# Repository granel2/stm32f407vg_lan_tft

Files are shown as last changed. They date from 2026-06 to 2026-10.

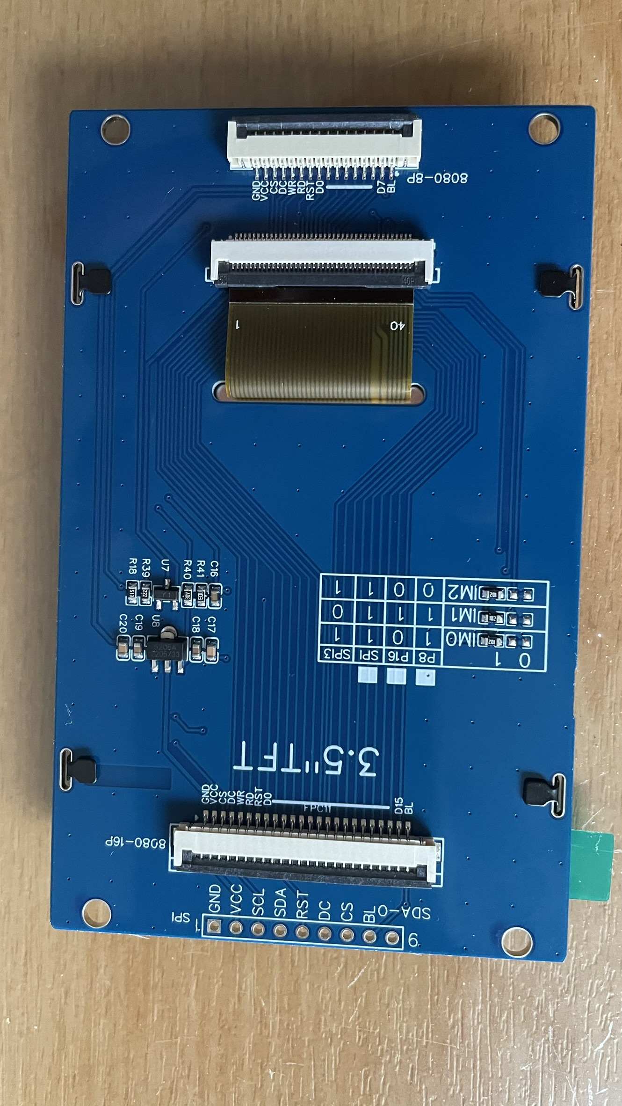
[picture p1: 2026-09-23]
Display/docs/tft_board_back.jpg

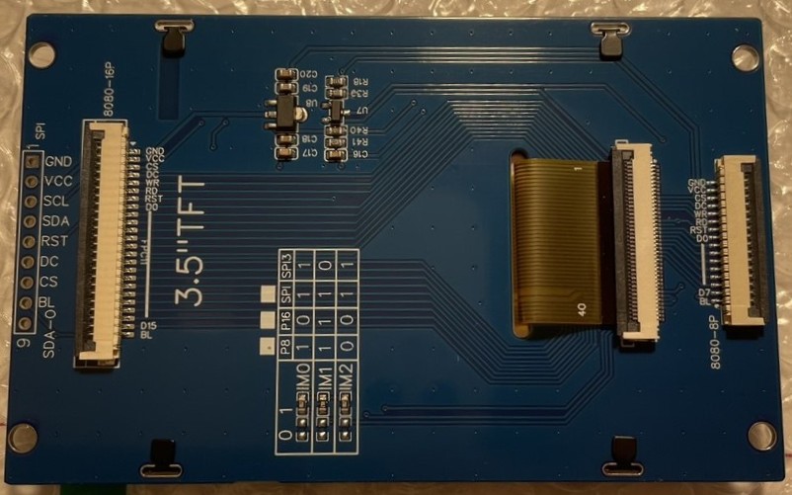
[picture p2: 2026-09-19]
Display/docs/display_3.5_tft_front.jpg

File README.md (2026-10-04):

# stm32f407vg_lan_tft

STM32F407VGT6 + LAN8720 (Ethernet, lwIP, DHCP, TCP-клиент) + 3.5" TFT-дисплей.
Проект основан на `stm32f407vg_lan_v1` (Ethernet-часть отлажена и работает, см. `docs/`).

## Структура

| Путь | Что это |
|---|---|
| `Core/Inc`, `Core/Src`, `Core/Startup` | Ethernet/lwIP-часть: HAL MSP, прерывания, lwIP-порт (`ethernetif.c`), TCP-клиент, `main.c` |
| `Display/` | Весь дисплейный модуль, обособлен от Ethernet-кода — см. `Display/README.md` |
| `Config/` | Постоянные настройки (сервер/имя/статический IP) + веб-страница настройки `http://<IP модуля>/` (порт 80) + TCP-конфигуратор на порту 7000 — см. `Config/README.md` |
| `Keypad/` | Приём пакетов от модуля клавиатуры 4×4 (ATmega328P) на SV5: I2C1-ведомый `0x30`, на регистрах — см. `Keypad/README.md` |
| `Drivers/` | STM32Cube HAL F4 V1.28.3, CMSIS, драйвер PHY lan8742 |
| `Middlewares/Third_Party/LwIP` | lwIP (NO_SYS=1) |
| `CMakeLists.txt`, `CMakePresets.json`, `toolchain-arm-none-eabi.cmake`, `linker_script.ld` | Сборка |
| `stm32f407vg_lan_tft.ioc`, `.mxproject` | Проект CubeMX — **только справочно**: ETH и часть периферии добавлены руками, перегенерировать код из CubeMX нельзя |
| `hardware/` | `BOARD.md` — выжимка по плате (разъёмы, питание, выводы); схема и плата (Eagle) `f407.sch`/`f407.brd`, распечатка схемы `f407_schematic_A3.pdf` |
| `docs/` | История отладки Ethernet (`PROJECT_GUIDE.md`), аппаратный фикс LAN8720 (`CHANGES_LAN8720.md`), заметки по сборке, даташиты |
| `stm32f407vg_lan_tft.code-workspace` | Workspace VS Code |

## Целевая платформа

- MCU STM32F407VGT6 (LQFP100), HSE 25 MHz, SYSCLK 160 MHz, APB1 40 MHz, APB2 80 MHz
- USART1 (PA9/PA10) и USART3 (PD8/PD9), 921600 baud — отладочный лог
- ETH RMII → LAN8720 (REFCLK на PA1), см. `docs/CHANGES_LAN8720.md` про обязательный резистор 1 кОм на страпе nINTSEL
- LED: PB4, PB5, PD0, PD1, PD4, PD7

## Сборка

Требуется `arm-none-eabi-gcc`, `cmake ≥ 3.24`, `ninja`, `openocd` в `PATH`.

```powershell
cmake --preset default          # конфигурация (build/, Ninja, toolchain-файл)
cmake --build --preset default  # сборка → build/stm32f407vg_lan_tft.{elf,bin,hex,map}
```

В VS Code: `Terminal → Run Task → CMake: Configure`, затем `CMake: Build` (Ctrl+Shift+B).

## Прошивка и отладка

- Задача VS Code `Flash STM32F407VG` — `scripts/flash-progress.ps1`, обёртка над той же
  последовательностью OpenOCD (`init` → `reset halt` → `mass_erase` → `write_image` →
  `verify_image` → `reset run`; ST-Link). Команда `program … verify` в текущей сборке
  OpenOCD глючит — подробности в `docs/PROJECT_GUIDE.md`, поэтому по-прежнему используется
  явная последовательность, а не `program`. Обёртка добавляет текстовую шкалу прогресса
  в терминал (OpenOCD сам не печатает прогресс во время записи, только итог) — она
  ориентируется на время (калибровка ~20 с под текущий размер прошивки), реальный вывод
  OpenOCD печатается полностью после завершения.
- Есть составная задача `Build + Flash` (сборка + прошивка одной командой,
  `.vscode/tasks.json`); запускать через `Ctrl+Shift+P` → `Tasks: Run Task`. `F5`
  (Run and Debug) тоже сначала пересобирает — см. `preLaunchTask` в `launch.json`.
  Личные горячие клавиши на конкретные задачи — дело вкуса, настраиваются в
  `keybindings.json` пользователя (VS Code не поддерживает keybindings, привязанные
  к конкретному проекту, поэтому в репозитории их нет).
- Отладка: конфигурация `Cortex Debug (ST-Link)` в `launch.json` (расширение `marus25.cortex-debug`).

## TFT 3.5" ST7796S (320×480), 4-wire SPI

Весь дисплейный код, схема подключения и фото платы вынесены в **[`Display/`](Display/)** —
отдельный, не зависящий от Ethernet-части модуль, чтобы его можно было дорабатывать
(шрифты, экран сетевого статуса) не трогая `main.c`. Подробности, распиновка и порядок
включения — в [`Display/README.md`](Display/README.md).

Коротко: SPI3 (PC10/PC11/PC12, 20 МГц) + CS/DC/RST/BL на PA15/PD6/PD5/PC7, всего 2 разъёма
(SV4 + SV1). При старте `TFT_App_SmokeTest()` заливает экран R/G/B (время кадра — в USART1) и рисует тест-паттерн, затем показывает
рабочий экран статуса сети (IP/DHCP/TCP/последнее сообщение от сервера).

## Что дальше

Актуальные чек-листы — в README каждого модуля: [`Display/README.md`](Display/README.md)
(дисплей, шрифт, многостраничный экран) и [`Config/README.md`](Config/README.md)
(TCP-конфигуратор, статический IP).

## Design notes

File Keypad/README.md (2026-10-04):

# Keypad — приём пакетов от модуля клавиатуры 4×4

Модуль клавиатуры (ATmega328P, проект `..\..\atm328p_keyboard`) подключается к разъёму
**SV5** и сам передаёт пакеты по I²C. Эта плата — **ведомый `0x30`** на I2C1, только
принимает. Опроса и таймера нет: в простое процессор модулем не занят.

## Подключение

| SV5 | Сигнал | Модуль клавиатуры (Pro Mini) |
|---|---|---|
| 1 | GND | GND |
| 2 | +5V | RAW |
| 3 | SDA PB7 | A4 |
| 4 | SCL PB6 | A5 |

Подтяжки 4,7 кОм к +5 В стоят на модуле; на этой плате подтяжек нет, внутренние выключены
(PB6/PB7 — FT). ES0182 2.10.6: при VDD = 3,3 В шина допустима до 5,14 В (у модуля 5,02 В).
Скорость 100 кГц задаёт модуль.

## Протокол

`Inc/kbd_protocol.h` — **копия** `atm328p_keyboard/include/protocol.h`, держать одинаковыми.
Кадр: `[тип][seq][N][данные N][CRC-8][хвост '$']`.

- **Подтверждение — ответ на хвост.** ACK байта F4 ставит аппаратно до того, как программа
  его увидит (ES0182 2.10.2), поэтому решение по CRC отдаётся на следующий байт — хвост:
  ACK = пакет принят, NACK = модуль повторит через 10 мс.
- **Срок решения — 8 бит хвоста (~80 мкс).** Удержание SCL у F4 наступает только после ACK
  следующего байта, поэтому прерывание I2C1 с приоритетом **1** (выше ETH 5), CRC
  считается по ходу приёма, по байту CRC — только сравнение. Счётчик `late` в статистике
  должен оставаться 0.
- **После NACK флаг STOPF не ставится** (RM0090), бит ACK возвращается в RXNE отвергнутого
  байта и, для страховки, в `keypad_poll()` при свободной шине.
- **Повтор с тем же seq** (модуль не получил наш ACK) отбрасывается, пропуск seq пишется в лог.
  Пакет `START` (после сброса модуля) начинает нумерацию заново.

## Типы пакетов

| Тип | Данные | Лог (USART1) |
|---|---|---|
| `GROUP` 0x02 | `[причина][символы 0-9, A-D]` | `[kbd] #5 GROUP enter: "1A2B"` |
| `CANCEL` 0x03 | `[причина]` | `[kbd] #6 CANCEL timeout` |
| `KEY` 0x01 | `[бит 7 нажата + ASCII]` — только если модуль собран с `LETTERS_KEY` | `[kbd] #7 KEY A down` |
| `START` 0x04 | `[версия ПО][MCUSR]` | `[kbd] #1 START fw 2, reset cause MCUSR 0x01` |

Причины: 1 `#`, 2 предельная длина (16), 3 пауза (10 с), 4 `*`.
MCUSR: 0x01 питание, 0x02 RESET, 0x04 просадка питания, 0x08 сторожевой таймер.

## Использование

```c
static void on_keypad(const KeypadPacket *p)
{
  if (p->type == KBD_PKT_GROUP && p->data[0] == KBD_END_ENTER)
  {
    /* p->data[1..p->len-1] - набранные символы, p->len - 1 штук */
  }
}
...
keypad_set_handler(on_keypad);
```

Обработчик вызывается из `keypad_poll()` (главный цикл), не из прерывания. После него
пакет в очереди затирается — пароль в памяти не остаётся.

## Страница дисплея «I2C KBD»

Кнопкой страниц (PC6) выбирается страница `I2C KBD 0x30`. На ней по строке на каждый принятый
пакет, новые снизу; когда 18 строк заполнены, список прокручивается. Строки копятся и тогда,
когда открыта другая страница.

В заголовке — адрес STM32 на шине клавиатуры (`I2C KBD 0x30`). Строка под ним — счётчики:
`RX` — сколько раз к этому адресу обратились (передач), `OK` — принятые пакеты,
`ERR` — CRC + оборванные кадры + ошибки шины (BERR/ARLO/OVR). Норма: `RX` = `OK`, `ERR 0`.
`RX 0` при работающем модуле — модуль до STM32 не доходит (проводка, SDA/SCL, подтяжки)
или в модуле не та прошивка (`uarttest` в I²C не пишет).

| Строка | Цвет | Что |
|---|---|---|
| `#12 E 1234567890` | зелёный | GROUP; конец: `E` — `#`, `M` — 16 символов, `T` — пауза, `C` — `*` |
| `#13 CANCEL TIMEOUT` | жёлтый | CANCEL и причина |
| `#1 START FW 2 RST 02` | голубой | сброс модуля, MCUSR |
| `#7 KEY A DOWN` | белый | KEY (модуль собран с `LETTERS_KEY`) |
| `LOST 2`, `CRC 3 LATE 0` | красный | пропуск seq, изменились счётчики ошибок |

При `KEYPAD_LOG_TEXT 0` вместо символов группы — их число.

Следующая страница, `KBD HELP`, — краткая расшифровка этих строк на самом дисплее.

## Листание страниц с клавиатуры

Обработчик в `Core/Src/main.c` (`on_keypad()`): `#` без символов — следующая страница,
1–3 цифры и `#` (`3#`, `12#`) — страница с этим номером (как в индикаторе `n/N`); номер,
которого нет, игнорируется. Всё остальное — обычный ввод: пароли не короче 4 цифр или
начинаются с буквы, с командами не пересекаются. Цифры идут **перед** `#`: модуль
отправляет группу только по `#`.
Кнопка страниц (PC6) работает как раньше.

## Настройки — `Inc/keypad_config.h`

| Параметр | По умолчанию | |
|---|---|---|
| `KEYPAD_IRQ_PRIORITY` | 1 | приоритет I2C1_EV/ER; должен быть выше остальных |
| `KEYPAD_LOG_TEXT` | 1 | 1 — печатать набранное, 0 — только число символов (для паролей) |
| `KEYPAD_QUEUE_LEN` | 8 | пакетов между прерыванием и главным циклом |

## Файлы

| Файл | Что это |
|---|---|
| `Inc/keypad.h`, `Src/keypad.c` | Драйвер I2C1-ведомого на регистрах (HAL I2C в проекте не включён) |
| `Inc/keypad_config.h` | Настройки |
| `Inc/kbd_protocol.h` | Протокол, копия из проекта клавиатуры |
| `Inc/keypad_page.h`, `Src/keypad_page.c` | Страница дисплея «I2C KBD» (вызывается из `Display/Src/tft_app.c`) |

Связь с остальным: `main.c` — `keypad_init()` при старте и `keypad_poll()` в главном
цикле; `stm32f4xx_it.c` — `I2C1_EV_IRQHandler` / `I2C1_ER_IRQHandler`.

## Состояние

Собирается; на железе **не проверено** (2026-10-04). Журнал решений по протоколу —
`atm328p_keyboard/docs/DECISIONS.md`.

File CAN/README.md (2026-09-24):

# CAN — драйвер CAN1

## Железо

| Что | Где |
|---|---|
| Контроллер | bxCAN **CAN1**, PA11 = RX, PA12 = TX (AF9) |
| Трансивер | U3 **TCAN1044V**, STB → R1 10k на GND (всегда активен), VIO = 3V3, VCC = +5V |
| Разъём | **J3** (4 pin): 1 GND, 2 CANL, 3 CANH, 4 +5V |
| Терминатор | R2/R30 2×49.9 Ом (split, 120 Ом) — впаян постоянно: модуль должен стоять **на конце шины** |
| Защита | D4 PESD1CAN |

Подробнее — `hardware/BOARD.md`.

## Файлы

| Файл | Что делает |
|---|---|
| `Inc/can_config.h` | Скорость, режим «только слушать», лог, размер очереди |
| `Inc/can_bus.h`, `Src/can_bus.c` | Драйвер на регистрах bxCAN (HAL CAN в проекте нет) |

## Настройки (`can_config.h`)

| Define | По умолчанию | Что делает |
|---|---|---|
| `CAN_BITRATE_KBPS` | 500 | Скорость; делитель считается от реальной частоты APB1 (40 МГц), точка выборки ~87,5 % |
| `CAN_SILENT` | 0 | 1 = только слушать: модуль не шлёт ACK и ошибки, не передаёт — безопасно для чужой шины |
| `CAN_LOG_MAX_PER_S` | 20 | Сколько принятых кадров в секунду печатать в UART (печать блокирующая) |
| `CAN_STATS_PERIOD_S` | 10 | Сводка раз в N секунд (только если что-то было) |
| `CAN_RX_QUEUE_LEN` | 32 | Очередь между прерыванием и главным циклом |

## Как работает

- `can_bus_init()` при старте: тактирование, ножки, тайминги, фильтр «принимать всё»
  (стандартные и расширенные кадры) в FIFO0, прерывание приёма.
- Прерывание `CAN1_RX0` перекладывает кадры из аппаратного FIFO (3 кадра) в очередь.
- `can_bus_poll()` в главном цикле: печатает кадры в UART, отдаёт каждый в обработчик
  приложения (`can_bus_set_rx_handler()`), сообщает о смене состояния шины.
- `can_bus_send()` кладёт кадр в свободный аппаратный почтовый ящик (их 3) и сразу
  возвращается. **Сейчас прошивка сама ничего не передаёт** — функция есть, вызова нет.
- Bus-off восстанавливается аппаратно (ABOM); автоматический повтор передачи включён.

## Что видно в UART

```
[can] CAN1 up: 500 kbit/s (APB1 40 MHz, presc 5, 16 tq), normal mode
[can] state OFF -> ACTIVE (tec 0 rec 0)
[can] rx 123 [8] 11 22 33 44 55 66 77 88
[can] rx 18FF0102 [4] 01 00 FF 7F        ← расширенный (29-bit) ID
[can] ... 340 more frames not logged      ← если больше CAN_LOG_MAX_PER_S в секунду
[can] 10 s: rx 3520 tx 0 lost 0 | total rx 3520, ACTIVE tec 0 rec 0
```

`lost` — кадры, потерянные из-за переполнения FIFO или очереди.
Если при старте `did not leave init mode` — линия RX держится в доминанте: проверьте
питание +5V трансивера и проводку J3.

## Пример передачи

```c
CanFrame f = { .id = 0x123, .ext = 0, .rtr = 0, .len = 2, .data = { 0xAB, 0xCD } };
if (!can_bus_send(&f)) { /* все 3 ящика заняты или режим CAN_SILENT */ }
```

Без второго узла на шине кадр не получит ACK, контроллер будет повторять его, счётчик
ошибок TEC вырастет, и шина уйдёт в ERROR-PASSIVE — это нормально для одиночного узла.

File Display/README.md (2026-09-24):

# Display — 3.5" ST7796S TFT (320×480), 4-wire SPI

Самодостаточный модуль: весь код и вся документация по дисплею лежат здесь, отдельно
от Ethernet/lwIP-части в `Core/`. Задуман так, чтобы дальнейшую доработку экрана
(новые виджеты, другие экраны) можно было вести, трогая только эту папку — `main.c`
знает только о четырёх функциях (см. «Слои кода» ниже).

## Структура

| Путь | Что это |
|---|---|
| `Inc/st7796s.h`, `Src/st7796s.c` | Низкоуровневый драйвер контроллера ST7796S: init-последовательность, RAMWR/CASET/RASET, заливки, поворот (MADCTL), примитив 7-сегментных цифр, битмап-шрифт 5x7 (`ST7796S_DrawChar`/`DrawString`). Не знает ни о плате, ни о приложении. |
| `Inc/tft_app.h`, `Src/tft_app.c` | Прикладной слой: владеет `hspi3`, настраивает SPI3 и GPIO CS/DC/RST/BL/кнопки, решает, что и когда рисовать (boot-смоук-тест, многостраничный экран статуса). **Это файл для доработки** — новые страницы/виджеты добавлять сюда. |
| `docs/TFT_WIRING.md` | Пины модуля ↔ STM32 ↔ разъёмы платы (SV4 + SV1), проверка перед включением. |
| `Inc/tft_backlight.h`, `Src/tft_backlight.c` | Яркость подсветки: ШИМ на PC7 (TIM3_CH2), уровень в % воспринимаемой яркости (скважность = %²/100). Уровни и приглушение в покое — на веб-странице настроек (`device_config`: `bl_level`, `bl_dim_level`, `bl_dim_min`), применяются сразу. |
| `docs/TFT_3.5_board.md` | Описание платы-адаптера дисплея: разъёмы 40-pin FPC/8080-8P/8080-16P/9-pin SPI, таблица перемычек IM0–IM2, питание (LDO U8, транзистор подсветки U7). |
| `docs/LARGE_DISPLAY_OPTIONS.md` | Какой дисплей максимум можно подключить (до 10,1" 1280×800 с «умным» контроллером), почему 1920×1080 только через Raspberry Pi + браузер. Теория, не реализовано. |
| `docs/display_3.5_tft_front.jpg` | Фото модуля спереди. |
| `docs/tft_board_back.jpg` | Фото платы-адаптера сзади — читаемая ориентация, с таблицей перемычек IM. |

## Слои кода

```
main.c
  │  TFT_App_GPIO_Init()                        — сразу после MX_GPIO_Init(), до всего остального
  │  TFT_App_SPI3_Init()                       ─┐  один раз при старте, до MX_LWIP_Init() —
  │  TFT_App_SmokeTest()                       ─┘  блокирующие HAL_Delay() не должны стопорить DHCP/ETH
  │  TFT_App_AlivePoll(ip_str, link_up, ip_src, tcp)   — каждую итерацию while(1), сам ограничивает себя 1 Гц;
  │                                               main.c передаёт то же состояние netif/TCP, что уже
  │                                               считает для UART-heartbeat
  ▼
Display/Src/tft_app.c  (прикладной слой, PC10/11/12 + PA15/PC7/PD5/PD6)
  ▼
Display/Src/st7796s.c  (низкоуровневый драйвер контроллера)
```

`Debug_Print()` (лог в USART1) остался в `main.c`, объявлен в `main.h` — им пользуются
и Ethernet-код, и `tft_app.c`.

## Подключение — коротко

9-контактный разъём SPI на плате-адаптере → плата f407, всего **2 разъёма** (SV4 + SV1) —
DC/RST/BL сгруппированы на SV1, чтобы не тянуть провода к третьему разъёму
(подробности и проверка перед включением — в [`docs/TFT_WIRING.md`](docs/TFT_WIRING.md)):

| Модуль (9-pin SPI) | STM32 | Разъём платы |
|---|---|---|
| GND | GND | SV4.6 |
| VCC | +5V (если на модуле есть LDO) / +3V3 | SV4.5 / SV2.1 |
| SCL | PC10 SPI3_SCK | SV4.3 |
| SDA | PC12 SPI3_MOSI | SV4.1 |
| SDA-O | PC11 SPI3_MISO | SV4.2 (нужен только для чтения ID) |
| CS | PA15 (GPIO) | SV4.4 |
| BL | PC7 — ШИМ TIM3_CH2, 10 кГц (яркость) | SV1.8 |
| RST | PD5 | SV1.9 |
| DC | PD6 | SV1.10 |
| BTN (кнопка страниц) | PC6, на GND | SV1.7 |

BL/RST/DC/BTN — четыре соседних пина SV1 (7/8/9/10), компактный жгут из четырёх проводов.
PC6/PC7/PD5/PD6 на этой плате подписаны как USART6/USART2 TX-RX (см. `hardware/BOARD.md`),
но ни один из этих UART в прошивке не занят — тот же случай, что и раньше с PB8 под BL. PC6
и PC7 сидят на порту GPIOC, который иначе в проекте не включается — `TFT_App_GPIO_Init()`
сам включает его тактирование. Кнопка — один вывод на PC6, второй на GND (например,
SV4.6); подтяжка к +3.3 В внутренняя, программная (`GPIO_PULLUP`), внешний резистор не
нужен.

**Перемычки IM0/IM1/IM2 на плате-адаптере** должны стоять в положении **SPI (4-wire)**
= `IM2=1, IM1=1, IM0=1`. **Проверено по фото `docs/tft_board_back.jpg`: на этом
экземпляре уже впаяны в `1/1/1`** — режим SPI, перепаивать не требуется. Таблица
режимов — в [`docs/TFT_3.5_board.md`](docs/TFT_3.5_board.md).

## Контроллер: ST7796S (подтверждено косвенно, RDID4 ненадёжен)

Плата-адаптер не подписана; по разводке 40-pin FPC она совпадает и с ST7796S, и с
ILI9488. Драйвер (`st7796s.c`) целиком написан под ST7796S — командный набор
разблокировки (`0xF0/0xC3/0x96`), таблицы гаммы (`0xE0/0xE1`), `COLMOD=0x55`
(16 бит/пиксель). Для настоящего ILI9488 по SPI это, как правило, **не сработает
корректно** — тот обычно не принимает 16bpp по последовательному интерфейсу и требует
18bpp (`COLMOD=0x66`, 3 байта/пиксель), да и часть регистров инициализации у него другая.

На реальном железе `RDID4` вернул мусор (`00 3B CB 00` — не 0/FF, похоже на наводку на
плавающем SDA-O), но **геометрия отрисовалась полностью корректно**: заливки R/G/B/белый
менялись без искажений, тест-паттерн ровный во всех 4 поворотах, финальный экран (полосы +
шахматка + серый блок со счётчиками) — всё как задумано по форме и расположению. (Отдельно
от этого была найдена и исправлена инверсия цветов — см. ниже; на геометрию/паттерн она не
влияла, поэтому вывод о совместимости с ST7796S по-прежнему в силе.) Если бы чип был
настоящим ILI9488, при 16bpp/чужой гамме картинка почти наверняка была бы битой —
раз она чистая, контроллер ST7796S-совместим. `RDID4` можно перепроверить (перепаять/
прозвонить SDA-O — PC11/SV4.2) при желании, но для работы это не требуется.

## Многостраничный экран статуса

После смоук-теста (заливки + 4 поворота тест-паттерна) экран переключается на рабочий,
многостраничный режим. Кнопка на **SV1.7/PC6** (на GND, внутренняя подтяжка) листает
страницы по кругу; текущая страница видна в правом верхнем углу как `n/N`. Каждая
страница — свой заголовок (жёлтым) + `n/N`; heartbeat-квадратик внизу слева мигает
раз в секунду **на любой странице** — по нему видно, что прошивка жива, даже если вы
сейчас смотрите не на ту страницу, где что-то могло зависнуть.

| # | Страница | Что показывает |
|---|---|---|
| 1/4 | **SETUP** | `LINK / DHCP / IP / SERVER / TCP / UPTIME / FRAME / CHIP ID / NAME` |
| 2/4 | **RECEIVED** | Последнее сообщение от TCP-сервера целиком, многострочно |
| 3/4 | **REMOTE** | Приборы с данными от сервера: 2 стрелочных, 3 цифровых, 2 ползунка, 4 лампы — модуль [`Panel/`](../Panel/README.md) |
| 4/4 | **LOCAL** | Локальные приборы и органы управления: 3 столбика, стрелочный, цифровой, 4 кнопки, ползунок — [`Panel/`](../Panel/README.md) |

Пока реальных данных нет, REMOTE/LOCAL показывают **демо-анимацию** (внизу `SERVER: DEMO` /
`LOCAL: DEMO`). Добавить ещё страницу: завести `TFT_PAGE_XXX` в `enum TFT_Page` (перед `TFT_PAGE_COUNT`,
он посчитается сам), написать `draw_page_xxx_static(void)`, добавить `case` в
`draw_page_static()`; если странице нужны поля, обновляющиеся раз в секунду — добавить
`if (s_page == TFT_PAGE_XXX) { ... }` в `TFT_App_AlivePoll()` рядом с уже существующим
блоком для SETUP.

### Кнопка переключения страниц

PC6 (SV1.7), активный уровень низкий, подтяжка к +3.3 В — внутренняя программная
(`GPIO_PULLUP` в `TFT_App_GPIO_Init()`), внешний резистор не нужен: один вывод кнопки на
PC6, второй на GND. Антидребезг — по времени (`BTN_DEBOUNCE_MS` = 50 мс: изменение
состояния принимается не чаще этого интервала), проверяется **каждую итерацию** главного
цикла (а не раз в секунду) — переключение страницы происходит мгновенно по нажатию, без
задержки до 1 с.

### Страница SETUP

`LINK/DHCP/IP/SERVER/TCP/UPTIME/FRAME/CHIP ID/NAME`, метка слева/значение справа, шрифт
5x7. `SERVER:`/`FRAME:`/`CHIP ID:`/`NAME:` статичны — рисуются один раз при возврате на
страницу. `SERVER:` и `NAME:` теперь приходят из `Config/Inc/device_config.h` (постоянные
настройки, см. `Config/README.md`) — `main.c` читает их через `device_config_get()` и
передаёт строками в `TFT_App_SmokeTest()`, чтобы `Display/` по-прежнему не подключал ни
lwIP-, ни Config-заголовки напрямую. После сохранения новых настроек (веб-страница или
TCP-конфигуратор) `main.c` замечает смену `device_config_revision()` и вызывает
`TFT_App_UpdateInfo()` — `SERVER:`/`NAME:` обновляются на экране сразу, без перезагрузки
(если SETUP сейчас не на экране — при следующем возврате на неё). Остальные поля обновляет `TFT_App_AlivePoll()` раз
в секунду, **только пока активна эта страница** — вызывается из `main.c` там же, где уже
считается `has_ip`/состояние TCP для UART-heartbeat, никакого дублирования логики.
Каждое значение рисуется в поле фиксированной ширины (`STATUS_VALUE_CHARS`), так что
более короткое новое значение полностью перекрывает старое.

**`NAME:`** — имя/метка устройства, настраивается по сети без пересборки прошивки: через
веб-страницу `http://<IP модуля>/` или TCP-конфигуратор (`SET NAME ...`), см.
`Config/README.md`.

**`CHIP ID:`** — **CRC32** от уникального 96-битного заводского номера чипа (STM32F4:
OTP-регистр по фиксированному адресу `0x1FFF7A10`, см. RM0090 §39.1 «Unique device ID
register», `stm32_uid_word()`/`stm32_uid_crc32()` в `tft_app.c` — обычное чтение памяти,
без периферии/инициализации). Статичен, как `SERVER:`/`FRAME:` — заводской номер не
меняется в рантайме.

Показывается именно CRC32 (8 hex-символов, влезает в одну строку), а не все 24 символа
сырого ID: во-первых, не влезает в 16-символьное поле значения (пришлось бы разбивать на
2 строки); во-вторых, часть 96 бит (поле `LOT_NUM` — номер производственной партии) у ST
часто кодируется как читаемый десятичный/ASCII-подобный текст, а не как случайные биты
(отсюда и вопрос — на экране был подозрительно «ровный» номер без единой буквы A-F), так
что CRC32 заодно превращает его в равномерно распределённое короткое значение, удобное
как компактный идентификатор платы. Использован стандартный отражённый CRC-32 (полином
`0xEDB88320`, тот же алгоритм, что `zlib.crc32()`/`binascii.crc32()` в Python/`cksum`) —
можно независимо перепроверить по 24-значному сырому ID, который печатается в лог USART1
при старте вместе с CRC32: `[tft] chip UID = <24 hex> (CRC32 <8 hex>)`.

Для идентификации платы на сервере используйте именно этот CRC32 (или сырой 96-битный
ID из лога), а не MAC-адрес: он сейчас жёстко прошит одинаковым для всех плат с этой
прошивкой (`ETH_MAC_ADDR0..5` в `Core/Inc/stm32f4xx_hal_conf.h`, сейчас
`02:00:00:00:00:01`) — при нескольких платах в одной сети будет MAC-коллизия, если не
поменять байт вручную под каждую плату. IMEI не применим — на плате нет сотового модема.

### Страница RECEIVED

Последнее, что реально пришло от сервера по TCP — **целиком**, а не только первая строка:
разбивка по переносам строк сервера (CR/LF), каждая строка при необходимости ещё и
заворачивается по ширине экрана (`STATUS_RX_CHARS` символов) — до `STATUS_RX_MAX_ROWS`
(сейчас 18) строк; всё, что не поместилось, отбрасывается. Текст **не гаснет сам** (в
отличие от прежней версии на общем экране) — держится, пока не придёт новое сообщение;
страница целиком отдана этому, автогашение через 2 с больше не нужно. Если новое
сообщение короче предыдущего — лишние строки снизу гасятся отдельно (`s_rx_rows_used`),
не остаётся «хвостов». Байты вне алфавита шрифта (буквы/цифры/`. : - / ! #`, без
кириллицы) рисуются пустыми клетками — не мусором.

Сообщение хранится в `s_last_msg` (сырой текст, ещё не завёрнутый), поэтому переключение
на эту страницу всегда показывает последнее пришедшее, даже если оно прилетело, пока была
открыта другая страница (`TFT_App_ShowReceived()` перерисовывает страницу немедленно,
только если она активна; иначе просто запоминает — отрисовка произойдёт при следующем
переключении сюда). Буфер под приём: `LAST_RX_SNAPSHOT_SIZE` в `tcp_echo_client.c` (220
байт) и `rx_snapshot` в `main.c` (тот же размер) — сообщение с кириллицей в UTF-8
(2 байта/символ) уже занимает ~100 байт, оставлен запас.

Список меток и позиций для всех страниц — в начале `tft_app.c` (`STATUS_Y_*`,
`STATUS_LABEL_X`, `STATUS_VALUE_X`).

## Что дальше

- [x] Аппаратный тест (init, ID, заливка, паттерн, live-счётчики) — подтверждено на
      реальном железе, геометрия/паттерн корректны
- [x] Дисплейный код выделен в самостоятельный модуль (`Display/`)
- [x] Контроллер подтверждён как ST7796S-совместимый (косвенно, по корректной геометрии)
- [x] Шрифт — битмап 5x7 (`ST7796S_DrawChar`/`ST7796S_DrawString` в `st7796s.c`):
      пробел, `. : - / ! #`, цифры, заглавные и строчные латинские буквы; неизвестный
      символ (в т.ч. кириллица) рисуется пустой клеткой, а не мусором
- [x] Экран сетевого статуса (IP, link, DHCP, TCP, последнее TCP-сообщение) — см. раздел выше
- [x] **Инверсия цветов** — на реальном железе все цвета выходили ровно инвертированными
      (жёлтый↔синий, циан↔красный, белый фон вместо чёрного). Исправлено:
      `CMD_INVON` → `CMD_INVOFF` в `ST7796S_Init()` (`st7796s.c`)
- [x] **Обрезка нижних строк экрана статуса** — после цикла проверки 4 поворотов
      (`TFT_App_SmokeTest()`, шаг 3) ориентация оставалась в `rotation=3`
      (`tft_height=320`, а не 480), и экран статуса рисовался поверх этого без сброса —
      всё ниже y≈320 (строка `LAST MSG:` и heartbeat-квадрат) обрезалось или пропадало.
      Исправлено: явный `ST7796S_SetRotation(0U)` перед `status_draw_static()`
- [x] Все три фикса выше (инверсия, шрифт, сброс поворота) проверены на реальном
      железе одним фото: правильные цвета, полная читаемая строка `Hello Module #49 ! I
      am` в `LAST MSG:` (строчные буквы и `#`/`!` отрисовались), heartbeat-квадрат на
      месте, экран не обрезан. Кратковременный «повёрнутый на 90°» вид, который
      наблюдался сразу после прошивки, — это самопроверка `TFT_App_SmokeTest()`,
      прогоняющая тест-паттерн во всех 4 поворотах в первые ~5 с после сброса; не баг
- [x] Полный многострочный ответ сервера в `LAST MSG:` (перенос по строкам + по ширине
      экрана) — подтверждено на реальном железе, всё сообщение видно целиком
- [x] Многостраничный экран (SETUP / RECEIVED / RESERVED), переключение кнопкой на
      PC6/SV1.7 (антидребезг по времени, проверка каждую итерацию цикла — переключение
      мгновенное). RECEIVED теперь занимает всю страницу (до 18 строк вместо 7) и не
      гаснет сама по таймеру — держится до следующего сообщения. Heartbeat-квадрат общий
      для всех страниц. Кнопка и переключение всех трёх страниц подтверждены на
      реальном железе
- [x] Уникальный ID чипа на SETUP — CRC32 (8 hex) от 96-битного заводского номера
      (OTP `0x1FFF7A10`); рекомендован для идентификации на сервере вместо MAC (сейчас
      захардкожен одинаковым для всех плат) —
      собрано и прошито, визуальная проверка на реальном железе — ожидается
- [ ] Содержимое страницы 3 (сейчас заглушка «RESERVED») и любые новые страницы —
      по мере необходимости, механизм уже готов (см. «Многостраничный экран статуса» выше)
- [ ] Кириллица / больше пунктуации в шрифте, если понадобится другой текст

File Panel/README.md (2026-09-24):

# Panel — страницы приборов на TFT

Дополнение к экрану [`Display/`](../Display/README.md): две страницы с кнопками, лампами,
цифровыми и стрелочными приборами, ползунками и столбиками. Листаются той же кнопкой
(PC6), что и SETUP / RECEIVED: **SETUP → RECEIVED → REMOTE → LOCAL**.

Сейчас это **примеры изображения**: раскладка и типы приборов — образец, значения
анимирует встроенное демо. Что именно показывать и откуда брать данные — решается дальше
(формат данных от сервера, локальные входы, органы управления — см. «Что решить»).

## Страницы

**REMOTE** — значения, приходящие с удалённого сервера:

```
┌──────────────────────────────────────┐
│ REMOTE                          3/4  │
│ ┌─PRESSURE─────┐ ┌─SPEED────────┐    │   2 стрелочных прибора
│ │   ╭──────╮   │ │   ╭──────╮   │    │   (шкала 240°, зоны норма/внимание/авария)
│ │  ╱   ╲    ╲  │ │  ╱    ╱   ╲  │    │
│ │    5.3 BAR   │ │   1500 RPM   │    │
│ └──────────────┘ └──────────────┘    │
│ [TEMP  C][FLOW L/M][VOLT   V]        │   3 цифровых индикатора
│ [VALVE 1 ════●──────     35 %]       │   2 ползунка
│ [VALVE 2 ══════════●──   80 %]       │
│ (●)PUMP  (●)FAN  (○)HEAT  (○)ALARM   │   4 лампы
│ ■  SERVER: DEMO                      │   ■ = heartbeat (tft_app.c)
└──────────────────────────────────────┘
```

**LOCAL** — собственные входы модуля и органы управления:

```
┌──────────────────────────────────────┐
│ LOCAL                           4/4  │
│ ┌AIN1┐┌AIN2┐┌AIN3┐ ┌─SUPPLY───────┐  │   3 столбика + стрелочный
│ │ ▓▓ ││    ││ ▓▓ │ │   ╭──────╮   │  │
│ │ ▓▓ ││ ▓▓ ││ ▓▓ │ │    24.0 V    │  │
│ │1.8V││0.9V││2.5V│ ├─UPTIME──── S─┤  │   цифровой (реальный аптайм)
│ └────┘└────┘└────┘ │      1234    │  │
│ [ RELAY 1 ] [ RELAY 2 ]              │   4 кнопки (залиты = включены)
│ [  START  ] [  STOP   ]              │
│ [SETPOINT ═══════●────   62.5 %]     │   ползунок уставки
│ ■  LOCAL: DEMO                       │
└──────────────────────────────────────┘
```

## Каналы

Каждый прибор показывает один **канал** (0…31). Значение канала — целое число в
**десятых** (`237` = 23,7). Карта каналов — в шапке [`Src/panel_pages.c`](Src/panel_pages.c):

| Страница | Каналы |
|---|---|
| REMOTE | 0 PRESSURE bar, 1 SPEED rpm, 2 TEMP °C, 3 FLOW л/мин, 4 VOLT В, 5–6 VALVE 1/2 %, 7–10 лампы PUMP/FAN/HEAT/ALARM (0/1) |
| LOCAL | 16–18 AIN1–3 В, 19 SUPPLY В, 20 UPTIME с (**реальный**), 21–24 кнопки RELAY 1/2, START, STOP (0/1), 25 SETPOINT % |

Реальные данные подаются одним вызовом:
```c
Panel_SetChannel(0, 53);   /* PRESSURE = 5.3 bar */
```
После первого такого вызова демо перестаёт трогать этот канал (остальные продолжают
анимироваться). Демо целиком выключается `#define PANEL_DEMO 0` (в `panel.h` или
`-DPANEL_DEMO=0` в CMake).

## Как добавить / изменить прибор

Страница — это таблица в [`Src/panel_pages.c`](Src/panel_pages.c), одна строка на прибор:

```c
/* type       x    y    w    h   label       unit   min   max  warn alarm dec ch color */
{ W_GAUGE,   10,  50, 145, 140, "PRESSURE", "BAR",    0,  100,   70,   85, 1,  0, 0 },
```

- `min/max/warn/alarm` — тоже в десятых; `warn` — жёлтый, `alarm` — красный; `OFF` — без порога.
- `dec` — знаков после точки на экране (0 или 1).
- Типы: `W_GAUGE` (стрелочный), `W_DIGITAL` (цифровой), `W_SLIDER` (ползунок), `W_VBAR`
  (столбик), `W_LAMP` (лампа), `W_BUTTON` (кнопка).
- Рабочая область: y = 50…428 (выше — заголовок, внизу слева — heartbeat-квадрат 40×40 в (20, 434)).
- Шрифт — 5×7 из драйвера: цифры, латиница, `. : - / ! # % + = < >`. Кириллицы нет.

## Файлы

| Файл | Что это |
|---|---|
| `Inc/panel.h` | Публичный API: `Panel_DrawPage()`, `Panel_Poll()`, `Panel_SetChannel()`. |
| `Inc/gfx.h`, `Src/gfx.c` | Графика поверх `ST7796S_FillRect()`: линии с толщиной, окружности, дуги, скруглённые прямоугольники, текст по центру. Только целочисленная математика (таблица синусов), без libm и float. |
| `Src/panel.c` | Движок: рисует статическую часть прибора один раз, затем перерисовывает только изменившееся (стрелку, цифры, бегунок). |
| `Src/panel_pages.c` | Раскладка обеих страниц + демо-данные + реальный аптайм. |
| `Src/panel_internal.h` | Описание прибора (`Widget`), общее для `panel.c` и `panel_pages.c`. |

Связь с остальным: `Display/Src/tft_app.c` вызывает `Panel_DrawPage()` при переходе на
страницу и `Panel_Poll()` в каждом проходе главного цикла, пока страница на экране.
Panel использует из `Display/` только драйвер `st7796s.h`.

## Производительность (замерено на плате, SPI 10 МГц)

| Действие | Время |
|---|---|
| Полная отрисовка страницы (при переключении) | REMOTE ~650 мс, LOCAL ~610 мс |
| Одно обновление: стрелка, цифры, ползунок, лампа | 1–10 мс |
| Одно обновление: кнопка (меняет состояние только при нажатии) | ~24 мс |

`Panel_Poll()` перерисовывает **не больше одного прибора за вызов**, так что Ethernet не
блокируется надолго. Времена в таблице сняты на 10 МГц; сейчас SPI3 работает на 20 МГц
(потолок для SPI3), так что они примерно вдвое меньше. Заливки от 256 пикселей идут через
DMA (DMA1 Stream5) и не держат процессор; мелкие заливки (текст, тонкие линии) по-прежнему
блокирующие — для них настройка DMA дороже самой передачи.

## Что решить (открытые вопросы)

1. **Формат данных от сервера** для REMOTE — предложение: строки `P1=37.5;SW2=1;LVL3=64`
   → `Panel_SetChannel()`.
2. **Органы управления** на LOCAL: сенсорный дисплей (XPT2046/FT6236 на том же SPI),
   физические кнопки/энкодер на свободных выводах, или только через веб-страницу.
   У текущего дисплея сенсора нет, физическая кнопка одна (листает страницы).
3. **Локальные сигналы**: сколько аналоговых входов (диапазон), дискретных входов,
   выходов (реле) — от этого зависят выводы платы и раскладка LOCAL.
4. **Состав приборов** на каждой странице.

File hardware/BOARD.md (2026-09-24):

# Плата f407 — выжимка из `f407.sch` / `f407.brd` (Eagle 9.6.2)

Двухслойная плата 85.4 × 46.1 мм, 2 крепёжных отверстия Ø3.2 (15.6, 6.5) и (69.6, 39.5).
Полигон только один — `+3V3` на нижнем слое; сплошного GND-полигона нет, земля разведена дорожками.
Правила: 6 mil дорожка/зазор, via 0.25 мм. Все SMD-компоненты силовой части (IC1, IC2, L1, D1, D2) — снизу; МК, PHY, CAN, разъёмы, светодиоды — сверху.

## Питание

```
J2 (+12V in) ─ D1 ─ IC1 MC34063 (buck, L1 220 µH, R14 0.27 Ω → Ipk ≈ 1.1 A, ОС R13 30k / R11 10k → 5.0 V) ─ +5V ─ IC2 AMS1117-3.3 ─ +3V3
                                                     C15 = предохранитель 500 mA на +5V
```
- `+5V` питает: AMS1117, TCAN1044 (VCC), выведен на SV3.10, SV4.5, SV5.2, J3.4.
- `+3V3` питает STM32, LAN8720 (VDD1A/VDD2A/VDDIO), TCAN VIO, магнетику J1; выведен только на SV2.1.
- **PB1 = ADC12_IN9** — делитель R33 7.5k / R34 1k с входа +12V (до D1): `Vin = Vadc × 8.5` (12 V → 1.41 V, шкала до ~28 V). Готовый монитор входного напряжения.
- Бюджет 5V-шины ограничен MC34063 (~0.5 A) и предохранителем 500 mA. Плата (МК 160 MHz + PHY + LED) ≈ 200–250 mA; подсветка 3.5" TFT ≈ 100–150 mA — укладывается, но с небольшим запасом.

## МК STM32F407VGT6 (U1, LQFP100)

HSE 25 MHz (XTAL1, C7/C8 27 pF), BOOT0 → R4 10k на GND, NRST → R5 10k. SWD на SV2. Задействованные выводы:

| Вывод | Сигнал | Куда |
|---|---|---|
| PA0, PA3 | ADC123_IN0/IN3 | SV1.1, SV1.2 (через R35/R36 1k) |
| PA1 | LAN_REFCLKO (50 MHz RMII REF_CLK) | U2 NINT/REFCLKO, R22 4.7k |
| PA2 / PC1 | LAN_MDIO / LAN_MDC | U2 |
| PA4, PA5 | DAC_OUT1/2 | SV1.5, SV1.6 |
| PA7 | LAN_CRS_DV | U2 (+R24 4.7k страп MODE2) |
| PA9 / PA10 | USART1 TX/RX | SV3.5 / SV3.4 |
| PA11 / PA12 | CAN1 RX/TX | U3 TCAN1044V → J3 |
| PA13 / PA14 / PB3 | SWDIO / SWCLK / SWO | SV2 |
| PA15, PC10, PC11, PC12 | SPI3 NSS / SCK / MISO / MOSI | SV4 |
| PB1 | ADC12_IN9 — монитор +12V | R33/R34 |
| PB4, PB5, PD0, PD1, PD4, PD7 | LED7, LED8, LED3, LED4, LED5, LED6 | 1k → LED |
| PB6 / PB7 | I2C1 SCL / SDA | SV5.4 / SV5.3 |
| PB8, PB9 | RPM1 / RPM2 (TIM4 CH3/CH4 или EXTI) | SV1.3, SV1.4 |
| PB10 | LAN_NRST | U2 NRST, R3 10k pull-up |
| PB11, PB12, PB13 | LAN TXEN / TXD0 / TXD1 | U2 |
| PC2, PC3 | TEMP1/TEMP2 — 1-Wire для DS18B20, pull-up 2.2k к +5V (FT-выводы) | SV3.9, SV3.7 |
| PC4, PC5 | LAN RXD0 / RXD1 | U2 (+R25/R26 страпы MODE0/1) |
| PC6 / PC7 | USART6 TX/RX | SV1.7 / SV1.8 |
| PD5 / PD6 | USART2 TX/RX | SV1.9 / SV1.10 |
| PD8 / PD9 | USART3 TX/RX | SV3.1 / SV3.3 |

Свободные и не выведенные на разъёмы: PA6, PA8 (MCO1, см. main.c), PB0, PB2, PB14, PB15, PC0, PC8, PC9, PC13–15, PD2, PD3, PD10–15, PE0–PE15.
DS18B20 на SV3: питание +5V (SV3.10), GND (SV3.8/6/2), данные TEMP1/TEMP2 — open-drain 1-Wire, подтяжка к +5V допустима, т.к. PC2/PC3 5V-tolerant.

## Разъёмы (положение на плате, вид сверху)

**SV2** — SWD, 2×3, левый верх (5.1, 39.4)
`1 +3V3 | 2 SWDIO | 3 GND | 4 SWCLK | 5 GND | 6 SWO`

**SV4** — SPI3, 2×3, левый край (5.1, 26.7) — **разъём дисплея**
`1 MOSI PC12 | 2 MISO PC11 | 3 SCK PC10 | 4 NSS PA15 | 5 +5V | 6 GND`

**SV5** — I2C1, 1×4, нижний край (23.5, 3.8)
`1 GND | 2 +5V | 3 SDA PB7 | 4 SCL PB6`

**SV1** — 2×5, верхний край (39.7, 40.6)
`1 PA0 | 2 PA3 | 3 PB8 | 4 PB9 | 5 PA4 | 6 PA5 | 7 PC6 | 8 PC7 | 9 PD5 | 10 PD6` (питания нет)

**SV3** — UART, 2×5, верхний край (21.9, 40.6)
`1 TXD3 | 2 GND | 3 RXD3 | 4 RXD1 | 5 TXD1 | 6 GND | 7 TEMP2 | 8 GND | 9 TEMP1 | 10 +5V`

**J1** HR911105A RJ45 с магнетикой (правый низ), LED: зелёный ← R12 1k / U2 LED2, жёлтый ← U2 LED1 / R15 1k.
**J2** +12V вход (правый верх), **J3** CAN1 4-pin (левый низ: GND, CANL, CANH, +5V), D4 PESD1CAN, R2/R30 2×49.9 Ω — split-терминатор 120 Ω впаян постоянно (узел должен быть на конце шины). Драйвер в прошивке — [`../CAN/`](../CAN/README.md) (CAN1, PA11/PA12).

## LAN8720 (U2, QFN24)

Кварц XTAL2 25 MHz, RMII, REF_CLK берётся с NINT/REFCLKO (PA1). Страпы: R22 (REFCLKO) 4.7k, R24/R25/R26 (MODE2..0) 4.7k, R37 10k на LED2/nINTSEL — про необходимость дополнительного 1k на GND см. `../docs/CHANGES_LAN8720.md`. RBIAS R20 10k на GND (по даташиту должно быть 12.1k ±1 % — стоит проверить номинал), PHYAD0: R23 4.7k на GND → адрес PHY = 0. VDDCR блокирован C22 100n + C23 22µ.
CAN: TCAN1044V STB → R1 10k на GND (нормальный режим постоянно), VIO = 3V3.

## Что это значит для TFT

Подробная распиновка и код — в [`../Display/`](../Display/README.md). Коротко:

- SPI-сигналы и CS — все на одном разъёме SV4 вместе с GND и +5V.
- DC/RST/BL/кнопка страниц — четыре соседних пина SV1 (PD6/PD5/PC7/PC6, SV1.10/SV1.9/SV1.8/
  SV1.7). SV5 в разводке TFT не используется. PC6/PC7/PD5/PD6 здесь подписаны как
  USART6/USART2 TX-RX, но в прошивке не заняты (используются только USART1 и USART3).
- VCC дисплея: **+5V с SV4.5** — на модуле есть свой стабилизатор (U8, SOT-23-3, маркировка
  6206A = Torex XC6206P332MR или клон, фикс. 3.3 В, подтверждено визуально); если бы модуль
  был чисто 3.3-вольтовый — брать +3V3 с SV2.1, но в данном случае это не требуется.
  Логика ST7796S 3.3 V, уровни от STM32 подходят.

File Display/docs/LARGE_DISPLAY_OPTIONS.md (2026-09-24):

# Большой дисплей: что возможно на этой плате (заметка, 2026-09-24)

Теоретический разбор, ничего не заказано и не реализовано. Сейчас стоит ST7796S 3,5"
320×480 по SPI3 (разъём SV4) — см. [`TFT_WIRING.md`](TFT_WIRING.md).

## Итог

- **Практический максимум — 10,1" 1024×600 / 1280×800**, но только «умный» дисплей
  со своим графическим контроллером и видеопамятью (RA8876/RA8889, EVE BT817/818,
  UART-HMI DWIN/Nextion).
- Дисплей того же типа, что сейчас (STM32 шлёт каждый пиксель), — около **4", 320×480**.
- **1920×1080 напрямую — невозможно.** Только через отдельный компьютер с браузером
  (Raspberry Pi и т.п.), который показывает страницу модуля.

## Ограничения STM32F407 и платы

| Что | Значение | Следствие |
|---|---|---|
| Видеовыход (LTDC, HDMI, LVDS, MIPI-DSI) | нет (LTDC есть только у F429/F469/F7/H7) | RGB/HDMI-панель не подключить |
| ОЗУ | 192 КБ всего, свободно ~60 КБ | буфер кадра в STM32 не поместится (1080p×16 бит ≈ 4,1 МБ); картинка должна храниться в памяти дисплея |
| Шина к дисплею | только SPI3 на SV4, ~20 МГц макс., реально ~1,2 МБ/с | полный кадр 320×480 = 246 мс (замер); 1080p был бы ~3,5 с на кадр |
| Параллельная шина (FSMC/8080) | на плате нет свободных 13+ выводов | только SPI (или UART) |

## Варианты по нарастанию размера

| Тип | Пример | Размер / разрешение | Как рисует | Скорость |
|---|---|---|---|---|
| Простой SPI (как сейчас) | ST7796S, ILI9488 | 3,5–4", 320×480 | STM32 считает все пиксели | полный кадр ~0,25 с |
| SPI + графический контроллер | RA8875 | 5–7", 800×480 | текст, прямоугольники по командам | мгновенно для простой графики |
| SPI + контроллер с SDRAM | RA8876 / RA8889 | 7–10,1", 1024×600 | то же + хранит картинки | аналогично |
| SPI + EVE | Bridgetek BT817/818 (модули Riverdi) | до 10,1", 1280×800 | графика, шрифты, виджеты, сенсор | плавно, 60 кадров/с |
| UART-панель (HMI) | DWIN DGUS, Nextion | до 10,1", 1024×600 / 1280×800 | экраны рисуются в их редакторе, STM32 шлёт только значения | мгновенно |

Разрешения — по общим сведениям; перед покупкой проверить в даташите конкретного
модуля, что он поддерживает **SPI** (или UART для HMI), а не только RGB/LVDS.

## Что учесть

- **Подключение:** все варианты — к SV4 (SPI + 2–3 управляющих вывода: CS, INT/RST).
  UART-панели нужен свободный UART: USART3 в прошивке инициализирован, но проверить,
  выведен ли он на разъём.
- **Код:** драйвер ST7796S не подходит, для каждого контроллера нужен свой. Меньше всего
  кода — UART-HMI; самая красивая графика — EVE.
- **Питание:** подсветка 7–10" ≈ 0,5–2 А, нужен отдельный источник 5/12 В.
- **Рекомендация для 10":** EVE BT817/818 (1280×800, сенсор) — если важна графика;
  DWIN 10,1" — если нужно меньше кода.

## 1920×1080 через Raspberry Pi

- Модуль уже имеет веб-сервер (порт 80) — добавить страницу `/status` с данными экрана.
- Raspberry Pi (или любой ПК/планшет/Smart TV) с HDMI-монитором 1920×1080 открывает её в
  браузере в режиме киоска (Chromium на весь экран при загрузке). Плату менять не нужно.
- Pi 4/5 — комфортно; Pi 3 (1 ГБ) — справится со страницей статуса, тяжёлые страницы медленно.
  ОС — Raspberry Pi OS 64-bit (Bookworm).
- Разработка для Pi из этой же среды: VS Code + расширение **Remote - SSH** (код, терминал,
  отладка на Pi), либо Claude Code по `ssh`/`scp` из Windows (OpenSSH встроен), либо
  Claude Code на самой Pi (Pi 4/5). Языки: Python (есть в ОС), C/C++ (`gcc` на Pi), Node/Go/Rust.
- Подготовка: Raspberry Pi Imager → включить SSH, пользователь/пароль, Wi-Fi; Pi в ту же
  сеть 10.0.1.x, IP — из роутера.

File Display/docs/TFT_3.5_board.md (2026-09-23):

# Плата-адаптер 3.5" TFT (8080 / SPI)

Контроллер: не подписан. Режимы IM и 40-pin FPC совпадают с ILI9488 (320×480), проверить при инициализации (ID-регистр 0xD3).

## Разъёмы
- **40-pin FPC**: шлейф самой матрицы (pin 1 слева, 40 справа).
- **8080-8P (FPC, верх)**: GND, VCC, CS, DC, WR, RD, RST, D0…D7, BL
- **8080-16P (FPC11, низ)**: GND, VCC, CS, DC, WR, RD, RST, D0…D15, BL
- **SPI, штыревой 9-pin (шаг 2.54)**:

| Pin | Сигнал |
|---|---|
| 1 | GND (квадратная площадка) |
| 2 | VCC |
| 3 | SCL |
| 4 | SDA (MOSI) |
| 5 | RST |
| 6 | DC |
| 7 | CS |
| 8 | BL (подсветка) |
| 9 | SDA-O (MISO) |

## Выбор интерфейса — перемычки IM2/IM1/IM0
Резисторы 0 Ом (на плате маркировка 102/201 у текущих позиций) переставляются между положениями 0 и 1.

| Режим | IM2 | IM1 | IM0 |
|---|---|---|---|
| 8080 8-bit (P8) | 0 | 1 | 1 |
| 8080 16-bit (P16) | 0 | 1 | 0 |
| SPI 4-wire (с DC) | 1 | 1 | 1 |
| SPI 3-wire (SPI3, 9-bit) | 1 | 0 | 1 |

## Питание
- U8 — LDO 3.3 В, SOT-23-3, маркировка **6206A** — подтверждено визуально (Torex
  XC6206P332MR или пин-совместимый клон, фиксированный выход 3.3 В, до 200 мА,
  даташит — `docs/datasheets/XC6206_LDO.pdf`). VCC можно подавать 5 В, логика 3.3 В.
- U7 — транзистор управления подсветкой (SOT-23), вход BL: высокий уровень = включено (проверить).
- Уровни сигналов данных — 3.3 В.

## Заметки
- Текущее положение перемычек IM: _уточнить по плате_.

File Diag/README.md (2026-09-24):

# Diag — диагностика и тестовые функции

Всё, что нужно только для отладки и проверки, живёт здесь и выключается одним
переключателем. Рабочий код (`Core/`, `Display/`, `Panel/`, `Config/`) о диагностике
знает только через вызовы-«крючки», которые при выключенной функции превращаются в
пустые inline-заглушки и в прошивку не попадают.

## Переключатели — `Inc/diag_config.h`

| Define | По умолчанию | Что делает |
|---|---|---|
| `DIAG_ENABLE` | 1 | Общий выключатель: `0` убирает всё из `Diag/` |
| `DIAG_CPU_STATS` | 1 | Замер загрузки главного цикла (счётчик тактов DWT) |
| `DIAG_CPU_UART` | 1 | Сводка в USART1 каждые `DIAG_CPU_UART_PERIOD_S` секунд |
| `DIAG_CPU_UART_PERIOD_S` | 5 | Период сводки в UART |
| `DIAG_CPU_PAGE` | 1 | Страница CPU на дисплее (в цикле кнопки страниц) |
| `DIAG_CAN_LOOPBACK` | 1 | Самопроверка CAN1 во внутренней петле (см. ниже). **Пока включена, реальная шина на J3 не используется** |
| `DIAG_CAN_REPORT_S` | 5 | Период отчёта самопроверки CAN в UART |

`DIAG_CPU_UART` и `DIAG_CPU_PAGE` без `DIAG_CPU_STATS` не работают и выключаются вместе
с ним. Любое значение можно задать и из командной строки компилятора (`-DDIAG_ENABLE=0`).

Цена в прошивке: ~2,3 КБ Flash и ~200 Б RAM при всём включённом.

## Загрузка процессора (`diag_cpu`)

RTOS нет, главный цикл крутится постоянно — «простоя» в привычном смысле нет. Поэтому
меряется, **куда уходит время цикла**. `main.c` обрамляет каждую работу вызовами
`diag_cpu_begin()/diag_cpu_end()`:

| Секция | Что внутри |
|---|---|
| ETH | `ethernetif_input()` + `ethernetif_poll_link()` |
| LWIP | `sys_check_timeouts()` |
| TCP | `tcp_echo_client_poll()` |
| HTTP | `config_http_poll()` |
| TFT | `TFT_App_AlivePoll()` (включая панель и смену страниц) + `TFT_App_ShowReceived()` |
| OTHER | всё остальное: мигание LED, логика DHCP/watchdog, сам цикл |

Прерывания засчитываются той секции, которую прервали.

Показатели за окно 1 с:
- **LOOPS/S** — проходов цикла в секунду; чем больше, тем свободнее процессор.
- **LOOPMAX** — самый долгий проход цикла = худшая задержка, с которой будет
  обработан пришедший Ethernet-кадр. Главный показатель для системы на опросе.
- **% и MAX по секциям** — доля времени и самый долгий одиночный вызов.

В UART (за 5 с, MAX — худший за период):
```
[cpu] 48213 loops/s, max pass 612MS | ETH 1.2% (max 310US) LWIP 0.4% (max 45US) ... OTHER 60.1%
```
Время самой печати (~1–2 мс) из статистики исключено.

## Самопроверка CAN (`diag_can`)

Драйвер `CAN/` переводится в режим «тихая петля» (bxCAN LBKM + SILM): отправленный кадр
возвращается в собственный приёмник внутри микросхемы, на ножки ничего не выходит.
Раз в секунду отправляется кадр с номером — по очереди со стандартным (0x7E1) и
расширенным (0x18DAF1E1) ID, 8 байт — и проверяется, что он вернулся тем же (ID, длина,
данные) не позже чем через 100 мс. Каждые 5 с в UART:

```
[can] CAN1 up: 500 kbit/s (APB1 40 MHz, presc 5, 16 tq), SILENT LOOPBACK self-test - real bus not used
[can] rx 7E1 [8] 00 00 00 02 CA FE 55 AA
[can] rx 18DAF1E1 [8] 00 00 00 03 CA FE 55 AA
[diag-can] loopback PASS: sent 5 ok 5 lost 0 bad 0 (total ok 25 fail 0)
```

Проверяются драйвер, тайминги, фильтр, прерывание, очередь. **Не** проверяются трансивер
TCAN1044V, разъём J3 и проводка — для этого нужен второй узел (USB-CAN адаптер или второй
модуль) и `DIAG_CAN_LOOPBACK 0`.

## Добавить новую диагностическую функцию

1. Код — в `Diag/Src/`, заголовок — в `Diag/Inc/`, файл — в `PROJECT_SOURCES` в `CMakeLists.txt`.
2. Переключатель `DIAG_<ИМЯ>` — в `diag_config.h`, в блоке зависимостей привязать к `DIAG_ENABLE`.
3. В заголовке — заглушки `static inline` для выключенного случая, чтобы вызовы в
   рабочем коде не требовали `#if`.

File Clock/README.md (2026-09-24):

# Clock — сетевые часы (NTP)

Время суток по NTP и отдельная страница **CLOCK** на дисплее (кнопка страниц, после LOCAL).

## Файлы

| Файл | Что делает |
|---|---|
| `Inc/clock_config.h` | Настройки: NTP-сервер, часовой пояс, летнее время, интервалы |
| `Inc/clock.h`, `Src/clock.c` | SNTP-клиент на raw UDP lwIP + отсчёт времени + местное время |
| `Inc/clock_page.h`, `Src/clock_page.c` | Страница CLOCK на TFT |

## Как работает

- `clock_poll(has_ip)` в главном цикле (`main.c`). Как только есть IP — запрос к
  `CLOCK_NTP_SERVER` (по умолчанию `pool.ntp.org`, через DNS). DNS-сервер выдаёт DHCP;
  при статическом IP используется шлюз.
- Ответ сервера (с поправкой на половину времени прохождения) становится базой, дальше
  время считается от системного тика (кварц HSE). Пересинхронизация — раз в час; при
  неудаче — повтор через 10 с (пока время ни разу не получено) или через 60 с.
- Местное время: `CLOCK_TZ_OFFSET_MIN` (Эстония: +120 мин) и, если `CLOCK_EU_DST = 1`,
  +1 час с последнего воскресенья марта 01:00 UTC до последнего воскресенья октября.
- RTC микроконтроллера не используется: после перезагрузки время снова берётся из сети
  (первая синхронизация — через секунды после получения IP).
- В UART: `[clock] synced 24.09.2026 14:03:22 local (адрес сервера, rtt N ms)`, а также
  сообщения о неудачах DNS / NTP.

## Страница CLOCK

```
 CLOCK                  5/6
   14 : 03 : 22          ← 7-сегментные цифры, 24 ч
    24.09.2026
     THURSDAY
 TZ:   UTC+3 SUMMER
 SYNC: OK AT 14:03:22
 NTP:  pool.ntp.org
```

Ничего не перерисовывается по таймеру: каждый элемент сравнивается с тем, что уже на
экране, и рисуется заново только при изменении. Обычно раз в секунду меняется только
цифра секунд; минуты, часы, дата и день недели — в момент смены; строки TZ/SYNC — при
синхронизации или переходе на летнее/зимнее время. До первой синхронизации цифры пустые,
дата `--.--.----`, в SYNC — `WAITING`.

День недели — по-английски: шрифт дисплея латинский.

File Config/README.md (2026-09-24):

# Config — persistent settings + network configurator

Самодостаточный модуль: постоянные настройки устройства и способ их менять по сети,
не трогая прошивку/`Core/`. Появился взамен жёстко прошитых в `tcp_echo_client.h`
констант (`TCP_ECHO_SERVER_IP0..3`/`PORT`) — раньше смена адреса сервера требовала
пересборки и перепрошивки; теперь это делается из браузера (или одной TCP-командой) с
любого компьютера/телефона в той же сети, без кабеля и без Claude Code.

## Веб-страница настройки (основной способ)

**Как найти модуль.** При подключении к роутеру модуль получает IP по DHCP и показывает
его на экране (страница SETUP, строка `IP:`, строка `DHCP:` = `OK`). Если DHCP-сервер
не ответил за 10 с (например, модуль подключён кабелем прямо к компьютеру), модуль
берёт **IP по умолчанию** — поле «Статический IP / IP по умолчанию» из таблицы, из
коробки `192.168.1.100`, маска `255.255.255.0`; на экране `DHCP: NO-DEFAULT IP`.
Компьютеру в этом случае нужен адрес из той же подсети (например `192.168.1.10`).
DHCP при этом повторяется каждые 30 с — появится сервер, модуль перейдёт на выданный им адрес.
Если за 60 с на резервном IP аренды так и нет и к странице/порту 7000 никто не обращался,
модуль перезагружается: на этой плате после холодного включения DHCP иногда не проходит
до перезагрузки МК (см. `docs/PROJECT_GUIDE.md`). Открытая страница (любой запрос за
последние 5 мин) эти перезагрузки останавливает.

Откройте в браузере **`http://<IP модуля>/`**. Таблица настроек:

| Параметр | Образец записи | Текущее значение | Новое значение |
|---|---|---|---|
| Имя устройства | `room-3` | то, с чем модуль работает сейчас | поле ввода |
| IP TCP-сервера | `10.0.1.16` | … | … |
| Порт TCP-сервера | `5000` | … | … |
| Режим IP | `DHCP / STATIC` | … | список |
| Статический IP / IP по умолчанию | `192.168.1.100` | … | … |
| Маска подсети | `255.255.255.0` | … | … |
| Шлюз | `192.168.1.1` | … | … |

Заполняются только те поля «Новое значение», которые нужно поменять; пустое поле —
значение не меняется. Если значение уже сохранено, но ещё не активно, под текущим
значением видно оранжевое «после рестарта: …».

Кнопки под таблицей:

| Кнопка | Действие |
|---|---|
| **Save** | Проверить введённые значения и записать их в модуль (Flash). Модуль продолжает работать со старыми — новые вступят в силу после следующего рестарта. |
| **Cancel** | Выйти без изменений — ничего не записывается. |
| **Restart** | Записать новые значения (если введены) и сразу перезапустить модуль (~7 с). Страница сама откроется заново; в режиме STATIC — по новому адресу. |

При любой ошибке ввода (неверный IP, порт вне 1–65535, имя длиннее 23 символов,
STATIC без IP/маски) не записывается ничего и перезапуска нет — красная строка
объясняет, что не так.

Реализация: `Src/config_http.c` — минимальный HTTP/1.0-сервер на raw API lwIP, форма
методом GET (`/apply?act=save|cancel|restart&name=…`), один запрос на соединение
(`Connection: close`). Кириллица на странице — UTF-8; в поле имени лучше
латиница/цифры, экран модуля кириллицу не отображает.

> Порт 7000 (ниже) по-прежнему применяет `SET SERVER`/`SET NAME` сразу — это
> отдельный, «сервисный» путь.

## Структура

| Путь | Что это |
|---|---|
| `Inc/device_config.h`, `Src/device_config.c` | Хранилище настроек: структура `DeviceConfig`, чтение/запись во Flash (последний сектор, `0x080E0000`, сектор 11 — далеко от прошивки, сейчас занимающей ~17% из 1 МБ), проверка CRC32, откат на дефолты при первом старте/повреждении. Не знает ни о lwIP, ни о протоколе, который её пишет. |
| `Inc/config_http.h`, `Src/config_http.c` | Веб-страница настройки на порту 80 (см. выше). Знает про lwIP и `device_config.h`, но не про `Display/`/`tcp_echo_client` — о сохранении остальные узнают через `device_config_revision()`. |
| `Inc/config_server.h`, `Src/config_server.c` | TCP-слушатель на порту 7000, построчный текстовый протокол (см. ниже). Знает про lwIP (raw API, как `tcp_echo_client.c`, только в роли сервера, а не клиента) и про `device_config.h`, но не про `Display/`. |

## Слои и кто чем пользуется

```
main.c
  │  device_config_load()     — сразу после boot-сообщения, до всего остального
  │                              (нужен и экрану, и MX_LWIP_Init())
  │  MX_LWIP_Init()            — читает use_static_ip: static IP или DHCP
  │  config_server_init()      — после MX_LWIP_Init(), чисто событийный (accept/recv),
  │                              отдельного poll() в цикле не нужно
  │  config_http_init()        — то же для порта 80; config_http_poll() в цикле нужен
  │                              только для отложенной перезагрузки после Restart
  │  цикл: DHCP не ответил за 10 с → device_config_fallback_addr() (IP по умолчанию)
  │  цикл: device_config_revision() изменилась → TFT_App_UpdateInfo() (SERVER:/NAME:),
  │        а если сменился адрес сервера → tcp_echo_client_restart()
  ▼
Config/Src/device_config.c  (постоянное хранилище)
      ▲
      │ device_config_get()
      │
Core/Src/tcp_echo_client.c   — читает server_ip/server_port заново при каждой
                                попытке (пере)подключения, без кэширования
Display/Src/tft_app.c        — SERVER:/NAME: на странице SETUP: при загрузке из
                                `TFT_App_SmokeTest()`, после сохранения — `TFT_App_UpdateInfo()`
```

## TCP-конфигуратор (порт 7000, построчно, `\r\n`) — запасной способ

Подключиться можно чем угодно — `nc <IP модуля> 7000`, PuTTY (Connection type: **Raw**,
Host = IP модуля, Port = 7000), или (если ни того, ни другого нет под рукой)
[`scripts/config-client.ps1`](../scripts/config-client.ps1) — интерактивный клиент на
чистом PowerShell без сторонних утилит:
```
powershell -ExecutionPolicy Bypass -File scripts/config-client.ps1 <IP модуля>
```
IP модуля виден на экране (страница SETUP, `IP:`).

| Команда | Действие |
|---|---|
| `SET SERVER <ip> <port>` | Адрес `tcp_echo_client`. Применяется сразу же на следующей попытке (пере)подключения — перезагрузка не нужна. |
| `SET NAME <текст>` | Имя устройства (до 23 символов, обрезается длиннее — безопасно). |
| `SET IP DHCP` | Переключить на DHCP. Требует `SAVE` + `REBOOT`. |
| `SET IP STATIC <ip> <netmask> <gateway>` | Переключить на статический IP. Требует `SAVE` + `REBOOT`. |
| `SAVE` | Записать текущие настройки во Flash (иначе всё слетит при следующей перезагрузке). |
| `REBOOT` | `NVIC_SystemReset()` — нужен, чтобы применились изменения режима IP (SERVER/NAME применяются и без этого). |
| `GET` | Дамп текущих настроек (то, что реально в ОЗУ, не обязательно то, что уже сохранено). |

Пример сессии (проверено вживую):
```
$ nc 10.0.1.140 7000
READY (SET SERVER/NAME/IP, SAVE, REBOOT, GET)
SET NAME room-3
OK (SAVE to persist)
SAVE
OK
GET
NAME=room-3
SERVER=10.0.1.16:5000
IPMODE=DHCP
STATIC_IP=0.0.0.0
STATIC_MASK=0.0.0.0
STATIC_GW=0.0.0.0
OK
```

Одновременно поддерживается только **одна** сессия — вторая попытка подключения
получает `ERR busy, one config session at a time` и закрывается сразу (проще и
безопаснее, чем делить один буфер строки между несколькими клиентами; это
административный интерфейс для одного техника, не сервис с параллельными
пользователями).

## Хранение

`DeviceConfig` (magic + версия + CRC32 + сами поля) пишется в последний сектор Flash
(сектор 11, `0x080E0000`, 128 КБ) — специально максимально далеко от прошивки (сейчас
~176 КБ из 1 МБ), чтобы рост прошивки не грозил однажды дотянуться до этого сектора.
`device_config_load()` при старте проверяет magic/версию/CRC32 — если что-то не сошлось
(чистый Flash при самой первой прошивке, битый CRC, будущий бамп версии без миграции),
тихо откатывается на дефолты (тот же адрес сервера, что был захардкожен раньше:
`10.0.1.16:5000`).

`device_config_save()` — блокирующая операция (стирание сектора занимает ~1 с, всё это
время CPU не может выполнять код из Flash вообще, то есть весь Ethernet-стек тоже
стоит). Это редкая, инициированная оператором операция (по команде `SAVE` / кнопке
«Сохранить»), не на периодическом пути — тот же компромисс, что уже принят для
~7-секундного блокирующего теста дисплея при загрузке.

## Найденная и исправленная ошибка: зависание в `tcp_input()` после сброса ETH

Симптом: после нескольких запросов к веб-странице модуль переставал отвечать совсем
(ни ping, ни HTTP), хотя CPU работал — остановка через OpenOCD показала бесконечный
цикл в `tcp_input()` по списку `tcp_tw_pcbs`: два соединения порта 80 в TIME_WAIT
ссылались друг на друга (кольцо).

Причина — в `ethernetif_reset()` (`Core/Src/ethernetif.c`, аварийный сброс ETH после
3 неудачных подключений клиента и т.п.): `memp_init()` объявлял весь пул TCP PCB
свободным, хотя PCB всё ещё числились в списках lwIP. Следующее соединение получало
такой «свободный» PCB, lwIP регистрировал его повторно — и список замыкался. Раньше это
не проявлялось, потому что соединения в TIME_WAIT оставляет только сервер, который
закрывает первым, — а первым таким сервером стал HTTP.

Исправление: перед очисткой пулов все активные/TIME_WAIT/bound PCB корректно
закрываются через `tcp_abort()` (их владельцы получают обычный `err`-callback), а пул
слушающих PCB (порты 7000 и 80) не очищается — оба конфигуратора переживают сброс ETH.
Заодно `ethernetif_reset()` и восстановление линка больше не включают DHCP в режиме
статического IP (`ethernetif_set_use_dhcp()`, выставляется в `MX_LWIP_Init()`).
Проверено: клиент направлен на закрытый порт → серия сбросов ETH под постоянной
HTTP-нагрузкой (200 запросов за 2 мин) → модуль каждый раз восстанавливался.

## Проверено вживую
- Веб-страница: форма с текущими значениями; сохранение имени/сервера («Сохранено и
  применено», `NAME:`/`SERVER:` на экране обновились); ошибки — неверный IP сервера,
  порт 99999, статический режим с IP/маской 0.0.0.0 (ничего не сохраняется); 5
  сохранений подряд + 30 GET подряд; `/favicon.ico` → 404; смена порта сервера →
  клиент переподключился к новому адресу.
- `GET` сразу после прошивки — дефолты корректны.
- `SET NAME` → `SAVE` → `REBOOT` → переподключение → `GET` — новое имя пережило полную
  перезагрузку.
- Статический IP (`SET IP STATIC`) собран и реализован в `MX_LWIP_Init()`, но пока не
  проверен на реальном железе — сделайте `SET IP STATIC ... `, `SAVE`, `REBOOT` и
  сверьте `IP:` на экране/`GET` после перезагрузки.

## Что дальше
- [ ] Проверить статический IP на реальном железе (сейчас проверены только SERVER/NAME/DHCP-путь)
- [ ] Пароль на веб-страницу и TCP-конфигуратор, если устройство будет доступно не только в доверенной локальной сети
- [ ] Применение `SET SERVER`/`SET NAME` без REBOOT уже работает; отдельно можно сделать live-переключение DHCP↔static без перезагрузки, если понадобится (сейчас сознательно не делали ради простоты/надёжности)

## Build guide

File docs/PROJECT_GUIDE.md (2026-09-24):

# Проект STM32F407VG LAN v1

## Назначение
Файл сопровождения проекта описывает структуру, инструменты и шаги настройки, чтобы можно было открыть проект на другом компьютере без дополнительных вопросов.

## Содержимое проекта

- `stm32f407vg_lan_v1.ioc` — проект STM32CubeMX с конфигурацией МК и периферии.
- `.mxproject` — внутренний файл CubeMX для настройки генерации.
- `f407.sch` — схема платы в Autodesk Eagle.
- `EWARM/` — артефакты генерации IAR Embedded Workbench (EWARM), которые можно игнорировать, если вы не используете IAR.
- `Core/Inc/`, `Core/Src/` — пользовательский и сгенерированный код.
- `Drivers/` — STM32Cube HAL и CMSIS, необходимые для сборки.

## Окружение и инструменты

- STM32CubeMX 6.17.0 compatible
- STM32CubeF4 FW package V1.28.3
- ST-Link V2 или другой программатор, поддерживающий STM32F4
- Опционально: Autodesk Eagle для открытия `f407.sch`
- VS Code — основная среда редактирования

## VS Code

- В этом проекте `VS Code` используется как основной редактор исходников.
- Файлы CubeMX и исходники находятся в проекте, а `EWARM/` может оставаться в папке как сгенерированный артефакт.
- Сборка выполняется внешней цепочкой инструментов: `arm-none-eabi-gcc`, `make`, `CMake`, STM32CubeMX или другая система сборки.
- Программирование платы выполняется через `ST-Link V2` (клон) с помощью `STM32CubeProgrammer`, `OpenOCD`, `st-flash` или аналогичного инструмента.
- Если хотите, добавьте в `VS Code` задачи `tasks.json` для вызова сборки и прошивки.

## Целевая платформа

- MCU: STM32F407VGTx (STM32F407VGT6, LQFP100)
- Частота HSE: 25 MHz
- SYSCLK: 160 MHz
- Тактовая частота APB1: 40 MHz
- Тактовая частота APB2: 80 MHz

## Конфигурация периферии

- `USART1` на PA9 (TX) / PA10 (RX), асинхронный режим, 921600 baud
- `USART3` на PD8 (TX) / PD9 (RX), асинхронный режим, 921600 baud
- `SWD` на PA13 / PA14
- `HSE` на PH0/PH1
- GPIO выходы для индикаторов:
  - PB4 = LED7
  - PB5 = LED8
  - PD0 = LED3
  - PD1 = LED4
  - PD4 = LED5
  - PD7 = LED6

## Файлы проекта

- `stm32f407vg_lan_v1.ioc` — проект STM32CubeMX
- `.mxproject` — внутренний файл CubeMX
- `f407.sch` — схема платы в Autodesk Eagle
- `EWARM/` — артефакты генерации IAR Embedded Workbench (EWARM), которые можно игнорировать, если вы не используете IAR
- `Core/Inc/`, `Core/Src/` — пользовательский и сгенерированный код
- `Drivers/` — STM32Cube HAL и CMSIS, необходимые для сборки

## Важные примечания по открытию на другом компьютере

1. Скопируйте весь каталог проекта целиком, чтобы относительные пути сохранились. Проект использует относительные пути к `Core/`, `Drivers/` и `EWARM/`.
2. Откройте `stm32f407vg_lan_v1.ioc` в STM32CubeMX. Если пакет STM32CubeF4 V1.28.3 не установлен, установите его через менеджер пакетов CubeMX.
3. В генераторе CubeMX проверьте:
   - `Project Manager -> Project Name` = `stm32f407vg_lan_v1`
   - `Project Manager -> Keep User Code` = включено
   - `Project Manager -> Copy only the necessary libraries` = включено (или `Library copy = 1`)
4. Если вы используете собственную сборку, настройте параметры генерации так, чтобы получать только `Core/` и `Drivers/`, а не файлы IAR.
5. Если CubeMX пересобирает проект, любые изменения в `Core/Src/main.c` и `Core/Inc/main.h` должны сохраняться внутри специальных блоков `/* USER CODE BEGIN */` / `/* USER CODE END */`.

## Рекомендованный порядок работы

1. Откройте `stm32f407vg_lan_v1.ioc` в CubeMX.
2. Убедитесь, что выбран правильный MCU и настроены сигналы.
3. Сгенерируйте код.
4. Редактируйте исходники в `VS Code`.
5. Соберите проект своей сборочной цепочкой (`make`, `CMake`, `arm-none-eabi-gcc`, `STM32CubeMX` и т.п.).
6. Программируйте плату через `ST-Link V2` (клон) с помощью `STM32CubeProgrammer`, `OpenOCD` или другого инструмента.

## КРИТИЧНО: startup_stm32f407xx.s должен содержать `.weak` для каждого обработчика

`Core/Startup/startup_stm32f407xx.s` — **не штатная генерация CubeMX** (CubeMX в этом проекте генерирует startup только для IAR, `EWARM/startup_stm32f407xx.s`). Файл для GCC/CMake был написан вручную при настройке CMake-сборки.

**Один раз уже была серьёзная ошибка:** в файле отсутствовали все директивы `.weak` перед строками вида `.thumb_set ИмяHandler, Default_Handler`. Без `.weak` эти имена (`SysTick_Handler` и вообще все ~80 обработчиков прерываний) становятся локальными алиасами на `Default_Handler` *внутри самого startup-файла*, и таблица векторов прерываний (`__isr_vector`) навсегда зашивает адрес `Default_Handler` — даже если в `Core/Src/stm32f4xx_it.c` есть нормальная реализация (например, `SysTick_Handler` с `HAL_IncTick()`). Компилятор и линковщик **не выдают ни одной ошибки/предупреждения** — всё линкуется "чисто".

Симптом был коварный: код без прерываний (GPIO, инициализация UART) работал нормально, прошивка успешно писалась и проверялась. Но как только код стал зависеть от прерывания (`HAL_Delay()` через `SysTick`), ядро намертво вешалось в `Default_Handler` (бесконечный `b .`) при первом срабатывании SysTick — `HAL_Delay()` никогда не возвращался. Внешне выглядело как "LED не мигают" / "зажглись и зависли".

**Если когда-нибудь снова придётся пересоздавать/чинить `startup_stm32f407xx.s` вручную:**
- Перед каждой строкой `.thumb_set XXX_Handler, Default_Handler` обязательно должна идти `.weak XXX_Handler`.
- Лучше вообще не писать этот файл руками — взять готовый `startup_stm32f4*.s` из пакета `STM32CubeF4` (`Drivers/CMSIS/Device/ST/STM32F4xx/Source/Templates/gcc/`) и подставить под нужный МК.
- Чтобы проверить, что баг не вернулся: halt ядро через OpenOCD дважды с разницей в пару секунд и командой `resume` между ними, прочитать `pc` и память по адресу глобальной переменной `uwTick` (см. `arm-none-eabi-nm build/*.elf | grep uwTick` для адреса) — если значения не меняются между чтениями, обработчики прерываний не работают.

## Прошивка через OpenOCD — известные проблемы и готовое решение

Эти грабли уже пройдены один раз (см. историю отладки) — **не наступайте на них снова**, просто используйте задачу `Flash STM32F407VG` из `.vscode/tasks.json`, она уже всё учитывает.

### Особенности этой платы (custom, `f407.sch`)

- **NRST от ST-Link к плате не подключён.** Аппаратный reset через `connect_assert_srst` недоступен.
- **BOOT0 (вывод 94 МК, U1) не выведен на джампер/разъём** — подтянут к GND резистором `R4` (10 кОм), и больше никуда. Чтобы временно поднять BOOT0 в "1" (например, для входа в системный bootloader), нужно физически припаивать временный провод на вывод 94 или на верхний контакт R4 — штатного способа нет.
- Напряжение на target обычно **~3.12–3.15 В** — на нижней границе нормы, но рабочее. Если когда-нибудь снова появится `init mode failed (unable to connect to the target)`:
  1. Это почти всегда обрыв/контакт SWDIO/SWCLK/GND, а не прошивка.
  2. Без NRST помогает приём "поймать момент после подачи питания": обесточить плату, в PowerShell крутить `openocd ... -c init -c halt` в цикле и включить питание во время цикла.

### Баг команды `program ... verify` в текущей сборке OpenOCD

Используемая сборка — `xPack OpenOCD 0.12.0+dev-02228-ge5888bda3-dirty`. На этой плате команда-шорткат
```
program build/stm32f407vg_lan_v1.bin verify reset exit
```
**стабильно проваливает верификацию** (`Error: checksum mismatch - attempting binary compare` → `Verify Failed`), даже когда запись реально проходит корректно. Перед ошибкой в логе всегда видно аномалию:
```
Info : flash size = 512 bytes
Warn : no flash bank found for address 0x00000000
```
— это внутренний баг авто-определения банка флеша именно в обёртке `program`, не реальная проблема платы/питания/прошивки (проверено: `RDP`/`WRP` отключены, `flash info 0` показывает все 12 секторов "not protected", напряжение в норме).

**Решение (уже встроено в задачу `Flash STM32F407VG`):** не использовать `program`, а делать запись и верификацию явными командами:
```
init
reset halt
stm32f4x mass_erase 0
flash write_image build/stm32f407vg_lan_v1.bin 0x08000000
verify_image build/stm32f407vg_lan_v1.bin 0x08000000
reset run
```
Это работает надёжно и подтверждено побайтовой верификацией — проверено и на пониженной (200/125 кГц), и на штатной (2000/1800 кГц) скорости SWD, оба раза успешно.

Скорость SWD **не ограничивается специально** — используется штатная из `target/stm32f4x.cfg` (~1.8 МГц). Разгон до 8 МГц, который встроен в хук `reset-init` этого конфига, в данной последовательности не задействуется, потому что используется `reset halt`, а не `reset init` (хук `reset-init` срабатывает только на `reset init`) — поэтому повторно разгонять/тормозить скорость вручную не требуется. Если в будущем кто-то добавит `reset init` в цепочку и вернётся проблема — сначала проверьте, не ожило ли воздействие этого хука, и при необходимости верните принудительное ограничение скорости (`adapter speed 200` + переопределение хуков `reset-init`/`reset-start`), это уже проверенный fallback.

## Проверка и восстановление

Если проект не открывается:

- Убедитесь, что `stm32f407vg_lan_v1.ioc` находится в той же корневой папке, что и `Core/`, `Drivers/`.
- Проверьте, что нет жестких абсолютных путей в `.ioc`.
- Если CubeMX просит миграцию, используйте текущую версию CubeMX и сохраните новый `.ioc` после миграции.
- Если вы не используете IAR, просто игнорируйте содержимое `EWARM/`.

## Порядок сохранения изменений

- Изменения в аппаратной конфигурации делайте через `stm32f407vg_lan_v1.ioc`.
- Изменения в коде прикладной логики делайте в `Core/Src/main.c` и в файлах `Core/Src/*`, `Core/Inc/*`.
- Не удаляйте папки `Drivers/CMSIS` и `Drivers/STM32F4xx_HAL_Driver` — они обязательны для сборки.
- Если вы не используете IAR, `EWARM/` можно оставить как артефакт или удалить, но не трогайте `Core/` и `Drivers/`.

## Примечания по синхронизации на разных компьютерах

- Храните проект в системе контроля версий (Git) вместе с `stm32f407vg_lan_v1.ioc`, `Core/`, `Drivers/` и `f407.sch`.
- Не коммитите временные каталоги сборки, например `EWARM/stm32f407vg_lan_v1/Exe`, `EWARM/stm32f407vg_lan_v1/Obj`, `EWARM/stm32f407vg_lan_v1/List`.
- Если вы не используете IAR, `EWARM/` можно не включать в репозиторий.
- Если проект открывается на новом компьютере, сначала проверьте пути в CubeMX и доступность пакета STM32CubeF4.

## ТЕКУЩАЯ ОТЛАДКА: обрыв TCP-связи под нагрузкой (статус на 2026-06-18, не завершено)

**Симптом:** при отправке нескольких сообщений в UART1 модуля (которые форвардятся в TCP) подряд связь стабильно умирает после определённого количества пакетов, требуя ресета. Без аппаратного ресета модуль не виден в сети (ARP не отвечает) с ПК.

### Подтверждённые и исправленные баги (уже в коде, проверено сборкой)

1. **`HardFault_Handler` был "тихим" `while(1)`** (`Core/Src/stm32f4xx_it.c`) — если бы случился реальный HardFault, диагностировать было бы невозможно. Исправлено: теперь печатает `[HARDFAULT] PC=... LR=...` в UART1 перед остановкой (через ассемблерный трамплин + `HardFault_C_Handler`). **На практике HardFault не наблюдался** ни разу — значит, дело не в crash/segfault уровня CPU.

2. **`ethernetif_reset()` добавлена** (`Core/Src/ethernetif.c`) — функция полного пересоздания ETH: `HAL_ETH_Stop_IT` → `HAL_ETH_DeInit` → аппаратный сброс через RCC (`__HAL_RCC_ETHMAC_FORCE_RESET/RELEASE_RESET`, т.к. `HAL_ETH_DeInit` НЕ дёргает линию аппаратного сброса) → `low_level_init()` (полная переинициализация MAC/DMA/PHY заново, включая NRST PHY). Вызывается из `tcp_echo_client.c`/`on_err()` после `ETH_RESET_AFTER_FAILS=3` неудачных попыток подключения подряд (~15 сек). **Подтверждено рабочим**: после такого сброса IP/PHY/ARP восстанавливаются (видно `[lwip] IP: 10.0.1.60` и реально устанавливается TCP-соединение).

3. **`HAL_ETH_Init()`/`DeInit()` не очищают `EthHandle.TxDescList`/`RxDescList`** — проверено по исходникам HAL (`Drivers/STM32F4xx_HAL_Driver/Src/stm32f4xx_hal_eth.c`), там просто нет кода, который бы их обнулял. Из-за этого счётчик занятых TX-буферов (`BuffersInUse`) копился через рестарт ETH и никогда не возвращался к 0. Исправлено: в `ethernetif_reset()` добавлен явный `memset(&EthHandle.TxDescList, 0, ...)` / `RxDescList`. **Подтверждено в логе**: после фикса `txbuf=0` сразу после `[eth] resetting ETH peripheral`, раньше оставалось зависшим на старом значении.

4. **Double-free pbuf при таймауте передачи** (`low_level_output()` в `ethernetif.c`) — при таймауте `HAL_ETH_Transmit()` (20 мс) HAL сам форсированно очищает бит OWN дескриптора (`heth->ErrorCode |= HAL_ETH_ERROR_TIMEOUT`), и pbuf будет освобождён позже через `HAL_ETH_ReleaseTxPacket()` → `HAL_ETH_TxFreeCallback()`. Старый код ДОПОЛНИТЕЛЬНО делал `pbuf_free(p)` сразу при любой ошибке — двойной free на один pbuf при таймауте, что портит heap lwIP. Исправлено: `pbuf_free(p)` теперь вызывается только если `EthHandle.ErrorCode` НЕ содержит `HAL_ETH_ERROR_TIMEOUT` (т.е. дескриптор не был поставлен в очередь и никто другой его не освободит).

5. **`ETH_TX_DESC_CNT`/`ETH_RX_DESC_CNT` увеличены с 4 (умолчание HAL) до 8** (`Core/Inc/stm32f4xx_hal_conf.h`, override перед `#include "stm32f4xx_hal_eth.h"`) — диагностический шаг, не финальное решение.

6. В `[alive]` heartbeat (`main.c`) добавлено поле `txbuf=%lu` = `EthHandle.TxDescList.BuffersInUse` для прямого наблюдения за утечкой TX-дескрипторов без доп. инструментирования.

### РЕШЕНО (2026-06-18): главная причина найдена и подтверждена инструментацией

Гипотеза из предыдущей версии этого раздела **подтверждена напрямую**: добавлен временный debug-print вокруг `HAL_ETH_ReleaseTxPacket()` (сравнение `BuffersInUse` до/после) и при `tcp_write()==ERR_MEM`. Лог показал:

- `[eth] release stuck: before=N after=N` — печаталось **на КАЖДОМ вызове, начиная с before=1** (то есть с первой же передачи после `[lwip] IP: ...`). `HAL_ETH_ReleaseTxPacket()` не освободил ни одного дескриптора ни разу за весь сеанс (>100 передач).
- `BuffersInUse` рос линейно до 104 и затем заморозился — ровно в этот момент начались `[tcp_echo] tcp_write ERR_MEM (heap exhausted?)`, подряд и постоянно. Это подтверждает: куча lwIP (`MEM_SIZE=16KB`) действительно исчерпывается накопленными pbuf, которые никогда не освобождаются через `HAL_ETH_TxFreeCallback()`.

**Корневая причина:** голова FIFO-очереди дескрипторов (`TxDescList.releaseIndex`, который никогда не сдвигается с 0) застряла с битом OWN навсегда уже на первой передаче — почти наверняка гонка сразу после `HAL_ETH_Start_IT()` в `low_level_init()` (первая передача, скорее всего DHCP DISCOVER, ставится в дескриптор раньше, чем DMA/MAC реально готовы её обслужить). Поскольку `HAL_ETH_ReleaseTxPacket()` устроен строго по FIFO (см. `Drivers/STM32F4xx_HAL_Driver/Src/stm32f4xx_hal_eth.c:1463` — `while (numOfBuf!=0 && pktTxStatus!=0)`, останавливается на первом дескрипторе с установленным OWN), застрявшая голова блокирует освобождение АБСОЛЮТНО ВСЕХ последующих дескрипторов навечно, даже если они реально передались по проводу (а они передавались — ПК получал данные все 60+ секунд, это видно по живому диалогу в логе).

**Фикс (применён, `Core/Src/ethernetif.c`, `low_level_output()`):** если `BuffersInUse > ETH_TX_DESC_CNT` (что само по себе невозможно при корректной работе кольца — прямое доказательство застревания, а не "просто давно не освобождали"), принудительно очищаем застрявший дескриптор-голову той же командой, что использует сам HAL при таймауте (`DESC0 = ETH_DMATXDESC_FS | ETH_DMATXDESC_LS`, это сбрасывает бит OWN), и сразу повторно вызываем `HAL_ETH_ReleaseTxPacket()`, чтобы реально освободить pbuf через `HAL_ETH_TxFreeCallback()`. Временные debug-print (`release stuck`, `tcp_write ERR_MEM`) убраны после подтверждения диагноза — если поведение вернётся, инструментацию легко восстановить (см. git-историю/предыдущую версию этого файла).

**Обновление после первого теста на плате:** гейт `> ETH_TX_DESC_CNT` почти не помог (рост до 50+ продолжался). Заменён на безусловный дренаж: на каждом вызове `low_level_output()` цикл `while (BuffersInUse > 0 && guard-->0) { force-clear головы; HAL_ETH_ReleaseTxPacket(); если без изменений - break; }` (до `ETH_TX_DESC_CNT+1` итераций). **Второй тест:** утечка стала значительно меньше (плато на ~45 вместо 104, и `txbuf=0` после рабочих ресетов), но не до конца ноль во время самого всплеска сообщений — видимо, дренаж не успевает полностью разгрузиться в рамках одного вызова при быстрой серии, и сообщения заканчиваются раньше, чем цикл успевает дойти до 0 (после остановки потока новых вызовов дренаж тоже не может продолжиться, т.к. он только внутри `low_level_output()`). Это уже не критично — TX-утечка больше не доминирующая причина отказа.

### НОВАЯ ОТКРЫТАЯ ПРОБЛЕМА (вскрылась после починки TX-утечки): module не переподключается после `ethernetif_reset()`

После того как TX-утечка перестала маскировать остальные эффекты, проявился **отдельный** баг: после нескольких циклов `ethernetif_reset()` модуль входит в устойчивый цикл "сброс → `[lwip] IP: ...` → мгновенный `connection error` → через 3 попытки снова сброс", **навсегда**, без единого успешного `[tcp_echo] connected`. При этом `txbuf=0` (утечки дескрипторов больше нет), `eth=LINK_UP` после первого тика — то есть PHY физически поднимается, но TCP не устанавливается.

Важное наблюдение пользователя: ARP-таблица ПК **показывает корректную запись** для модуля (`10.0.1.60 → 02-00-00-00-00-01, dynamic`) даже во время этого зависания — то есть на уровне Ethernet/ARP всё видно нормально, проблема глубже (похоже на TCP handshake или RX-путь модуля).

Аналогия с уже найденным TX-багом: возможно, есть **симметричный баг на RX-стороне** — `g_eth_rx_alloc_status` (бывший `RxAllocStatus`, см. `ethernetif.c`) может зависать в `RX_ALLOC_ERROR` после нескольких циклов сброса, из-за чего `low_level_input()` перестаёт вызывать `HAL_ETH_ReadData()` вообще (гейт `if (RxAllocStatus == RX_ALLOC_OK)`) — тогда модуль продолжает отправлять SYN (PC видит и ARPит его), но никогда не обрабатывает входящий SYN-ACK.

**Применены два фикса для проверки (собраны, НЕ ПРОВЕРЕНЫ на плате):**
1. `ethernetif_reset()` теперь дополнительно вызывает `etharp_cleanup_netif(netif)` — очищает ARP-таблицу lwIP (программное состояние, не аппаратное; наш сброс трогал только периферию ETH, а ARP-кэш lwIP мог оставаться "грязным" между циклами — это согласуется с давним наблюдением пользователя "помогает только сброс по питанию", т.к. питание пересоздаёт весь lwIP с нуля через `lwip_init()`, а наш софт-ресет — нет).
2. `RxAllocStatus` → переименован в публичный `g_eth_rx_alloc_status` (`ethernetif.h`), добавлен в heartbeat: `[alive] ... rxalloc=N` (main.c). `0` = `RX_ALLOC_OK`, `1` = `RX_ALLOC_ERROR`. Если в следующем тесте `rxalloc=1` будет видно во время зависания — это подтвердит гипотезу про исчерпание RX_POOL.

**Результат теста:** `rxalloc=0` все 100% времени, включая момент постоянного зависания — гипотеза про истощение RX_POOL **отклонена**. `etharp_cleanup_netif()` тоже не помог — цикл "сброс → мгновенный connection error" продолжился без изменений.

**Новая улика:** после сброса `[tcp_echo] connection error, will retry` появляется **мгновенно**, без обычной 5-секундной паузы нашего собственного таймера подключения. Это означает, что это НЕ наш `tcp_abort()`-по-таймауту (который быждал `RECONNECT_INTERVAL_MS`), а настоящий немедленный RST из сети. Рабочая гипотеза: коммутатор/роутер видит частые down/up на порту модуля (каждый `ethernetif_reset()` дёргает линк) и включает защиту от "флаппинга" порта — временно блокирует/игнорирует порт после нескольких быстрых переключений состояния линка за короткое время. То есть **наши собственные частые сбросы ETH могут быть причиной того, что сеть не восстанавливается**, а не лечением.

**Применённый фикс (собран, НЕ ПРОВЕРЕН):** экспоненциальный backoff между `ethernetif_reset()` (`tcp_echo_client.c`): `s_reset_count` считает подряд идущие сбросы без единого успешного подключения; задержка перед следующей попыткой подключения после сброса = `RECONNECT_INTERVAL_MS << min(s_reset_count, 4)`, то есть 5с → 10с → 20с → 40с → 60с (потолок `ETH_RESET_BACKOFF_CAP_MS`). Сбрасывается в 0 при любом успешном `[tcp_echo] connected`. В лог добавлено сообщение `[tcp_echo] backoff Nms before next try`.

**Найден баг в самом backoff-фиксе (тест показал):** в логе сообщение "backoff 40000ms before next try" печаталось, но реальная пауза перед следующим сбросом была всего ~10 секунд — backoff не действовал. Причина: в `tcp_echo_client_poll()`, `case ECHO_STATE_CONNECTING` (таймаут SYN без ответа), код вызывал `tcp_abort(s_pcb)` (это синхронно вызывает `on_err()`, который сам корректно вызывает `reset_to_idle()` и при необходимости выставляет backoff), а СРАЗУ ПОСЛЕ — ещё раз unconditionally вызывал `reset_to_idle()`, которая просто заново выставляла `s_next_action_tick = HAL_GetTick() + RECONNECT_INTERVAL_MS` (5с), затирая backoff. **Исправлено**: теперь при `s_pcb != NULL` `reset_to_idle()` вызывается только один раз (внутри `on_err()`, через цепочку `tcp_abort`), без повторного затирания снаружи. Собрано, **ЕЩЁ НЕ ПРОВЕРЕНО на плате**.

**Тест на другом порту роутера (2026-06-18): проблема повторилась идентично.** Это ИСКЛЮЧАЕТ теорию про flap-protection свича — проблема не во внешней сети, она в модуле. При этом `txbuf` снова вырос до ~50-53 несмотря на фикс дренажа дескрипторов (фикс не дал измеримого эффекта на пик — осталось почти так же, как без него, просто без фикса было 104, с фиксом ~50-53; ещё предстоит понять, почему дренаж не справляется полностью).

**Ключевое совпадение, объясняющее ВСЁ:** порог зависания (~50-53 пакетов) **не зависит от паузы между пакетами и не зависит от порта свитча** — то есть зависит только от КОЛИЧЕСТВА переданных пакетов, не от времени и не от внешней сети. При `MEM_SIZE=16KB` и примерной накладной стоимости ~300 байт на pbuf (текст ~70-90 байт + служебные данные lwIP), `16384/300 ≈ 54` — это совпадает с порогом практически точно. Это означает: лежащая в основе TX-утечка (pbuf, висящий с лишней ссылкой из-за `HAL_ETH_ReleaseTxPacket()`) всё ещё исчерпывает кучу lwIP `MEM_SIZE`, и именно ЭТА куча — программное состояние lwIP, а не аппаратная часть ETH — никогда не восстанавливалась нашим `ethernetif_reset()` (он трогает только MAC/DMA/PHY + ARP-таблицу, но не `mem_init()`/`memp_init()`). Это объясняет давнее наблюдение пользователя "помогает только сброс по питанию" — питание это единственное, что раньше пересоздавало кучу lwIP с нуля.

**Применённый фикс (собран, ЕЩЁ НЕ ПРОВЕРЕН):** `ethernetif_reset()` теперь дополнительно вызывает `dhcp_stop(netif)` + `mem_init()` + `memp_init()` — полный сброс кучи lwIP (`MEM_SIZE`) и всех стандартных memp-пулов (TCP_PCB, TCP_SEG, PBUF, UDP_PCB и т.д.), той самой памяти, которую раньше реально пересоздавал только физический сброс питания. Безопасно вызывать в этой точке, так как `TxDescList`/`RxDescList` уже обнулены ВЫШЕ в той же функции — никто больше не должен ссылаться на старую кучу. `RX_POOL` (кастомный пул через `LWIP_MEMPOOL_DECLARE`) отдельный от стандартных memp-пулов и не трогается этим вызовом — он уже переинициализируется внутри `low_level_init()`.

**Тест показал первый РЕАЛЬНЫЙ HardFault за всю сессию** (наша диагностика наконец сработала!): `[HARDFAULT] PC=0x08007464 LR=0x00000000 ...` сразу после `[eth] HAL_ETH_Init OK` при аварийном `ethernetif_reset()`. По `.map`-файлу (`arm-none-eabi-addr2line`/`nm --numeric-sort`) PC попал точно в `low_level_output()` (`ethernetif.c`).

**Причина — баг в МОЁМ собственном предыдущем фиксе:** `dhcp_stop(netif)` останавливает DHCP-клиент, но НЕ освобождает структуру `struct dhcp`, которую `dhcp_start()` выделил через `mem_malloc()` ещё при загрузке — `netif->dhcp` продолжает на неё указывать. Сразу после этого `mem_init()` сбрасывает free-list ВСЕЙ кучи — та же память может быть выдана повторно под что-то другое, пока `netif->dhcp` всё ещё "висит" на ней. Первая же новая аллокация (DHCP/ARP-пакет после ресета) переписала эту память, и тогда что-то внутри DHCP-обработки (или просто следующий `low_level_output()`, работающий с уже мусорным pbuf) обратилось к испорченным данным → HardFault.

**Исправлено:** перед `mem_init()` добавлен `dhcp_cleanup(netif)` (реально делает `mem_free()` структуры и очищает client-data слот netif — нашёл в `Middlewares/Third_Party/LwIP/src/core/ipv4/dhcp.c:712`). Также добавлен `dhcp_start(netif)` после `low_level_init()` — закрывает отдельный, ранее не замеченный гэп: ни `ethernetif_reset()`, ни `low_level_init()` сами по себе никогда не перезапускали DHCP-клиента после сброса (это делают только `MX_LWIP_Init()` при загрузке и `ethernetif_poll_link()` при переходе линка из down в up) — то есть после каждого нашего софт-ресета модуль работал на старом IP без активной DHCP-аренды вообще.

Собрано, **ЕЩЁ НЕ ПРОВЕРЕНО на плате**.

**ПОДТВЕРЖДЕНО ТЕСТОМ (2026-06-18): главная цель достигнута.** HardFault не повторился. Модуль теперь **дважды за один сеанс сам восстановился** после аварийного `ethernetif_reset()` (`[tcp_echo] connected` после `backoff 5000ms` — впервые за всю сессию отладки!). Цикл стал самовосстанавливающимся: работает ~85-100 сек (пока `txbuf` растёт до ~50-53 и куча lwIP не исчерпывается) → связь рвётся → аварийный сброс (теперь со сбросом `mem_init()`/`memp_init()`/DHCP) → успешное переподключение. Раньше после первого разрыва модуль навсегда зависал без физического ресета — это и было главной проблемой пользователя, и она решена.

**Что осталось не идеальным (не блокирует работу, но стоит доделать при следующем заходе):** утечка TX-дескрипторов (`HAL_ETH_ReleaseTxPacket()`, см. выше) всё ещё не устранена до конца — `txbuf` всё равно доходит до ~50-53 при активном обмене вместо удержания около 0, из-за чего связь периодически обрывается и требует аварийного сброса. Теперь это не катастрофа (само восстанавливается), но было бы лучше не доходить до этого вовсе. Следующий шаг при желании докопаться: добавить точечную диагностику внутри цикла дренажа в `low_level_output()` (`ethernetif.c`) — почему он не успевает полностью разгрузить кольцо дескрипторов во время быстрой серии пакетов.

### Параллельно найденный (не связанный) баг: индикатор LED2/GREEN не горит — ОКОНЧАТЕЛЬНО ДИАГНОСТИРОВАН (2026-06-18)

(Две промежуточные версии объяснения — "резистор электрически мешает PHY" и "pad2 сам выдаёт REFCLKO" — были опровергнуты пользователем экспериментально/по датащиту и отброшены.)

**Подтверждено по реальной схеме проекта (`f407.sch`) + datasheet SMSC "Schematic Checklist for LAN8720I" (`LAN8720AIQFNRevASchematicChecklist.pdf`, рис. 7, стр. 15):**

- `LAN8720I QFN` pin 2 = `LED2/!NINTSEL` — двухфункциональный: при POR/nRST это strap-вход `nINTSEL`, после защёлкивания — постоянный выход индикатора `LED2`.
- В схеме (`f407.sch`): GREEN LED физически встроен в разъём `J1` (RJ45 с LED), а не дискретный компонент. Цепь: `+3.3V → R12 (1кОм) → сеть "+GREEN" → J1 pin9 (анод)`; `J1 pin10 (катод) → сеть "-GREEN" → напрямую на pin2 PHY (LED2/!NINTSEL)`. Также на этой же сети висит `R37 pin1`, а `R37 pin2` сидит на `+3.3V` — это и есть исходная ошибка из памяти проекта ("R37 wired to +3V3 instead of GND"), из-за которой понадобился ручной аппаратный bodge-резистор 1кОм с pin2 на GND, чтобы получить `nINTSEL=0` (нужно для REFCLKO-режима, без которого `HAL_ETH_Init` не работает).
- По datasheet (рис. 7): `nINTSEL=1` → LED активен по **низкому** уровню, разводка `VDD2A → LED → R → pin2` (это ТОЧНО схема в `f407.sch`). `nINTSEL=0` → LED активен по **высокому** уровню, разводка должна быть `pin2 → LED → R → GND` (обратная).

**Корень проблемы:** аппаратная разводка GREEN LED сделана под `nINTSEL=1` (анод на VDD2A, катод прямо на pin2), а реально используемый strap — `nINTSEL=0` (обязателен для REFCLKO). При активном-высоком режиме PHY поднимает pin2 почти до уровня VDD2A для индикации — на LED исчезает разность потенциалов, и он не зажигается (в худшем случае логика индикации просто инвертирована, а не корректна). **Это чисто пассивное рассогласование полярности, не лечится прошивкой/регистрами PHY.**

**Возможное исправление (требует аппаратной правки, не сделано):** поменять, что приходит на `J1 pin9`/`pin10` — `pin9` (сейчас через R12 на +3.3V) перевести на прямое соединение с pin2 PHY; `pin10` (сейчас прямо на pin2) перевести через резистор (R12 или R37) на GND. Это требует перепайки 1-2 проводников/резисторов на платe. Без этого GREEN не может корректно индицировать, пока REFCLKO-режим обязателен.

**Статус: диагноз закрыт окончательно, аппаратное исправление отложено (не блокирует сетевую функциональность — LED2 не участвует в линиях данных RMII).**

**Обновление аппаратуры (2026-06-19):** пользователь удалил `R37` (был ошибочно подключён к +3.3V) и заменил временный bodge-резистор 1кОм на постоянный **6.8кОм** между pin2 и GND — тот же штатный pull-down для `nINTSEL=0`, просто на чистом одиночном резисторе вместо связки "неправильный R37 + самодельный бодж". Полярность GREEN LED (J1 pin9/pin10) **не менялась** — описанное выше рассогласование активного-высокого/активного-низкого режима остаётся в силе, индикатор по-прежнему не будет корректно зажигаться без отдельной перепайки J1. Эта правка касается только надёжности strap-цепи, не связана с багом генератора REFCLKO ниже (разные пины: nINTSEL = pin2, кварц = pin4/5).

**Финально подтверждено поведение (2026-06-19): LED2/GREEN — это индикатор Link (не Activity), инвертированный.** Наблюдение пользователя: с подключённым кабелем GREEN вспыхивает на ~1 сек (при появлении линка/автопереговорах) и гаснет; без кабеля горит постоянно. Это ровно то, что предсказывает теория инверсии: при `nINTSEL=0` PHY держит pin2 HIGH когда линк есть и LOW когда линка нет, а LED (разводка под активный-низкий) зажигается именно от LOW — то есть светится, когда линка НЕТ, и гаснет, когда линк есть (вспышка на ~1 сек — переходный период автопереговоров сразу после сброса PHY, пока pin2 ещё не перешёл в HIGH). Индикатор полностью исправен функционально, просто показывает обратную логику. Вопрос про LED2 закрыт окончательно — никаких новых неясностей не осталось, остаётся только опциональная аппаратная перепайка J1 pin9/pin10, если нужна нормальная (не инвертированная) индикация.

### ОКОНЧАТЕЛЬНЫЙ ФИКС TX-утечки дескрипторов (2026-06-18)

Пользователь настоял на полном устранении утечки (не только самовосстановлении): "конечно устранить! этот дефект является одним из важнейших".

**Точная диагностика (новая verbose-инструментация дренажа в `low_level_output()`):** на КАЖДОМ вызове, всю сессию, лог показывал `idx=0 hadPkt=0 desc0=0x30D00000 before=N after=N` — то есть `releaseIndex` навсегда застыл на 0, слот 0 пуст (`PacketAddress[0]==NULL`), а `BuffersInUse` (`before`) тем не менее растёт от реальных передач через другие слоты кольца. Дренаж не делал ни одной успешной итерации НИКОГДА.

**Найден точный баг в самом HAL (`Drivers/STM32F4xx_HAL_Driver/Src/stm32f4xx_hal_eth.c:1451-1535`, `HAL_ETH_ReleaseTxPacket()`):** функция идёт по кольцу начиная с `releaseIndex`, до `BuffersInUse` итераций, ПРОПУСКАЯ пустые слоты (`PacketAddress[idx]==NULL`) только ЛОКАЛЬНО (`idx++` в переменной на стеке) — `dmatxdesclist->releaseIndex` и `dmatxdesclist->BuffersInUse` обновляются ТОЛЬКО внутри ветки успеха (когда находит слот с `PacketAddress!=NULL && OWN==0`, строки 1519-1525). Если по пути встречается хоть один слот с `OWN` ещё установленным — функция немедленно прерывается (`pktTxStatus=0`) и ВЕСЬ локальный прогресс (включая уже пройденные NULL-пропуски) отбрасывается, ничего не коммитится назад в handle. Дальше та же ситуация повторяется на каждом следующем вызове — `releaseIndex` навечно замирает.

Отдельно: `ETH_Prepare_Tx_Descriptors()` (строка 3137-3141) отказывается повторно использовать слот кольца, если `PacketAddress[idx] != NULL` — **даже если `OWN` уже снят** (пакет реально ушёл в сеть). Единственный штатный механизм очистки `PacketAddress[]` — сломанный `HAL_ETH_ReleaseTxPacket()` выше. Итог: слоты с уже переданными пакетами навсегда остаются "занятыми" программно → `BuffersInUse` только растёт → каждый такой pbuf держит лишнюю ссылку (`pbuf_ref()` в `low_level_output()`) → куча lwIP (`MEM_SIZE`=16KB) исчерпывается через ~50-54 пакета (совпадает с прошлым расчётом `16384/300≈54`).

**Фикс (применён, см. `Core/Src/ethernetif.c`):** перестали доверять бухгалтерии HAL вообще. Старый verbose drain-loop в `low_level_output()` заменён на новую функцию `eth_tx_drain_all()`, которая каждый вызов обходит ВСЕ `ETH_TX_DESC_CNT` физических слотов кольца напрямую (не используя `releaseIndex`/`HAL_ETH_ReleaseTxPacket()`): если `PacketAddress[idx]!=NULL && OWN==0` — слот реально готов, вызывается `HAL_ETH_TxFreeCallback()` (= `pbuf_free()`) и `PacketAddress[idx]` обнуляется; иначе слот считается ещё занятым. После обхода `BuffersInUse` и `releaseIndex` пересчитываются с нуля из реального состояния кольца. Это устраняет саму возможность "застревания" — больше нет общего `releaseIndex`, который можно заклинить, и `PacketAddress[]` всегда отражает реальное состояние, так что `ETH_Prepare_Tx_Descriptors()` больше никогда не откажет на основании устаревшей записи.

Собрано, билд проходит (`cmake --build build`), **ещё не проверено на плате** — следующий шаг: прошить и прогнать длительный тест (как раньше, burst трафика на протяжении нескольких минут), убедиться что heartbeat-поле `txbuf=` теперь держится около 0-1 постоянно (а не растёт до 50+), и что `ethernetif_reset()`/backoff-цикл больше не требуется вовсе.

**ПОДТВЕРЖДЕНО ТЕСТОМ (2026-06-18): TX-утечка дескрипторов устранена.** `txbuf=1` держался стабильно весь 270-секундный прогон (раньше к 50-53 пакету уходил в рост и связь рвалась). `eth_tx_drain_all()` работает как задумано — фикс TX-утечки закрыт, можно больше не возвращаться к этой части.

### Новый, отдельный баг: TCP-клиент замолкает навсегда после одного `connection error`

После исправления TX-утечки нашёлся СЛЕДУЮЩИЙ дефект, ранее маскировавшийся постоянными зависаниями ETH. Симптом: один раз проходит `[tcp_echo] connection error, will retry`, после чего — полная тишина в TCP-логике на 220+ секунд (никаких "connected"/"connection error"), хотя `[alive]` heartbeat продолжает идти каждые 5 сек и `arp -a` подтверждает, что модуль виден в сети. **Значит зависла не прошивка и не ETH/IP-стек, а конкретно state-машина в `tcp_echo_client.c`.**

Найдены два места в `start_connect()` (`tcp_echo_client.c`), которые при ошибке молча уходили в `reset_to_idle()` без единого сообщения в лог: `tcp_new() == NULL` (исчерпан `MEMP_NUM_TCP_PCB`, в `lwipopts.h` всего `4`) и `tcp_connect() != ERR_OK`. Если стейт-машина попадает в один из этих путей, она будет повторять попытку каждые 5 сек молча, бесконечно — внешне выглядит как полное зависание, хотя на самом деле просто крутится вхолостую без единого вывода.

**Фикс (применён):** добавлены `rx_push()` с текстом ошибки в оба этих места (`tcp_new() failed (PCB pool exhausted?)` и `tcp_connect() failed err=N`). Также добавлена однобуквенная диагностика состояния `tcp_echo_client_state_char()` (`'I'`=idle, `'C'`=connecting, `'E'`=connected/established), выведенная в heartbeat как новое поле `tcp=` (`main.c`): `[alive] t=... eth=... txbuf=... rxalloc=... tcp=I/C/E`.

Собрано, билд проходит, **ещё не проверено на плате** — следующий шаг: прошить, повторить тест до момента "зависания", прочитать `tcp=` в heartbeat (покажет, застряла машина в `C` (CONNECTING — SYN ушёл, ответа нет) или крутится в `I` (IDLE — `start_connect()` падает на одном из двух теперь залогированных путей)), и/или дождаться появления нового сообщения `tcp_new() failed` / `tcp_connect() failed err=N` в логе.

**ПОДТВЕРЖДЕНО ТЕСТОМ (2026-06-18): `tcp_connect() failed err=-1` = `ERR_MEM`.** Лог дал точные числа: `heap=16312/16384 tcp_pcb=1/4 tcp_seg=0/16 pbuf=0/8` (формат `used/avail`). Пулы `TCP_PCB`/`TCP_SEG`/`PBUF_POOL` практически пустые — значит утечка не в счётчиках сегментов/PCB, а в самой куче lwIP (`MEM_SIZE`=16KB, `mem_malloc()`), которая была занята на 16312 из 16384 байт (свободно всего 72 байта).

### Второй, отдельный баг: утечка кучи lwIP в `tcp_write()` (не связан с TX-дескрипторами)

Добавил поле `heap=used/avail` в heartbeat (`main.c`, через `lwip_stats.mem`) — это показало рост в реальном времени, не только в момент сбоя. **Результат теста:** куча росла **с каждым отправленным сообщением** во время активного обмена (`1476→1856→5472→16056→16264→16344` за ~30 сек активной переписки), затем **переставала расти** ровно когда переставали печатать, и **не падала** даже после 20+ секунд полного простоя без нового трафика — то есть это настоящая утечка (не задержка ACK), и она привязана к каждой передаче через `tcp_write()`, а не к разрыву соединения.

**Причина:** `TCP_OVERSIZE` в lwIP по умолчанию равен `TCP_MSS` (1460 байт) — каждый `tcp_write()`, который начинает новый "хвостовой" непосланный сегмент, резервирует в куче этот запас, чтобы последующие мелкие записи могли дописываться в тот же сегмент без новой аллокации. В `tx_flush()` (`tcp_echo_client.c`) после каждого `tcp_write()` сразу вызывается `tcp_output()` — то есть каждое сообщение становится отдельным "хвостом" с собственным резервом ~1460 байт, который не переиспользуется следующей записью (это уже новый сегмент). Магнитуда роста (~1400-1500 байт на сообщение) точно совпала с `TCP_MSS`, подтвердив диагноз.

**Фикс (применён, `Core/Inc/lwipopts.h`):** `#define TCP_OVERSIZE 0` — официально поддерживаемое значение (см. комментарий в `lwip/opt.h`: "0: Don't oversize, always allocate the exact size"), отключает резервирование запаса полностью; `tcp_pbuf_prealloc()` будет выделять ровно нужный размер на каждую запись. Для нашего паттерна использования (всегда `tcp_output()` сразу после `tcp_write()`) это не теряет производительность, так как мы и не пользовались переиспользованием запаса.

Собрано, билд проходит, **ещё не проверено на плате** — следующий шаг: прошить, повторить тот же тест (несколько сообщений через UART подряд), убедиться что `heap=` в heartbeat теперь держится стабильно низко (не растёт пропорционально количеству сообщений), и что `tcp_connect()` больше не падает с `ERR_MEM` после/во время длительного обмена.

**ТЕСТ (2026-06-18): `TCP_OVERSIZE=0` уменьшил рост кучи (~1400→~150-250 байт/сообщение), но НЕ устранил его.** Куча всё равно дошла до предела (`16384/16384`) за ~75 сек активного обмена и `tcp_connect()` снова упал с `ERR_MEM`. Значит `TCP_OVERSIZE` был не единственной причиной — есть утечка и в самих данных (не только в запасе под них). Также замечена аномалия: после одного `ethernetif_reset()` heap показал `17596/16384` — **больше объявленного объёма** (возможна порча счётчиков статистики или реальное повреждение памяти при сбросе, требует отдельной проверки).

**Новая диагностика (применена):** `tcp_echo_client_sndqueuelen()` (`tcp_echo_client.c`/`.h`) возвращает `tcp_sndqueuelen(s_pcb)` — число pbuf в очереди отправки PCB (`unsent`+`unacked`). Добавлено в heartbeat как `sndq=` (`main.c`). Если это число растёт без остановки во время активного обмена (а соединение при этом продолжает работать) — значит ACK не освобождает отправленные данные, и утечка именно здесь, а не в "запасе" `TCP_OVERSIZE` и не в RX-пути.

Собрано, билд проходит, **ещё не проверено на плате** — следующий шаг: прошить, повторить тест, прислать лог с новым полем `sndq=` в heartbeat.

**Найден отдельный баг диагностики (2026-06-18): счётчик `lwip_stats.mem.used` не сбрасывается при `ethernetif_reset()`.** В длинном тесте (t=480-505 сек, уже после нескольких циклов аварийного сброса) heap показал `38492/16384` — **больше объявленного объёма кучи**, при этом соединение продолжало работать (`tcp=E`, без `ERR_MEM`). Проверка `mem_init()` (`Middlewares/Third_Party/LwIP/src/core/mem.c:516`) показала: эта функция сбрасывает РЕАЛЬНЫЙ список свободных блоков аллокатора (поэтому настоящая куча действительно очищается, и работа после сброса продолжается нормально), но НЕ трогает `lwip_stats.mem.used` — это отдельная переменная статистики, обновляемая только инкрементами/декрементами при каждом malloc/free. После каждого `ethernetif_reset()` она просто продолжает копиться от старого значения, так что через несколько циклов сброса показывает фантастические числа, не отражающие реальное состояние кучи.

**Фикс (применён, `ethernetif_reset()` в `ethernetif.c`):** после `mem_init()`/`memp_init()` добавлен `memset(&lwip_stats.mem, 0, sizeof(lwip_stats.mem))` + `MEM_STATS_AVAIL(avail, MEM_SIZE)` — обнуляет счётчик статистики синхронно с реальным сбросом кучи. Это никак не влияет на сам факт утечки (она в реальном аллокаторе, не в счётчике) — это чисто чинит достоверность диагностики `heap=` в heartbeat после сброса.

**Важно: подлинность утечки в ПЕРВОМ цикле (до первого сброса) остаётся подтверждённой** — там `heap=16384/16384` совпало с настоящим падением `tcp_connect()` с `ERR_MEM` (это не могло быть просто артефактом счётчика, так как `ERR_MEM` возвращается реальным `mem_malloc()`, не основанным на статистике). Утечка реальна, просто после починки счётчика её будет проще отслеживать дальше.

Собрано, билд проходит, **ещё не проверено на плате** — нужно повторить тест с самого начала (после прошивки) и прислать ПЕРВЫЕ ~100 сек лога (до первого `ethernetif_reset()`), с полем `sndq=`, чтобы увидеть, растёт ли очередь отправки PCB в момент настоящей утечки.

**Результат теста: `sndq=0` всё время** (даже в момент `ERR_MEM`) — утечка не в очереди PCB. **Куча росла даже без единого набранного сообщения** (t=5000→105000, до первого "Hello Module" в логе) — рост шёл от автоматических `ping #N`, которые `tcp_echo_client_poll()` сам шлёт каждые `SEND_INTERVAL_MS`=2000 в состоянии CONNECTED. TCP keepalive здесь не виноват: он сбрасывается каждой передачей, а пинг идёт чаще интервала keepalive, так что последний физически не успевает сработать.

**Точная диагностика (добавлена в `low_level_output()`):** вывод `p->ref` пакета ПЕРЕД нашим `pbuf_ref()` — показал `ref=1` стабильно на каждом пакете (ожидаемое поведение, лишней ссылки до нас нет). Затем добавлена диагностика прямо в `eth_tx_drain_all()`: печать при каждом реальном освобождении слота. **За весь тест (~90+ передач) — НИ ОДНОЙ строки освобождения.** Значит `eth_tx_drain_all()` никогда ничего не находит для очистки, хотя `txbuf` (`BuffersInUse`) стабильно показывал `1`.

### НАЙДЕН ИСТИННЫЙ КОРЕНЬ ОБЕИХ УТЕЧЕК (TX-дескрипторов и кучи lwIP)

Прямая проверка источника `stm32f4xx_hal_eth.c` показала: `heth->TxDescList.CurrentPacketAddress` (то самое поле, которое `ETH_Prepare_Tx_Descriptors()` копирует в `PacketAddress[descidx]`, строка 3259) **устанавливается только внутри `HAL_ETH_Transmit_IT()`** (режим прерываний, строка 1048: `heth->TxDescList.CurrentPacketAddress = (uint32_t *)pTxConfig->pData;`). В `HAL_ETH_Transmit()` — **polling-режиме, который мы используем** (строки 962-1028) — это поле НИГДЕ не устанавливается!

Это означает: всё время, что мы вызывали `HAL_ETH_Transmit()`, `PacketAddress[]` никогда не получал указатель на реальный переданный pbuf — там всегда оставался NULL/устаревшее значение. Отсюда следует ВСЁ:
- `HAL_ETH_ReleaseTxPacket()` (старая HAL-функция) всегда видела `PacketAddress[idx]==NULL` и просто "пропускала" каждую запись — отсюда и самый первый баг сессии (рост `BuffersInUse` до 50-104 и обрыв связи).
- Наша замена `eth_tx_drain_all()` страдала ТЕМ ЖЕ корнем — она тоже ищет `PacketAddress[idx]!=NULL`, и тоже никогда не находила, поэтому ни разу не вызвала `pbuf_free()` для лишней ссылки, взятой нашим `pbuf_ref(p)`.
- Каждый переданный пакет навсегда оставлял ОДНУ лишнюю ссылку (`pbuf_ref()` без последующего `pbuf_free()`), которую lwIP сам никогда не отпускал, потому что эту ссылку добавляли МЫ, а не lwIP — и это и есть утечка кучи `MEM_SIZE`, которую гонялись всю сессию.

**Фикс (применён, `low_level_output()` в `ethernetif.c`):** перед вызовом `HAL_ETH_Transmit()` добавлена строка `EthHandle.TxDescList.CurrentPacketAddress = (uint32_t *)p;` — то же самое, что делает `HAL_ETH_Transmit_IT()` для режима прерываний. Теперь `ETH_Prepare_Tx_Descriptors()` корректно сохраняет реальный указатель в `PacketAddress[]`, и `eth_tx_drain_all()` сможет находить и освобождать его как положено.

Вся verbose-диагностика (`[eth] tx ...`, `[eth] drain free ...`) убрана из `low_level_output()`/`eth_tx_drain_all()` после нахождения причины — она была временной. `heap=`/`tcp=` в heartbeat (`main.c`) оставлены как полезные постоянные диагностические поля.

Собрано, билд проходит, **ещё не проверено на плате** — следующий шаг: прошить, прогнать длинный тест с активным обменом (как раньше), убедиться что `heap=` в heartbeat теперь держится стабильно низко неограниченно долго, `tcp_connect()` больше не падает с `ERR_MEM`, и аварийный `ethernetif_reset()`/backoff не требуется вовсе.

### ПОДТВЕРЖДЕНО: TX/heap-утечка устранена окончательно — НО найден новый баг: потеря IP без восстановления (2026-06-18, после ~2 часов наработки)

После фикса `CurrentPacketAddress` модуль проработал часами без роста кучи: `heap=128/16384` стабильно от t=7575000ms до t=8090000ms (больше 2 часов, замер до и после) — TX/heap-утечка закрыта окончательно, к этой части возвращаться не нужно.

**Новый, отдельный баг:** в это же время `tcp=I` (idle) без единого сообщения об ошибке, и модуль полностью пропал из сети — `arp -a` (полный, без фильтра) не показывает НИ ОДНОГО неизвестного адреса в подсети 10.0.1.x, только роутер/инфраструктуру/мультикаст. Модуль не отвечает ни под каким IP.

**Причина (подтверждена чтением исходников lwIP, `Middlewares/Third_Party/LwIP/src/core/ipv4/dhcp.c`):** при истечении DHCP-аренды (`dhcp_coarse_tmr()` → `t0_timeout` → `dhcp_release_and_stop()`, строка 1371) lwIP сам обнуляет IP интерфейса: `netif_set_addr(netif, IP4_ADDR_ANY4, ...)`, затем вызывает `dhcp_start()` для получения новой аренды. Это штатное поведение lwIP. НО: пока IP равен `0.0.0.0`, `main.c:133` (`if (netif_is_up(&gnetif) && !ip4_addr_isany_val(...)) { tcp_echo_client_poll(); }`) полностью пропускает вызов `tcp_echo_client_poll()` — а это значит, что наш ЕДИНСТВЕННЫЙ механизм самовосстановления (`ethernetif_reset()` после 3 неудачных TCP-подключений, `tcp_echo_client.c`) даже не успевает сработать, потому что вся его логика живёт внутри `tcp_echo_client_poll()`! Если DHCP не может сам переполучить аренду (по любой причине — таймаут ответа от роутера, потерянный broadcast и т.д.) — **нет вообще никакого механизма восстановления**. Здоровая сеть отвечает на DHCP DISCOVER за доли секунды; зависание на час+ означает, что DHCP-клиент lwIP застрял сам, и ничего извне его не подталкивает.

**Фикс (применён, `main.c`, основной `while(1)` цикл):** добавлен независимый от TCP watchdog. Считается время, прошедшее с момента, когда IP пропал (`ip_missing_since`, статическая переменная). Если IP отсутствует дольше `DHCP_STUCK_TIMEOUT_MS` = 90000 (90 сек — намного больше, чем нужно здоровой сети для DHCP) — вызывается тот же `ethernetif_reset(&gnetif)`, что и при зависании TCP (полный сброс ETH MAC/DMA/PHY + куча lwIP + перезапуск DHCP), независимо от состояния `tcp_echo_client_poll()`. Лог: `[lwip] no IP for too long, forcing ETH reset`.

Собрано, билд проходит, **ещё не проверено на плате** — следующий шаг: прошить, либо дождаться следующего естественного истечения DHCP-аренды (часы), либо для быстрой проверки временно уменьшить `DHCP_STUCK_TIMEOUT_MS` до маленького значения (например 10000) и принудительно вызвать `dhcp_release_and_stop()`/имитировать потерю IP, убедиться что `[lwip] no IP for too long, forcing ETH reset` появляется в логе и модуль восстанавливает IP/связь сам, без участия пользователя.

### Новый баг (2026-06-19): обрыв кабеля на 30-60 сек требует питания/полного ресета для восстановления

Симптом от пользователя: если выдернуть Ethernet-кабель на 30-60 сек, канал не восстанавливается сам по себе.

**Лог теста (см. диалог) показал необычную картину:** во время реального обрыва кабеля поле heartbeat `eth=` **не разу не показало `LINK_DOWN`** — оставалось `LINK_UP` непрерывно, пока `heap=`/`sndq=` росли (нормальное поведение TCP при потере пакетов: данные копятся неподтверждёнными, потом `tcp_echo` сдаётся с `connection error`). `eth=LINK_DOWN` появилось только ПОСЛЕ того, как штатный механизм "3 неудачных TCP-подключения → `ethernetif_reset()`" (`tcp_echo_client.c`) форсировал полный пересоздание MAC/DMA/PHY — то есть правильное определение обрыва линка проявилось только после полного ресета, а не в момент реального физического обрыва.

**Код `ethernetif_poll_link()` (`ethernetif.c:618`) и `LAN8742_GetLinkState()` (`lan8742.c:259`) выглядят корректно** — двойное чтение регистра `BSR` (стандартный приём против "залипшего" латч-бита Link Status), вызывается без всяких условий каждую итерацию главного цикла (`main.c:129`), внутри рейт-лимит 500мс. Видимых причин, почему PHY должен бы продолжать отвечать "линк есть" при физически выдернутом кабеле, в самом коде не нашлось — баг либо на уровне PHY-чипа/сигналов, либо где-то, что пока не видно по логам.

**Диагностика добавлена (применено, собрано, ещё не проверено на плате):** новое поле `phy=N` в heartbeat (`main.c`) — сырое возвращаемое значение `LAN8742_GetLinkState()` (см. `lan8742.h`: `1`=LINK_DOWN, `2..5`=варианты up, `6`=autonego not done, отрицательные = ошибка чтения/записи MDIO). Хранится в новой глобальной `g_eth_last_phy_link_state` (`ethernetif.h`/`.c`), обновляется на каждый вызов `ethernetif_poll_link()` прямо после чтения, до любой логики up/down. Цель — на следующем повторении того же теста увидеть: если `phy=` показывает `1` (PHY реально видит обрыв) пока `eth=` всё ещё `LINK_UP` — баг в логике `ethernetif_poll_link()`/netif (программный, легко чинится); если `phy=` показывает `2..5` (PHY настойчиво врёт "линк есть") при реально выдернутом кабеле — проблема на уровне PHY/сигналов RMII (аппаратная, сложнее).

Следующий шаг: прошить, повторить тест (выдернуть кабель на 30-60 сек, не дожидаясь автоматического сброса от 3-х неудачных TCP-подключений, если можно поймать раньше), прислать лог с новым полем `phy=`.

**ПОДТВЕРЖДЕНО (2026-06-19): баг не специфичен к разрыву линка — это общая ненадёжность запуска генератора LAN8720 (кварц 25МГц + внутренний PLL) при сбросе через `nRST`.**

Тест дал три ключевых лога:
1. Во время реального разрыва кабеля `eth=` ни разу не показал `LINK_DOWN` (см. выше) — но это объяснилось тривиально: `phy=` (новое поле) всё это время было заморожено на старом значении, потому что `ethernetif_poll_link()` сама не опрашивает PHY, когда `EthHandle.gState != HAL_ETH_STATE_READY`. Не баг детектирования линка — баг в самом `HAL_ETH_Init()`.
2. **Сразу после перепрошивки и старта (холодный для прошивки, но НЕ холодный по питанию — отладчик не снимает VDD с платы) `HAL_ETH_Init()` упал с `DMABMR.SWR timeout - no RMII REF_CLK` ПРЯМО НА ПЕРВОМ ЗАПУСКЕ**, до какого-либо сетевого события. Висело так навсегда (`eth=INIT_FAIL`), пока пользователь не сделал настоящий power-cycle.
3. **После настоящего отключения/включения питания — `HAL_ETH_Init OK` сразу, без единого сбоя**, и стабильно работает дальше.

**Вывод:** сброс через `nRST` (что эквивалентно нашему `ethernetif_reset()` И сбросу через отладчик/SWD — оба оставляют VDD PHY постоянно поданным) не гарантирует перезапуск кварцевого генератора LAN8720 — иногда генератор просто не стартует после такого "тёплого" сброса. Только полное снятие/возврат питания надёжно перезапускает его. Это классический симптом недостаточного запаса по запуску кварцевого генератора (margin кварца/нагрузочных конденсаторов/ESR относительно встроенного усилителя LAN8720), не специфичный для конкретного триггера (разрыв кабеля просто оказался одним из путей, ведущих к вызову `HAL_ETH_Init()` повторно — тем самым каждый раз есть тот же шанс на неудачный старт генератора).

**Статус: причина понятна, фикс не выбран.** Варианты (обсуждается с пользователем):
- Программная мера (быстро, но не гарантирует исправление): повторять `HAL_ETH_Init()` с повторным импульсом `nRST` несколько раз при неудаче перед переходом в `INIT_FAIL`.
- Аппаратная мера (сложнее, но решает корень): управляемое питание (load switch) на VDD LAN8720, чтобы прошивка могла делать настоящий power-cycle PHY программно, либо пересмотр номиналов конденсаторов нагрузки кварца/разводки по рекомендациям датащита для увеличения запаса запуска генератора.

Решение по выбору пути ещё не принято — ждём дальнейших тестов/решения пользователя.

**Дополнительное подтверждение (2026-06-19): триггер не обязательно обрыв кабеля — сработало от выключения сервера на ПК.** Пользователь выключал TCP-сервер на компьютере (не трогал кабель/питание модуля): `[tcp_echo] server closed` → переподключения не проходят, сервер недоступен → 3 неудачи → `ethernetif_reset()` → `HAL_ETH_Init FAILED` снова. Модуль застрял в `INIT_FAIL`; включение сервера обратно через 355 сек не помогло, потому что модуль уже не выполнял Ethernet вообще (нужен power-cycle). **Значит баг триггерится ЛЮБЫМ событием, ведущим к `ethernetif_reset()`** (обрыв кабеля, падение сервера, DHCP-watchdog по таймауту и т.д.) — не специфика конкретно физического разрыва линии. Частота проявления на практике выше, чем предполагалось изначально.

**Дополнительный полезный маркер от пользователя:** YELLOW (LED1/REGOFF, индикатор Link у PHY) гаснет именно в момент, когда умирает генератор — если выключить/включить сервер ПОКА YELLOW ещё горит, восстановление проходит нормально; если YELLOW успел погаснуть, восстановление невозможно без питания. Визуально подтверждает: всё зависит от того, успел ли кварц "умереть" к моменту следующей попытки `ethernetif_reset()`, не от деталей TCP/сервера.

**Фикс применён (2026-06-19, собран, ещё не проверен на плате):** `low_level_init()` (`ethernetif.c`) теперь повторяет `HAL_ETH_Init()` до `ETH_INIT_RETRY_COUNT`=5 раз (с `HAL_ETH_DeInit()` между попытками) перед тем как сдаться и перейти в `eth=INIT_FAIL`. Каждый вызов `HAL_ETH_Init()` сам по себе заново гоняет `HAL_ETH_MspInit()` (импульс `nRST` + MDIO софт-ресет + 600мс на стабилизацию), так что каждая попытка — независимый шанс на то, что генератор заведётся. Не устраняет корень (кварц всё равно может быть на пределе запаса по запуску), но даёт до 5 независимых попыток вместо одной перед тем как застрять — учитывая что баг вероятностный, это должно резко снизить частоту попадания в неисправимый `INIT_FAIL`. Лог покажет `[eth] HAL_ETH_Init retry N/5`, если потребовалась хоть одна повторная попытка — стоит обратить внимание, если это видно часто, значит запас по запуску действительно мал и стоит вернуться к аппаратному пути (конденсаторы кварца / managed power для PHY).

Следующий шаг: прошить, понаблюдать в реальной работе (особенно сценарии "сервер выключен/включен" и "обрыв кабеля"), смотреть появляется ли `[eth] HAL_ETH_Init retry` в логе и помогает ли он избегать `INIT_FAIL` целиком.

**ОПРОВЕРГНУТО ТЕСТОМ (2026-06-19): retry-loop не помогает — это не вероятностный сбой, а устойчивое зависание.** Все 5 попыток в retry-loop упали одинаково, дважды подряд (10/10 неудач за один сеанс, второй заход — через 90 сек по DHCP-watchdog). Если бы запуск генератора был просто "иногда не получается", шанс провалить 5 попыток подряд дважды подряд был бы исчезающе мал. Значит после срабатывания это не случайность, а стабильное "зависшее" состояние, из которого `nRST` не выводит вообще — классическая болезнь Pierce-генераторов: вместо колебаний попадает в статичное DC-равновесие, и обычно только снятие питания сбрасывает смещение достаточно, чтобы он снова смог завестись. Чисто программных способов сбросить именно эту аналоговую защёлку через `nRST` нет.

**Проверка по схеме:** конденсаторы нагрузки кварца (`C9`, `C10`) — 27пФ, в рекомендованном датащитом диапазоне (15-33пФ), запас в порядке. Также нет существующей программно-управляемой цепи питания LAN8720 — VDD1A/VDD2A/VDDIO подключены прямо к общей шине +3.3V без отдельного регулятора/ключа, так что настоящий программный power-cycle PHY сейчас невозможен без аппаратной доработки (нужен load switch/P-MOSFET в цепи питания U2).

**Контрольный замер пользователя осциллографом:** сигнал на самом кварце (выводы XTAL1/XTAL2 микросхемы LAN8720) колеблется стабильно. Это говорит, что сырой кварцевый генератор исправен — но НЕ доказывает, что внутренний блок PHY, формирующий именно REFCLKO (pin14) из этого сигнала, тоже работает: это отдельный внутренний узел (PLL/буфер), который может зависать независимо от исправного кварца. Гипотеза уточнена: зависает не сам кварц, а внутренний PLL/буфер REFCLKO у PHY — то же объяснение "нужен сброс питания", просто узел немного другой.

**Диагностика добавлена (2026-06-19, собрано, не проверено на плате):** новая функция `eth_check_refclk_pa1()` (`ethernetif.c`) — временно переключает PA1 в режим входа таймера `TIM2_CH2` (AF1, "External Clock Mode 1") и считает число фронтов за ~1мс, затем возвращает PA1 в штатный режим ETH (AF11). Здоровые 50МГц на REFCLK дадут счёт в районе десятков тысяч за 1мс; если сигнал до STM32 не доходит — счётчик останется около 0. Вызывается автоматически сразу после провала всех 5 попыток `HAL_ETH_Init()`, печатает `[eth] PA1 edge count in ~1ms: N`. Это даёт программный контроль присутствия REFCLK на самом входе STM32 (PA1) без осциллографа, причём именно в момент сбоя — что точнее, чем разовый замер на кварце вручную.

Следующий шаг: прошить, дождаться `INIT_FAIL` в реальной работе, прочитать `[eth] PA1 edge count`. Если `0` — подтверждает, что сигнал реально не доходит до STM32 (внутренний PLL/буфер PHY либо обрыв по пути), и аппаратный фикс (load switch/power-cycle PHY) необходим. Если число большое (тысячи+) — значит сигнал ЕСТЬ на PA1, и тогда дело не в PHY вообще, а в чём-то на стороне STM32/HAL (нужно копать дальше в `HAL_ETH_Init()`/`DMABMR.SWR` логике).

**ОКОНЧАТЕЛЬНО ПОДТВЕРЖДЕНО (2026-06-19): `PA1 edge count = 0` во всех трёх независимых случаях `INIT_FAIL` подряд за один сеанс.** Сигнал REFCLK реально не доходит до STM32 в момент сбоя — не предположение, а прямое программное измерение. В сочетании с осциллографом на кварце (генератор колеблется исправно) картина закрыта полностью:

- Кварц (сырой генератор) — исправен, подтверждено осциллографом.
- REFCLK на PA1 STM32 — отсутствует в момент `INIT_FAIL`, подтверждено программным счётчиком (0/0/0 за 3 случая).
- Восстанавливает только снятие питания всей платы, не `nRST` (подтверждено многократно, включая 10/10 неудачных retry-попыток).

**Вывод: зависает внутренний блок LAN8720, формирующий REFCLKO (pin14) из сигнала кварца (PLL/буфер) — не сам кварц, не дорожка/пайка между pin14 и PA1** (физический обрыв был бы постоянным и не лечился бы снятием питания, а у нас лечится). Это узел внутри PHY, отдельный от генератора, который может "защёлкиваться" в нерабочем состоянии и сбрасывается только полным обесточиванием чипа — `nRST` до него не достаёт.

**Единственный оставшийся путь к программному решению (без участия человека): аппаратная доработка** — добавить управляемый ключ питания (load switch или P-MOSFET) в цепь VDD1A/VDD2A/VDDIO микросхемы U2 (LAN8720), управляемый свободным GPIO STM32, чтобы прошивка могла сама обесточить и заново включить PHY при обнаружении `PA1 edge count == 0`, вместо текущего тупика "нужен ручной power-cycle всей платы". Без этой доработки баг останется неустранимым программно — текущий retry-loop можно оставить (он не вредит, не мешает нормальной работе), но он не решает проблему.

**Статус: причина полностью и окончательно подтверждена. Решение требует аппаратной доработки (load switch на питание PHY) — ожидает решения пользователя, делать ли эту доработку.**

**ФИНАЛЬНОЕ ПОДТВЕРЖДЕНИЕ (2026-06-19), после всех программных фиксов этой сессии (ранний захват `nRST` в `main()`, 5-секундный импульс, `g_eth_hw_failed`, быстрая эскалация на `NVIC_SystemReset()`):** пользователь протестировал сценарий "сервер на ПК отвалился, через некоторое время снова включился" — связь НЕ восстановилась даже после рестарта МК (`NVIC_SystemReset()` через эскалацию) И даже после полной перезаливки новой прошивки (что эквивалентно рестарту по `nRST`/SWD, тоже не снимает VDD с платы). Восстановило только реальное физическое отключение/включение питания платы.

**Это окончательно закрывает вопрос о программном решении силами одного только `nRST`/перезапуска МК — он невозможен в принципе.** И `NVIC_SystemReset()`, и перезаливка через SWD, и ручной `nRST` — все они оставляют VDD PHY постоянно поданным, а зависает именно внутренний блок REFCLKO/PLL LAN8720, который сбрасывается только полным снятием питания (см. выводы выше). Единственный путь к полностью автоматическому восстановлению без участия человека — аппаратная доработка с управляемым ключом питания (load switch/P-MOSFET) на VDD1A/VDD2A/VDDIO микросхемы U2, управляемым свободным GPIO STM32, чтобы прошивка могла сама обесточить и заново включить именно PHY (не весь МК) при обнаружении `PA1 edge count == 0`. Без этой доработки — баг гарантированно требует ручного power-cycle при каждом попадании в это состояние, программно не лечится никак.

**Внешнее подтверждение (2026-06-19, по запросу пользователя — проверено в документации и на радиолюбительских форумах, это типовой чип LAN8720, не уникальная проблема нашей платы):**
- ESP32-форум (LAN8720A, обсуждение `nRST`): подтверждено, что `REFCLKO` физически **не останавливается во время `nRST`** — по дизайну чипа сам сигнал сброса не затрагивает блок генерации тактового сигнала. Это объясняет МЕХАНИЗМ, а не просто эмпирический факт: `nRST` не может вылечить зависший REFCLKO/PLL не из-за недостаточной длины импульса, а потому что эта часть схемы в принципе не подключена к цепи сброса.
- GitHub issue `espressif/arduino-esp32#3817`: идентичный симптом на ESP32+LAN8720 — после ресета МК (кнопкой или после перепрошивки) сеть не поднимается, помогает только полное снятие питания. В обсуждении явно сравнивается со STM32F407VG-платой (мигание LED на RJ45 при ресете отличается визуально, но сама проблема общая для чипа, а не платы).
- NXP-форум (imx6ull + LAN8720A): та же жалоба на третьей независимой платформе с тем же чипом.
- Типовое решение в сообществе (на многих ESP32-платах): отдельная GPIO-управляемая линия питания/enable для тактовой части PHY, не завязанная на `nRST` — то есть ровно тот же аппаратный подход, который предложен выше.

Датащит производителя явного errata-раздела по этому поведению не содержит, но многократные независимые подтверждения на разных платформах с разными MCU показывают: это известное свойство чипа (REFCLKO/PLL физически не сбрасывается через `nRST`), а не брак конкретной платы или огрехи прошивки.

**НОВАЯ ПРОГРАММНАЯ ПОПЫТКА (2026-06-19), по настойчивому запросу пользователя ("не верю что нет софтового варианта разбудить lan8720") — найдена в самом датащите.** Перечитан официальный SMSC datasheet (LAN8720/LAN8720i Rev 1.0) целиком. Два релевантных факта:
1. **Архитектурная диаграмма (Figure 1.2, стр.11)** показывает блок `PLL` (привязан к `XTAL1/CLKIN`, `XTAL2` — тот самый генератор REFCLKO) как ОТДЕЛЬНЫЙ от блока `Reset Control` (привязан к `nRST`, `MODE[2:0]`) — без какой-либо нарисованной связи между ними. Это прямое графическое подтверждение того, что `nRST` физически не обязан затрагивать генератор — ровно то, что показали и форумы (ESP32-форум: REFCLKO не останавливается во время `nRST`).
2. **Раздел 5.3.5.1 "General Power-Down"** — РЕГИСТР 0, БИТ 11 (`Power Down`), а не бит 15 (`Reset`, уже пробован и не помог — см. выше). Датащит: *"the entire transceiver, except the management interface, is powered-down... When bit 0.11 is cleared, the transceiver powers up and is automatically reset."* Это другой, ранее не пробованный механизм — пишется через MDIO, не трогает `nRST` вообще, описан как реально снимающий питание с "всего трансивера" (не просто сброс регистров, как делает бит 15), и при возврате из этого режима явно происходит автоматический ресет (то есть страпы типа `nINTSEL` должны перезащёлкнуться так же, как при `nRST`).

**Реализовано (`Core/Src/ethernetif.c`):** новая функция `eth_try_phy_power_cycle()` — сырой MDIO (те же регистры `MACMIIAR`/`MACMIIDR`, что и в диагностике `HAL_ETH_MspInit()`), сканирует адрес PHY, пишет `BCR=0x0800` (General Power-Down), ждёт 100мс, пишет `BCR=0x0000` (снятие power-down), ждёт ещё 100мс на запуск генератора, затем повторно меряет `eth_check_refclk_pa1()`. Вызывается в `low_level_init()` сразу после того, как retry-loop исчерпан и `PA1 edge count == 0` — **перед** эскалацией на `NVIC_SystemReset()`. Если REFCLK восстановился — `HAL_ETH_Init()` пробуется ещё раз немедленно, без перезагрузки МК. Если не восстановился — старая логика (счётчик отказов, при достижении порога `NVIC_SystemReset()`) работает как раньше, без изменений.

Собрано, билд проходит (14.19% FLASH / 40.77% RAM), **ещё не проверено на плате**. Следующий шаг: прошить, спровоцировать `INIT_FAIL`, смотреть лог — появится ли `[eth] phy power-cycle: trying General Power-Down...` и, если повезёт, `REFCLK recovered, retrying HAL_ETH_Init` без единой перезагрузки МК. Если этот путь сработает — это будет первое по-настоящему программное (без аппаратной доработки) решение всей проблемы.

**ПЕРВЫЙ ТЕСТ НА ЖЕЛЕЗЕ (2026-06-19): не помогло с задержкой 100мс.** Лог показал: `[eth] phy power-cycle: trying General Power-Down (BCR.11) toggle` — PHY отвечал по MDIO до и после (BCR=3000 в последующих диагностических дампах), но `low_level_init()` сразу вернул отказ (`eth=INIT_FAIL`, `g_eth_hw_failed=1`) — значит `eth_check_refclk_pa1()` после тоггла всё ещё показал 0. Старой диагностической строки с числом фронтов после тоггла не было (логировался результат только при успехе) — добавлено логирование `[eth] phy power-cycle: PA1 edge count after toggle: N` при любом исходе.

**Применено по аналогии с находкой про nRST:** возможно 100мс удержания `Power Down` недостаточно по той же причине, что и было с `nRST` (10мс не помогало, 5000мс — помогало) — остаточное смещение/заряд в генераторе может требовать секунд, а не миллисекунд, на спад. Увеличена выдержка `BCR=0x0800` (Power Down) с 100мс до **5000мс** перед снятием (`BCR=0x0000`), по образцу проверенного на железе фикса для `nRST`.

Собрано, билд проходит, **ещё не проверено на плате с новой 5-секундной выдержкой**. Следующий шаг: прошить, спровоцировать `INIT_FAIL`, смотреть `[eth] phy power-cycle: PA1 edge count after toggle: N` — если `N=0` снова, значит General Power-Down тоже не достаёт до зависшего блока (как и nRST), и программных вариантов по датащиту больше не остаётся — переходим к аппаратной доработке (load switch на VDD PHY).

**ОКОНЧАТЕЛЬНО ОПРОВЕРГНУТО (2026-06-19): `General Power-Down` с 5-секундной выдержкой ТОЖЕ не помог.** Лог на реальной плате (модуль был залит уже в зависшем состоянии — REFCLK мёртв с самого первого холодного старта): `PA1 edge count after toggle: 0` — то же самое, что и с короткой 100мс выдержкой. Оба документированных в датащите программных механизма (`nRST` и `BCR.11 General Power-Down`), с обоими вариантами длительности (короткой и 5-секундной), дают идентичный результат: генератор не восстанавливается. **Это исчерпывает все программные пути, найденные в датащите производителя.**

**Побочное подтверждение — быстрая эскалация работает как задумано:** в логе видно `t=22323ms` до первого `eth=INIT_FAIL` в heartbeat, затем быстрый (не 90-секундный) переход на `ethernetif_reset()` через `ETH_INIT_FAIL_RETRY_MS`, затем после второго подряд отказа — `NVIC_SystemReset()`. Полный цикл от холодного старта до перезагрузки МК ≈ 20-25 сек, что соответствует ожиданиям (фикс `g_eth_hw_failed` из этой сессии подтверждён работающим на железе).

**Итоговое поведение при зависшем генераторе: плата теперь просто бесконечно перезагружается по кругу** (~20-25 сек на цикл) без какого-либо прогресса, пока не будет снято питание руками — это лучше, чем зависание на минуты без всякой реакции (как было раньше), но программно проблему это не решает: REFCLKO/PLL-блок LAN8720 после зависания не восстанавливается ничем, что доступно через `nRST` или MDIO. **Подтверждено двойным независимым тестом (короткая и длинная выдержка для обоих механизмов) — дальнейших программных попыток по официальной документации не остаётся.**

**Статус: вопрос программного решения закрыт окончательно.** Единственный оставшийся путь к полностью автоматическому восстановлению без участия человека — аппаратная доработка с управляемым ключом питания (load switch/P-MOSFET) на VDD1A/VDD2A/VDDIO микросхемы U2, описанная выше. Текущий бесконечный reboot-loop можно оставить как есть (он не вредит, просто ждёт человека), либо добавить программный "тормоз" (например, прекращать попытки после N перезагрузок и просто гореть LED-индикатором ошибки, экономя циклы перепрошивки/износ) — но это не решает корень, только меняет поведение ожидания.

## НАСТОЯЩАЯ ПРИЧИНА НАЙДЕНА (2026-06-19): слабый резистор на страпе nINTSEL, а не зависание PLL

Пользователь справедливо усомнился в выводе "нужен ресет по питанию" для массового, повсеместно используемого чипа — и оказался прав. Пересмотр с нуля, по шагам:

1. **Проверка через датащит производителя и апноуты Microchip**: ни в одном референсном дизайне LAN8720 (включая собственный Application Diagram из датащита) нет управляемого ключа питания PHY — VDD1A/VDD2A/VDDIO всегда просто на шине 3.3В без доп. защиты. Если бы "зависание, лечится только питанием" было известным свойством чипа — производитель рекомендовал бы защиту. Это не нашлось ни у Microchip, ни в их апноутах.

2. **Осциллограф НЕЗАВИСИМО подтвердил программное измерение**, но дал ключевую деталь, которую программное измерение не видело: на ноге 14 (REFCLKO) во время сбоя — не "тишина на нуле", а **статичные +3.3В**. Это не сигнатура "зависшего посреди колебания генератора", а сигнатура **пассивно подтянутого неактивного входа/выхода** (как раз то, что даёт `nINT` в режиме ожидания — открытый сток с подтяжкой к VDD).

3. **Замер на ноге 2 (LED2/nINTSEL)** во время того же сбоя — тоже +3.3В. Сам по себе этот замер не различал две версии (нормальная работа LED2 в режиме REFCLKO тоже может давать HIGH), но навёл на гипотезу: если страп `nINTSEL` защёлкнулся в `1` (режим `nINT`/REF_CLK In) вместо нужного `0` (режим `REFCLKO`) — на ноге 14 будет неактивный `nINT` (статично HIGH через подтяжку), а REFCLKO просто не генерируется вообще, что идеально объясняет и статичный уровень, и работающий MDIO (SMI-блок не зависит от режима REF_CLK), и вероятностный характер бага (гонка при защёлкивании страпа на каждом сбросе, а не детерминированная аппаратная защёлка).

4. **Корень гонки**: страп `nINTSEL` (нога 2) до этого был притянут к GND резистором **6.8кОм** (см. историю проекта — раньше был кривой R37, потом подпайка 1кОм, потом заменено на постоянные 6.8кОм). Против внутренней подтяжки LAN8720 (**67кОм типично**, согласно датащиту, тип буфера IOPU) это даёт статически правильный низкий уровень (~0.3В), но **во время самого переключения `nRST`** (быстрый переходный процесс, наводки, паразитная емкость) тонкий резистор 6.8кОм мог не успевать гарантированно выиграть гонку за установившийся уровень к моменту защёлкивания (датащит, T11.2: "Configuration input setup to nRST rising" = min 200нс) — отсюда вероятностное, не 100%-ное попадание в правильный режим при каждом сбросе/перезапуске.

**Фикс (аппаратный, сделан пользователем 2026-06-19): резистор на ноге 2 заменён с 6.8кОм на 1кОм.** Это гораздо более уверенно выигрывает гонку против внутренних 67кОм (статический уровень ~0.04В вместо ~0.3В, и более быстрый RC-переход за счёт меньшего сопротивления при той же паразитной емкости). **После замены — проблема, по первому впечатлению пользователя, исчезла** ("похоже это решило проблему").

**Важная оговорка:** баг был вероятностным (не каждый сброс/перезапуск приводил к сбою), поэтому одного успешного теста недостаточно для полной уверенности — нужно понаблюдать за работой в течение длительного времени (несколько дней реальной работы, многократные перезапуски/циклы сервера/обрывы кабеля), прежде чем считать вопрос окончательно закрытым.

**Если фикс подтвердится длительным наблюдением:** это означает, что ВСЯ цепочка программных мер из этой и прошлых сессий (ранний захват `nRST` в `main()`, 5-секундная выдержка `nRST`, флаг `g_eth_hw_failed`, быстрая эскалация, `General Power-Down` через MDIO) боролась с СИМПТОМОМ (PHY иногда защёлкивается в нерабочий режим), а не с причиной. Это не значит, что эти меры бесполезны — быстрая эскалация и `NVIC_SystemReset()` всё равно дают automatic recovery даже в тех редких случаях, когда гонка всё же проигрывается (теперь реже, но физически возможность не исключена полностью, поскольку резистор всё равно конечен, а не идеальный короткий замыкатель) — но корневая причина была не "аппаратно неустранимое зависание PLL", а конкретный, дешёво исправимый страп-резистор.

**Уточнение (2026-06-19): зависание не вечное — самовосстановилось через несколько минут без участия питания.** Пользователь наблюдал самостоятельное восстановление связи спустя пару минут простого ожидания (90-секундный DHCP-watchdog продолжал вызывать `ethernetif_reset()` по таймауту; через несколько таких редких циклов одна из попыток сработала сама). Это меняет картину: зависание REFCLKO-блока — не постоянная защёлка, которую снимает только питание, а зависание с ОЧЕНЬ долгой постоянной времени восстановления через `nRST` (десятки секунд, не доли секунды). Быстрые повторы retry-loop (5 попыток за ~3 секунды, интервал ~600мс между ними) не дают этому времени — отсюда 10/10 неудач там. Редкие повторы (раз в 90 сек, через существующий watchdog) — дают, и через несколько таких попыток восстановление случилось без питания.

**Рабочая гипотеза:** скорее всего остаточный заряд/смещение в цепи генератора PHY не успевает стечь за доли секунды между быстрыми повторами retry-loop, но стекает за десятки секунд естественной утечки между редкими попытками watchdog'а.

**Открытый вопрос:** программный путь (редкие повторы, не частые) может оказаться рабочим решением без аппаратной доработки — НО неизвестно среднее время восстановления (минуты — приемлемо? десятки минут — нет?) и стабильность этого поведения (повторится ли так же надёжно в следующий раз). Нужно больше наблюдений, прежде чем считать вопрос закрытым программно.

**Применено (2026-06-19, собрано, не проверено на плате): растянутые интервалы в retry-loop.** `ETH_INIT_RETRY_DELAY_MS`=3000 (`ethernetif.c`) — добавлена пауза 3 сек перед каждым повтором `HAL_ETH_Init()` внутри `low_level_init()` (между `HAL_ETH_DeInit()` и следующим `HAL_ETH_Init()`), вместо прежних "впритык" повторов (~600мс между попытками). Цель — напрямую проверить и использовать гипотезу про долгую постоянную времени восстановления: 5 попыток с интервалом 3 сек дают ~15 сек суммарной растяжки внутри одного вызова `low_level_init()` (раньше — общая длительность одного вызова была ~3 сек). Блокирует главный цикл на это время, но это приемлемо — вызывается только когда ETH уже не работает (`ethernetif_reset()`/`INIT_FAIL`-восстановление), терять нечего.

Следующий шаг: прошить, дождаться `INIT_FAIL` в реальной работе, смотреть — стало ли восстановление чаще происходить уже ВНУТРИ самого retry-loop (видно по логу: меньше полных провалов "FAILED after retries", больше успешных `HAL_ETH_Init OK` после retry 2-5), а не только через внешний 90-секундный watchdog с интервалом в несколько циклов.

**НАСТОЯЩИЙ КОРЕНЬ И ФИКС НАЙДЕНЫ (2026-06-19): дело не в паузах между попытками, а в ДЛИНЕ самого импульса `nRST`.** Растягивание интервалов между retry не помогло. Пользователь проверил вручную: штатный импульс сброса (пинцетом замкнул pin15/nRST на GND) длиной **5 секунд** надёжно восстановил связь, в отличие от штатных **10мс**, которые держала прошивка (`HAL_ETH_MspInit()`, `stm32f4xx_hal_msp.c`). То есть внутреннему блоку REFCLKO/PLL PHY нужно гораздо дольше держать `nRST` в LOW, чтобы реально сбросить застрявшее состояние — 10мс (минимум по датащиту, обычно достаточный для штатного старта) недостаточно для восстановления именно из этого зависшего состояния.

**Фикс применён (`Core/Src/stm32f4xx_hal_msp.c`):** `HAL_GPIO_WritePin(...GPIO_PIN_RESET); HAL_Delay(10);` → `HAL_Delay(5000)` — держим `nRST` в LOW 5 секунд вместо 10мс, по аналогии с проверенным вручную фиксом. Это применяется при КАЖДОМ вызове `HAL_ETH_Init()` (значит и при обычной загрузке — будет на ~5 сек дольше один раз при старте, не критично).

**Сопутствующее (`Core/Src/ethernetif.c`):** т.к. настоящий фикс — длина импульса, а не пауза между попытками, убрана растянутая 3-секундная пауза между retry (была избыточна), `ETH_INIT_RETRY_DELAY_MS`→200, `ETH_INIT_RETRY_COUNT`→3 (retry-loop теперь просто дешёвая подстраховка, а не основной механизм восстановления).

Собрано, билд проходит, **ещё не проверено на плате**. Следующий шаг: прошить, дождаться/спровоцировать `INIT_FAIL` (выключить сервер на ПК или выдернуть кабель, дождаться 3 неудачных коннектов), проверить — восстанавливается ли уже с первой/второй попытки внутри retry-loop, без участия watchdog'а и без ручного питания.

**ОПРОВЕРГНУТО ТЕСТОМ (2026-06-19): 5-секундный `nRST` САМ ПО СЕБЕ не помог.** 9 неудач подряд (3 цикла сброса × 3 retry-попытки), каждый раз `PA1 edge count = 0`, идентично прежнему поведению. Длина импульса `nRST` оказалась не единственным фактором.

**Найдена вероятная причина:** в `HAL_ETH_MspInit()` (`stm32f4xx_hal_msp.c`) ПОСЛЕ аппаратного импульса `nRST` всегда дополнительно шёл программный MDIO-сброс PHY (`BCR=0x8000`, "restarts crystal osc + PLL", добавлен в одну из прошлых сессий как более ранняя попытка решить эту же проблему). Гипотеза: именно этот ДОПОЛНИТЕЛЬНЫЙ программный перезапуск PLL может сам не залочиться и заново сломать то, что только что успешно восстановил длинный `nRST` — а в твоём ручном тесте пинцетом такого второго шага не было вообще, только аппаратный `nRST`.

**Фикс применён (`stm32f4xx_hal_msp.c`):** убрана сама запись программного сброса (`MDIO_WR(...0x8000)`) и цикл ожидания/задержка 500мс после неё — оставлена только диагностика (чтение и вывод ID2/BCR/BSR/MCSR/SMR, это просто чтения регистров, безопасно). Теперь после смены strap'ов и пинов остаётся только 5-секундный аппаратный `nRST`, точно повторяя условия твоего успешного ручного теста.

Собрано, билд проходит, **ещё не проверено на плате**. Следующий шаг: прошить, спровоцировать `INIT_FAIL`, проверить — восстанавливается ли наконец с одной из попыток внутри retry-loop теперь, когда программный MDIO-сброс убран и остался только длинный `nRST`.

**ОПРОВЕРГНУТО ТЕСТОМ (2026-06-19): и это не помогло само по себе.** Даже без программного MDIO-сброса, retry-loop с длинным `nRST` не восстановил связь. Пользователь восстановил руками: во время перезапуска платы зажимал пинцетом линию `nRST` (вывод у `R3`) на землю.

**Найдена вторая причина:** между подачей питания и первым касанием `PB10` прошивкой (внутри `HAL_ETH_MspInit()`, вызывается из `MX_LWIP_Init()`) проходит `HAL_Init()` → `SystemClock_Config()` (старт HSE/PLL STM32) → `MX_GPIO_Init()` → инициализация UART1/UART3. Всё это время `nRST` PHY управляется только пассивным `R3` (10кОм pull-up) — PHY может выйти из сброса сам, пока питание/такты ещё не устоялись. Ручное удержание `nRST` с начала перезапуска (как делал пользователь) убирает это окно; программный сброс из `ethernetif_reset()` во время работы — не может, т.к. он просто переключает `nRST` заново уже посреди уже всё-равно стабильной работы платы, это другая ситуация.

**Фикс применён (`Core/Src/main.c`):** добавлен явный захват `PB10`/`nRST` в LOW самым первым действием в `main()`, сразу после `HAL_Init()`, до `SystemClock_Config()` и любой другой инициализации периферии. Реальные 5 секунд удержания + отпускание всё равно происходят позже, внутри `HAL_ETH_MspInit()` как раньше — но теперь `nRST` гарантированно прижат к земле с самого начала перезапуска прошивки, а не только начиная с того момента, когда код дошёл до `MX_LWIP_Init()`.

**Важная оговорка:** это помогает только полному перезапуску МК (кнопка ресета/питание/перепрошивка — что угодно, что заново выполняет `main()` с начала). Это НЕ помогает автоматическому восстановлению во время работы (`ethernetif_reset()` из watchdog'а внутри уже работающей программы, без перезапуска) — туда этот фикс не доходит, так как тот путь не проходит через начало `main()`.

**Эскалация добавлена (`Core/Src/main.c`, DHCP-watchdog):** если `ethernetif_reset()` через watchdog не помогает `ETH_RESET_ESCALATE_AFTER`=3 раза подряд (т.е. ~4.5 минуты без IP несмотря на попытки) — вместо очередной попытки `ethernetif_reset()` на месте прошивка теперь вызывает `NVIC_SystemReset()` — полный программный перезапуск МК. Это автоматически воспроизводит ручной приём пользователя (перезапуск + раннее удержание `nRST`) без участия человека. Лог перед этим: `[lwip] ETH reset escalation exhausted, rebooting MCU`.

Собрано, билд проходит, **ещё не проверено на плате**. Следующий шаг: прошить, спровоцировать продолжительный `INIT_FAIL` (например, временно уменьшить `DHCP_STUCK_TIMEOUT_MS` для быстрого теста), убедиться что после 3 неудачных `ethernetif_reset()` происходит `NVIC_SystemReset()` и связь восстанавливается уже после полной перезагрузки, без участия человека и без снятия питания.

**ТЕСТ ПОКАЗАЛ: даже ранний захват `nRST` в `main()` не спас от провала на самом первом холодном старте** — `HAL_ETH_Init FAILED`/`PA1 edge count: 0` сразу при включении, затем ещё 2 цикла `ethernetif_reset()` по 90 сек ожидания каждый — итого почти 4 минуты простоя, прежде чем должна была сработать эскалация (3 цикла × 90 сек). Пользователь справедливо спросил: зачем ждать целых 90 секунд между попытками, если `eth_check_refclk_pa1()` уже даёт однозначный ответ ("REFCLK=0") за секунды?

**Оптимизация скорости реакции (2026-06-19, `ethernetif.c`):** добавлен отдельный, более быстрый путь эскалации — счётчик `s_init_fail_streak` внутри `low_level_init()`, считает подряд идущие провалы именно `HAL_ETH_Init()` (а не общий "нет IP", как в `main.c`). При достижении `ETH_INIT_FAIL_REBOOT_THRESHOLD`=2 — `NVIC_SystemReset()` вызывается СРАЗУ, не дожидаясь 90-секундного DHCP-watchdog'а в `main.c`. Поскольку каждая попытка `low_level_init()` теперь и так занимает ~17 сек (3×retry с 5-секundным `nRST`), полный цикл до перезагрузки теперь ~34 секунды вместо ~4.5 минут. Старая эскалация в `main.c` (привязанная к общему "нет IP за 90×3 сек") оставлена как более медленный, общий fallback на случай других причин отсутствия IP (не связанных напрямую с провалом `HAL_ETH_Init()`, например застрявший DHCP при исправном ETH).

Собрано, билд проходит, **ещё не проверено на плате**.

**Найдена реальная причина, почему "ускорение" не было заметно (2026-06-19):** счётчик быстрой эскалации в `ethernetif.c` увеличивается только при ПОВТОРНОМ вызове `low_level_init()` — а единственное, что вызывает повторную попытку при полном отсутствии IP, это всё тот же медленный 90-секундный watchdog в `main.c` (быстрый 3-strikes механизм `tcp_echo_client.c` не запускается вообще, т.к. без IP `tcp_echo_client_poll()` не вызывается). То есть первые ~90 сек были неизбежны при прежней логике — быстрая эскалация просто не успевала получить второй шанс раньше.

**Фикс (`Core/Src/main.c`):** добавлен отдельный, короткий таймаут `ETH_INIT_FAIL_RETRY_MS`=2000 — если `g_eth_debug_marker == 100` (т.е. известно, что именно `HAL_ETH_Init()` провалился, а не "DHCP просто долго думает"), watchdog ждёт не 90 сек, а всего 2 сек перед повторной попыткой `ethernetif_reset()`. Теперь быстрая эскалация в `ethernetif.c` (порог 2 подряд провала) реально успевает сработать быстро: ~17 сек (первый провал при загрузке) + 2 сек + ~17 сек (второй провал) ≈ **36 секунд** до `NVIC_SystemReset()`, вместо прежних ~90+ секунд. Старый 90-секундный таймаут остался для другого, не пересекающегося случая — когда сама ETH-периферия в порядке, а просто DHCP-сервер долго не отвечает.

Собрано, билд проходит, **ещё не проверено на плате**. Следующий шаг: прошить, спровоцировать `INIT_FAIL` при загрузке, замерить реальное время до `NVIC_SystemReset()` — должно быть около 30-40 секунд, а не минуты.

**НАЙДЕН БАГ В САМОЙ ЛОГИКЕ БЫСТРОЙ ЭСКАЛАЦИИ (2026-06-19): условие `g_eth_debug_marker == 100U` в `main.c` НИКОГДА не было истинным.** При анализе очередного "свежего" лога обнаружилось: heartbeat показывал `eth=LINK_DOWN` вместо ожидаемого `eth=INIT_FAIL`, хотя `phy=-5` (замороженное значение `LAN8742_STATUS_READ_ERROR`) однозначно говорило, что `HAL_ETH_Init()` действительно провалился (это значение `ethernetif_poll_link()` даже не доходит до записи, т.к. в начале функции есть `if (EthHandle.gState != HAL_ETH_STATE_READY) return;` — а `gState` остаётся не-`READY` именно при провале `HAL_ETH_Init()`). Причина: `MX_LWIP_Init()` (`main.c`) вызывает `netif_add()`, которая внутри сразу вызывает `ethernetif_init()` → `low_level_init()` — и именно ТАМ при провале выставляется `g_eth_debug_marker = 100`. Но сразу после возврата из `netif_add()`, безусловно, идёт `g_eth_debug_marker = 52;` — затирая `100` буквально следующей строкой. Из-за этого: (а) heartbeat никогда не показывал `INIT_FAIL`; (б) условие `(g_eth_debug_marker == 100U) ? ETH_INIT_FAIL_RETRY_MS : DHCP_STUCK_TIMEOUT_MS` всегда выбирало медленный 90-секундный путь — то есть **весь предыдущий фикс с быстрым 2-секундным таймаутом фактически никогда не работал на практике**, хотя код был написан верно по отдельности.

**Фикс применён:** добавлен отдельный флаг `uint8_t g_eth_hw_failed` (`ethernetif.c`/`.h`) — пишется ТОЛЬКО в `low_level_init()`: `=1` при провале `HAL_ETH_Init()` после всех retry, `=0` при успехе. Больше ничто в проекте этот флаг не трогает, поэтому затереть его так же, как `g_eth_debug_marker`, не может. В `main.c` обе проверки (`ETH_INIT_FAIL_RETRY_MS` watchdog и heartbeat-форматирование `INIT_FAIL`/`LINK_UP`/`LINK_DOWN`) переведены на `g_eth_hw_failed`. `g_eth_debug_marker` оставлен как был — используется только для тонкой пошаговой диагностики внутри `low_level_init()`/`MX_LWIP_Init()`, для решения "сломан ли ETH" теперь не годится и не используется.

Собрано, билд проходит (**проверено локально через `cmake --build build`, без ошибок**), **ещё не проверено на плате**. Следующий шаг: прошить, спровоцировать `INIT_FAIL`, убедиться что heartbeat теперь действительно показывает `eth=INIT_FAIL`, и что полный цикл до `NVIC_SystemReset()` укладывается в ожидаемые ~30-40 сек, а не 90+.

**Добавлена печать даты/времени сборки прошивки при каждом перезапуске (2026-06-19, по явному запросу пользователя — "для исключения сомнений").** В `main()` (`Core/Src/main.c`), сразу после инициализации UART1 и перед `MX_LWIP_Init()`, добавлена строка лога `[boot] firmware built <DATE> <TIME>\r\n`, используя `__DATE__`/`__TIME__` — эти макросы подставляются компилятором на момент сборки конкретного `.elf`, поэтому не могут "устареть" в отличие от вручную поддерживаемого номера версии. Печатается при любом перезапуске — и холодном старте, и после `NVIC_SystemReset()` (escalation), что позволяет однозначно сопоставить присланный лог с конкретной прошитой сборкой.

## Подтверждение номинала страп-резистора по официальной схеме Microchip (2026-06-19)

Проверена официальная схема `EVB8720 Evaluation Board Schematic.pdf` (eval-плата LAN8720A от Microchip/SMSC, лист 2). Все страп-резисторы (REGOFF, MODE[0:2], PHYADD0) у вендора — **4.75 кОм 1%**. Для LED2/nINTSEL у них отдельная, ещё более жёсткая схема: `R2=0Ω` (прямая перемычка) + `R39=4.75кОм` в цепи самого светодиода — то есть вендор вообще не оставляет этот страп на слабой подтяжке. Это прямое подтверждение задним числом: бывший резистор **6.8кОм** на этой плате был слабее всего, что встречается в эталонной схеме производителя; поставленный **1кОм** — даже более решительный, чем рекомендация Microchip, и это нормально (запас, а не риск).

## Ускорение восстановления (2026-06-19): сокращены тайминги retry/reset, раз корень бага (страп) уже исправлен

Поскольку длинные выдержки (`nRST`=5с, MDIO power-down=5с) и большое количество повторов были защитными мерами под СТАРУЮ, неверную теорию ("неустранимое зависание PLL") — после нахождения настоящей причины (страп-резистор) они признаны избыточными и сокращены:

- `Core/Src/stm32f4xx_hal_msp.c`: hold `nRST` **5000мс → 2000мс**.
- `Core/Src/ethernetif.c`: `ETH_INIT_RETRY_COUNT` **3 → 1**; hold в `eth_try_phy_power_cycle()` **5000мс → 200мс** (этот MDIO-фолбэк подтверждённо тестами никогда не помогал ни на 100мс, ни на 5с — держать его долго бессмысленно).

Дополнительно, по логу с отдельным, новым отказом — ETH-железо и линк восстанавливаются нормально после `ethernetif_reset()` (`eth=LINK_UP`, корректный REFCLK), но DHCP не получает IP даже после пары программных сбросов подряд, при этом полный `NVIC_SystemReset()` решает за ~5 секунд. Раз мягкий сброс ненадёжен именно в этом отказе, сокращены тайминги до перехода к надёжно работающей перезагрузке:

- `Core/Src/main.c`: `DHCP_STUCK_TIMEOUT_MS` **90000 → 15000мс**; `ETH_RESET_ESCALATE_AFTER` **3 → 2**.

Итого худший случай зависания сократился с ~270+ секунд до ~30-40 секунд перед автоматической перезагрузкой МК. Собрано, билд проходит (`cmake --build build`).

**Открытый вопрос (не диагностирован до конца):** почему `ethernetif_reset()` не восстанавливает DHCP при том, что `dhcp_stop()/dhcp_cleanup()/mem_init()/memp_init()` выглядят корректными по исходникам lwIP (проверено: `dhcp_release_and_stop()` корректно декрементирует `dhcp_pcb_refcount` и зовёт `udp_remove()`, `udp_pcbs`/`tcp_active_pcbs` не должны оставаться "грязными" в этом сценарии, поскольку TCP-PCB ещё не создавался — `tcp=I` всё время). Похоже, причина не в учёте PCB в куче, а в чём-то другом (сетевая сторона — анти-флуд на сервере/роутере при повторных DISCOVER с того же MAC, либо момент вызова `dhcp_start()` относительно завершения автонеготиации PHY-линка). Текущая мера — не лечить, а быстрее переходить к перезагрузке, которая подтверждённо работает.

**ПОДТВЕРЖДЕНИЕ ПОЛЬЗОВАТЕЛЯ (2026-06-19): "пока работает - подхватывает отвалившийся сервер".** Первое реальное наблюдение того, ради чего всё затевалось изначально (модуль сам восстанавливает связь после падения и возвращения сервера, без участия человека) — похоже, заработало. Это первое позитивное подтверждение после сокращения таймингов; как и с резистором, нужно больше времени наблюдения, прежде чем закрывать тему окончательно.

## Веб-настройка таблицей + IP по умолчанию без DHCP (2026-09-24)

**Что сделано.** Страница `http://<IP модуля>/` (`Config/Src/config_http.c`) — таблица
«параметр | образец записи | текущее значение | новое значение» и кнопки
**Save** (записать во Flash, применить после рестарта — `device_config_store()` пишет
копию, не трогая рабочую в ОЗУ), **Cancel** (выйти без изменений), **Restart** (записать и
перезапустить). Подробности — `Config/README.md`.
В режиме DHCP, если сервер не ответил за 10 с, модуль берёт «IP по умолчанию» (поле
статического IP, из коробки `192.168.1.100/24`); на экране `DHCP: NO-DEFAULT IP`.

**Проблема 1: резервный IP ставился сразу при появлении линка.** Таймер стартовал как
`HAL_GetTick() | 1U` — при чётном тике старт на 1 мс в будущем, разность в ту же
миллисекунду = `0xFFFFFFFF` ≥ 10000. Исправлено отдельным флагом `dhcp_waiting`.

**Проблема 2 (главная): модуль уходил на 192.168.1.100 при живом роутере.** Лог UART:
модуль получал `10.0.1.140`, но TCP-сервер `10.0.1.16:5000` (ПК) не был запущен →
`tcp_echo_client` после 3 неудачных подключений вызывал `ethernetif_reset()` («сеть
зависла») → после этого сброса DHCP не проходит (давний открытый вопрос, см. выше) →
через 10 с резервный IP. Раньше это маскировал watchdog, перезагружавший МК через ~30 с.
Исправления:
- `tcp_echo_client.c`: `network_path_alive()` — если в ARP-таблице есть разрешённая
  запись сервера (или шлюза, если сервер вне подсети), значит TX и RX работают, отказ
  подключения = «сервер не слушает», ETH **не** сбрасывается. Сброс только для «глухой» сети.
- `main.c`: на резервном IP эхо-клиент не запускается (маршрута к серверу нет, его отказы
  только провоцировали сбросы).
- `main.c`: на резервном IP DHCP перезапускается каждые 30 с; если аренды нет 60 с и к
  веб-странице/порту 7000 никто не обращался (`device_config_touch()` /
  `device_config_last_access()`, 5 мин простоя) — `NVIC_SystemReset()`, как старая эскалация.
  Таймер не сбрасывается при кратком падении линка от `ethernetif_reset()` (из-за этого
  перезагрузка сработала только через 303 с вместо 70).

**Проверено:** тестовые сборки (резервный IP через 1 мс + принудительный `dhcp_stop()`)
— повтор DHCP возвращает `10.0.1.140`, без повтора срабатывает перезагрузка; рабочая
сборка — 90 с при незапущенном сервере: 8 отказов подключения, ни одного сброса ETH,
адрес держится. **Пользователь подтвердил после отключения питания: работает.**

**Как отлаживать:** лог — USART1 через CH340 (`COM6`, 921600); счётчики lwIP можно читать
на ходу без остановки МК: `openocd ... -c init -c "mdh <&lwip_stats> 12" -c shutdown`
(адрес из `arm-none-eabi-nm build/*.elf`). `openocd -c "reset run"` = программный сброс —
холодный старт он не воспроизводит, питание снимает только пользователь.
Внимание: `scripts/flash-progress.ps1` делает mass-erase — настройки из Flash сбрасываются
на значения по умолчанию.

## Быстрый контроль

- MCU: `STM32F407VGT6`
- Частота: `160 MHz`
- Проект CubeMX: `stm32f407vg_lan_v1.ioc`
- Исходники: `Core/`, `Drivers/`
- Схема: `f407.sch`

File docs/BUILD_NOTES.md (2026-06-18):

# Build Status & Recovery

## ✅ Successful Build State (2026-06-16)

**Build Output**: `build/stm32f407vg_lan_v1.*` (elf, bin, hex, map)
- Flash usage: 46.4 KB / 1024 KB (4.43%)
- RAM usage: 2.6 KB / 128 KB (1.99%)

## Key Fixes Applied

### 1. MCU Define Fix (Critical)
- **File**: `CMakeLists.txt`
- **Fix**: Changed `-D${MCU}xx` → `-D${MCU_DEFINE}` where `MCU_DEFINE = STM32F407xx`
- **Reason**: Device headers require exact `-DSTM32F407xx` (not `-DSTM32F407VGxx`)
- **Impact**: Enables correct peripheral structure definitions (USART_TypeDef, etc.)

### 2. ASM Compiler Flags (Critical)
- **File**: `CMakeLists.txt`
- **Fix**: Added `set(CMAKE_ASM_FLAGS "-mcpu=cortex-m4 -mthumb -mfpu=fpv4-sp-d16 -mfloat-abi=hard -x assembler-with-cpp")`
- **Reason**: ASM must match C compiler flags for linker compatibility (VFP hard-float)
- **Impact**: Prevents linker "uses VFP register arguments" errors

### 3. Linker Flags Enhancement (Critical)
- **File**: `CMakeLists.txt`
- **Fix**: Added `-mcpu -mthumb -mfpu -mfloat-abi` to `target_link_options()`
- **Reason**: Ensures output ELF is marked with correct ABI attributes
- **Impact**: Links correct multilib variant (thumb/v7e-m+fp/hard)

### 4. Linker Script Update
- **File**: `linker_script.ld`
- **Fix**: Added `end = .;` symbol after `.bss` section
- **Reason**: Required by `libc.a` for dynamic memory allocation (sbrk)
- **Impact**: Eliminates "undefined reference to `end`" error

## Quick Start After Project Reopening

```bash
cd e:\MEGAsync_R91\Mega_Git_R91\VSCode\stm32f407_lan\stm32f407vg_lan_v1

# Clean configure
cmake -S . -B build -G Ninja "-DCMAKE_TOOLCHAIN_FILE=$(Get-Location)\toolchain-arm-none-eabi.cmake"

# Build
cmake --build build --config Release

# Output files created at:
# - build/stm32f407vg_lan_v1.elf
# - build/stm32f407vg_lan_v1.bin
# - build/stm32f407vg_lan_v1.hex
```

## VSCode Tasks Available

1. **CMake: Configure** — Reconfigures CMake
2. **CMake: Build** — Builds project
3. **Flash STM32F407VG** — Programs device via ST-Link
4. **Cortex Debug (ST-Link)** — Starts debugger

All configured in `.vscode/tasks.json` and `.vscode/launch.json`

## Warnings (Safe to Ignore)

The following linker warnings are expected with `-specs=nosys.specs`:
- `_close is not implemented`
- `_lseek is not implemented`
- `_read is not implemented`
- `_write is not implemented`

These functions are not used by this bare-metal firmware. If needed later, implement stubs in `Core/Src/syscalls.c`.

## Files Modified

1. ✅ `CMakeLists.txt` — MCU define, ASM flags, linker options
2. ✅ `Core/Startup/startup_stm32f407xx.s` — Vector table + Reset_Handler
3. ✅ `linker_script.ld` — Added `end` symbol
4. ✅ `.vscode/c_cpp_properties.json` — Correct tool paths
5. ✅ `.vscode/settings.json` — Correct tool paths

## Tool Paths (Windows Machine)

- CMake: `C:\Users\svgra\AppData\Local\stm32cube\bundles\cmake\4.0.1+st.3\bin\cmake.exe`
- Ninja: `C:\ninja\ninja.exe`
- ARM GCC: `C:\Program Files (x86)\Arm\GNU Toolchain mingw-w64-i686-arm-none-eabi\bin`
- OpenOCD: `C:\OpenOCD\bin\openocd.exe`

## Next Steps

1. Test flashing via ST-Link: `cmake --build build --target flash` or manual OpenOCD
2. Test debugging with Cortex-Debug extension
3. Add application code to `Core/Src/main.c`

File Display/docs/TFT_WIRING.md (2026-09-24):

# Подключение 3.5" TFT (ST7796S, 4-wire SPI) к плате f407

Модуль: 9-контактный разъём «SPI» (левый край модуля, сверху вниз, «1» у GND).
Перемычки IM0–IM2 на модуле — по столбцу **SPI** таблицы на шелкографии.
Плата: вид сверху, координаты из `f407.brd`; пин 1 разъёмов — круглая площадка.

Всего 2 разъёма на плате (**SV4 + SV1**) — DC/RST/BL сгруппированы на трёх
соседних пинах SV1 (8/9/10). SV5 в разводке TFT не участвует.

Плюс кнопка переключения страниц экрана — **SV1.7 (PC6)**, четвёртый провод на SV1,
прямо рядом с BL/RST/DC. Один вывод кнопки на этот пин, второй — на GND (например,
SV4.6). Подтяжка к +3.3 В — **внутренняя, программная** (`GPIO_PULLUP` в
`TFT_App_GPIO_Init()`, `Display/Src/tft_app.c`), внешний резистор не нужен: пин в покое
читается как «1», нажатие кнопки замыкает на GND — «0».

## Соединения (вариант А: SV4 + SV1, 9 проводов)

```
   МОДУЛЬ TFT (разъём SPI)                       ПЛАТА f407
   ┌──────────────┐
 1 │ GND          │────────────────────────────  SV4.6  GND
 2 │ VCC          │────────────────────────────  SV4.5  +5V   (*)
 3 │ SCL          │────────────────────────────  SV4.3  PC10  SPI3_SCK
 4 │ SDA          │────────────────────────────  SV4.1  PC12  SPI3_MOSI
 5 │ RST          │────────────────────────────  SV1.9  PD5
 6 │ DC           │────────────────────────────  SV1.10 PD6
 7 │ CS           │────────────────────────────  SV4.4  PA15
 8 │ BL           │────────────────────────────  SV1.8  PC7   (1 = подсветка вкл)
 9 │ SDA-O        │─ ─ ─ ─ ─ ─ ─ ─ ─ ─ ─ ─ ─ ─   SV4.2  PC11  SPI3_MISO  (опц., только чтение ID)
   └──────────────┘
```

(*) +5V — если у модуля есть свой стабилизатор 3.3 V (обычно есть, на фото U8). Если модуль
чисто 3.3-вольтовый — VCC брать с **SV2.1 (+3V3)**.

PC7/PD5/PD6 на этой плате подписаны как USART6/USART2 TX-RX (см. `hardware/BOARD.md`) —
пример-разводка для других применений; ни USART2, ни USART6 в текущей прошивке не
используются (заняты только USART1 и USART3), так что все три пина свободны под обычный
push-pull GPIO. PC7 — на порту GPIOC, который иначе в этом проекте не включён: прошивка
сама включает его тактирование в `TFT_App_GPIO_Init()` (см. `Display/Src/tft_app.c`).

## Где эти пины на плате

```
 SV4 — левый край платы, 2×3
 (край платы слева)

   ┌───────┬───────┐
   │ 6 GND │ 5 +5V │  ← верх
   ├───────┼───────┤
   │ 4 CS  │ 3 SCK │
   │ PA15  │ PC10  │
   ├───────┼───────┤
   │ 2 MISO│ 1 MOSI│  ← низ, 1 = круглая
   │ PC11  │ PC12  │
   └───────┴───────┘

 SV1 — верхний край, 2×5, пин 1 справа (питания нет - все пины сигнальные)
   ┌──────┬──────┬──────┬──────┬──────┐
   │  9   │  7   │  5   │  3   │  1   │  ← верхний ряд (у края)
   │ PD5  │ PC6  │ PA4  │ PB8  │ PA0  │
   │ RST  │ BTN  │      │      │      │
   ├──────┼──────┼──────┼──────┼──────┤
   │  10  │  8   │  6   │  4   │  2   │
   │ PD6  │ PC7  │ PA5  │ PB9  │ PA3  │
   │  DC  │  BL  │      │      │      │
   └──────┴──────┴──────┴──────┴──────┘
```

BL/RST/DC + кнопка (BTN) занимают четыре соседних пина SV1 (7, 8, 9, 10, крайняя левая
пара колонок целиком) — компактный жгут из четырёх проводов рядом друг с другом; пины
1-6 свободны.

## Вариант Б: без управления подсветкой (8 проводов)

То же, но **BL** модуля — на **SV2.1 (+3V3)** напрямую, минуя SV1.8/PC7: подсветка
всегда включена, без программного управления. SDA-O не подключать. В прошивке
`TFT_BL_Pin` в этом случае не используется.

```
 1 GND   → SV4.6        5 RST → SV1.9  (PD5)
 2 VCC   → SV4.5 (+5V)  6 DC  → SV1.10 (PD6)
 3 SCL   → SV4.3 (PC10) 7 CS  → SV4.4  (PA15)
 4 SDA   → SV4.1 (PC12) 8 BL  → SV2.1  (+3V3)
```

## Проверка перед включением
1. Мультиметром: между SV4.5 и SV4.6 нет КЗ после подключения модуля.
2. Провода SCL/SDA — короткие (< 15 см), GND — рядом с ними; на 20 MHz длинные шлейфы дают сбои.
3. После прошивки в USART1: `[tft] full-screen fill = ~125 ms` (20 МГц). ID дисплея при старте не читается, SDA-O подключать не нужно.

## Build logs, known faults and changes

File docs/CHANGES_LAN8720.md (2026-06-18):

# Все исправления — STM32F407VGTx + LAN8720B Ethernet

## Суть проблемы

LAN8720B пад 14 (NINT/REFCLKO) выводил +3.3В DC вместо 50 МГц → DMABMR.SWR не очищался → HAL_ETH_Init FAILED.

---

## 1. Аппаратное исправление (обязательное)

### Проблема
Пин LED2/nINTSEL (пад 2 LAN8720) имеет **внутренний pull-up**. По умолчанию и с R37 (10 кОм к +3V3) — nINTSEL = HIGH = 1 → **NINT-режим**: пад 14 = сигнал прерывания (static HIGH ~3.3В), а не 50 МГц.

Для REFCLKO-режима нужен nINTSEL = LOW = 0 во время сброса.

R37 (10 кОм) **тянет пад 2 к +3V3** — это ошибка разводки платы.

### Исправление
Припаять резистор **1 кОм** от пада 2 LAN8720 (нет. -GREEN / нога R37 пин1 / J1 пин10) к GND:

```
+3V3 ── R37 (10кОм, есть) ──┬── пад 2 LAN8720 (nINTSEL)
GND  ── 1кОм (добавить)    ─┘
```

Напряжение: V(пад2) = 3.3В × 1к / (10к + 1к) = **0.30В** → nINTSEL = 0 → **REFCLKO-режим** → 50 МГц на паде 14 → PA1.

---

## 2. Программные исправления

### 2.1 `Core/Src/stm32f4xx_hal_msp.c` — ожидание стабилизации кристалла

**Проблема:** кристаллический генератор 25 МГц LAN8720 требует до ~300 мс для стабилизации после soft-reset. При 200 мс ожидании ETH init мог запускаться с нестабильным клоком → случайные перезагрузки.

**Было:**
```c
/* Allow crystal / PLL to lock and CLKOUT to stabilise */
HAL_Delay(200);
```

**Стало:**
```c
/* Allow crystal / PLL to lock and CLKOUT to stabilise.
   LAN8720 crystal startup can take up to ~300ms; 500ms is safe. */
HAL_Delay(500);
```

---

### 2.2 `Core/Src/ethernetif.c` — запуск DHCP при появлении линка

**Проблема:** `MX_LWIP_Init` вызывает `dhcp_start` только если линк уже есть при старте. Если линк появляется позже (через `ethernetif_poll_link`), DHCP никогда не запускался → IP не назначался.

**Добавлен include:**
```c
#include "lwip/dhcp.h"
```

**В функции `ethernetif_poll_link`, блок link-up:**
```c
// Было:
HAL_ETH_Start_IT(&EthHandle);
netif_set_up(netif);
netif_set_link_up(netif);

// Стало:
HAL_ETH_Start_IT(&EthHandle);
netif_set_up(netif);
netif_set_link_up(netif);
dhcp_start(netif);          // ← добавлено
```

**В блоке link-down:**
```c
// Было:
HAL_ETH_Stop_IT(&EthHandle);
netif_set_down(netif);
netif_set_link_down(netif);

// Стало:
HAL_ETH_Stop_IT(&EthHandle);
dhcp_stop(netif);           // ← добавлено
netif_set_down(netif);
netif_set_link_down(netif);
```

---

### 2.3 `Core/Inc/tcp_echo_client.h` — адрес TCP echo сервера

Сеть роутера оказалась `10.0.1.x`, а не `192.168.1.x`.

**Было:**
```c
#define TCP_ECHO_SERVER_IP0   192
#define TCP_ECHO_SERVER_IP1   168
#define TCP_ECHO_SERVER_IP2   1
#define TCP_ECHO_SERVER_IP3   100
```

**Стало:**
```c
#define TCP_ECHO_SERVER_IP0   10
#define TCP_ECHO_SERVER_IP1   0
#define TCP_ECHO_SERVER_IP2   1
#define TCP_ECHO_SERVER_IP3   18    // IP ПК = 10.0.1.18
```

---

## 3. Ранее сделанные исправления (предыдущие сессии)

### 3.1 `Core/Src/main.c` — MCO1 как резервный источник 25 МГц
```c
// В SystemClock_Config:
HAL_RCC_MCOConfig(RCC_MCO1, RCC_MCO1SOURCE_HSE, RCC_MCODIV_1);
// PA8 = 25 МГц (HSE/1) — резерв на случай отказа кристалла LAN8720
```

### 3.2 `Core/Src/stm32f4xx_hal_msp.c` — MDIO-сканирование и PHY soft-reset
В `HAL_ETH_MspInit` добавлено:
- Импульс сброса на PB10 (NRST LAN8720): LOW 10 мс → HIGH, ждать 100 мс
- MDIO-сканирование адресов 0–31 для поиска PHY
- Чтение ID2, BCR, BSR, MCSR (0x11), SMR (0x12) с выводом на UART
- BCR soft-reset (бит 15) с ожиданием очистки
- MDIO CR[4:2]=0x14 (Div102 для HCLK 160 МГц → MDC ≈ 1.57 МГц)

### 3.3 `Core/Src/ethernetif.c` — защита от краша без REF_CLK
```c
// В ethernetif_poll_link:
if (EthHandle.gState != HAL_ETH_STATE_READY)
{
    return;  // LAN8742.IO.ReadReg = NULL → краш без этой защиты
}
```

### 3.4 `Core/Src/stm32f4xx_it.c` — обработчик ETH прерывания
```c
void ETH_IRQHandler(void)
{
    HAL_ETH_IRQHandler(&EthHandle);
}
```

---

### 2.4 `Core/Src/tcp_echo_client.c` — UART RX → TCP forwarding (polling вместо ISR)

**Проблема:** `HAL_UART_Receive_IT` внутри `HAL_UART_RxCpltCallback` возвращала `HAL_BUSY`, потому что `HAL_UART_Transmit` (polling TX) удерживал `huart->Lock`. Прерывание переставало перевооружаться после первого байта → строка с UART никогда не накапливалась → UART-данные не уходили в TCP.

**Решение:** убраны ISR (`HAL_UART_RxCpltCallback`) и `HAL_UART_Receive_IT`. Вместо них — функция `poll_uart_rx()`, которая в главном цикле опрашивает флаг `UART_FLAG_RXNE` и читает регистр DR напрямую. Нет HAL-блокировок, нет конфликта с TX.

```c
static void poll_uart_rx(void)
{
  while (__HAL_UART_GET_FLAG(&huart1, UART_FLAG_RXNE) && !s_uart_line_ready)
  {
    uint8_t b = (uint8_t)(huart1.Instance->DR & 0xFFU);
    if (b == '\r' || b == '\n')
    {
      if (s_uart_line_pos > 0)
      {
        s_uart_line[s_uart_line_pos++] = '\n';
        s_uart_line[s_uart_line_pos]   = '\0';
        s_uart_line_ready = 1;
      }
    }
    else if (s_uart_line_pos < UART_LINE_BUF - 2U)
    {
      s_uart_line[s_uart_line_pos++] = (char)b;
    }
  }
}
```

`poll_uart_rx()` вызывается в начале `tcp_echo_client_poll`. Если строка (до `\r`/`\n`) накоплена, она немедленно уходит по TCP (`[tcp_echo] tx(uart): ...`). Если нет новых данных — цикл продолжается как прежде (пинги каждые 2 с).

---

## Итоговый результат

```
[eth] HAL_ETH_Init OK
[lwip] IP: 10.0.1.60
[tcp_echo] connected
[tcp_echo] tx: ping #0 from stm32f407
[tcp_echo] rx: Hello Module #49 ! I am module #59.
[alive] t=180000ms eth=LINK_UP
```

Стек полностью работает: RMII 50 МГц → HAL_ETH_Init → LAN8742 PHY@0 → lwIP NO_SYS=1 → DHCP → TCP.

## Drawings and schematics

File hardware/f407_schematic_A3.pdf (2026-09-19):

# 2.2k ⁺⁵V

A

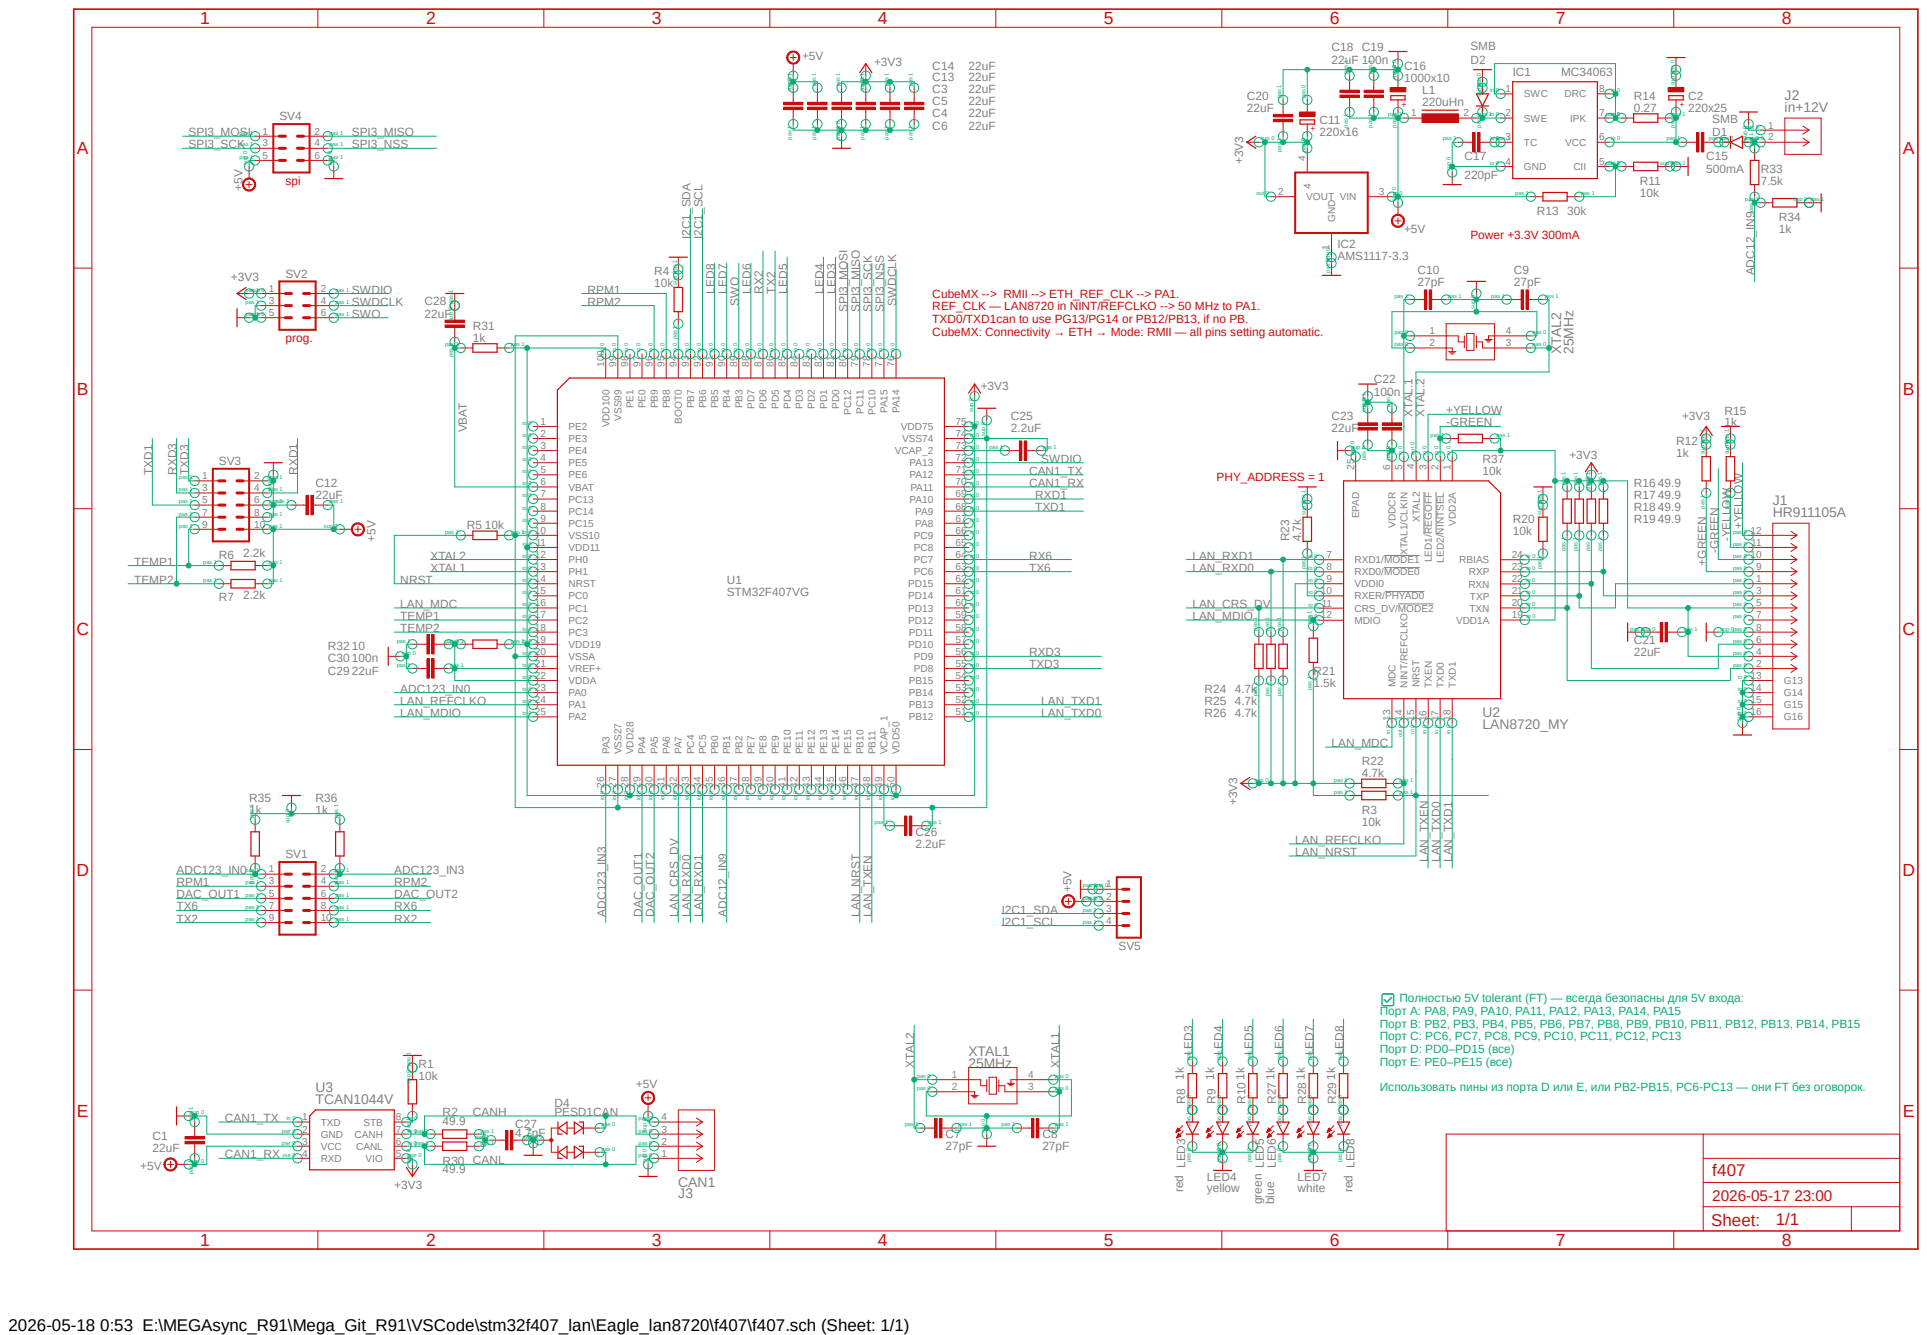
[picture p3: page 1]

CubeMX --> RMII --> ETH_REF_CLK --> PA1.
REF_CLK — LAN8720 in NINT/REFCLKO --> 50 MHz to PA1.
TXD0/TXD1can to use PG13/PG14 or PB12/PB13, if no PB.
CubeMX: Connectivity → ETH → Mode: RMII — all pins setting automatic.

io 0
io 0 | CAN1_TX

5 CRS_DV/MODE2 11 EPAD 25 MDIO 12 RXER/PHYAD0 10 RXN 22 RXP 23 TXN 20 TXP 21 NINT/REFCLKO 14 XTAL2
R22 R²³

Порт A: PA8, PA9, PA10, PA11, PA12, PA13, PA14, PA15
Порт B: PB2, PB3, PB4, PB5, PB6, PB7, PB8, PB9, PB10, PB11, PB12, PB13, PB14, PB15
Порт C: PC6, PC7, PC8, PC9, PC10, PC11, PC12, PC13
Порт D: PD0–PD15 (все)
Порт E: PE0–PE15 (все)
Использовать пины из порта D или E, или PB2-PB15, PC6-PC13 — они FT без оговорок.

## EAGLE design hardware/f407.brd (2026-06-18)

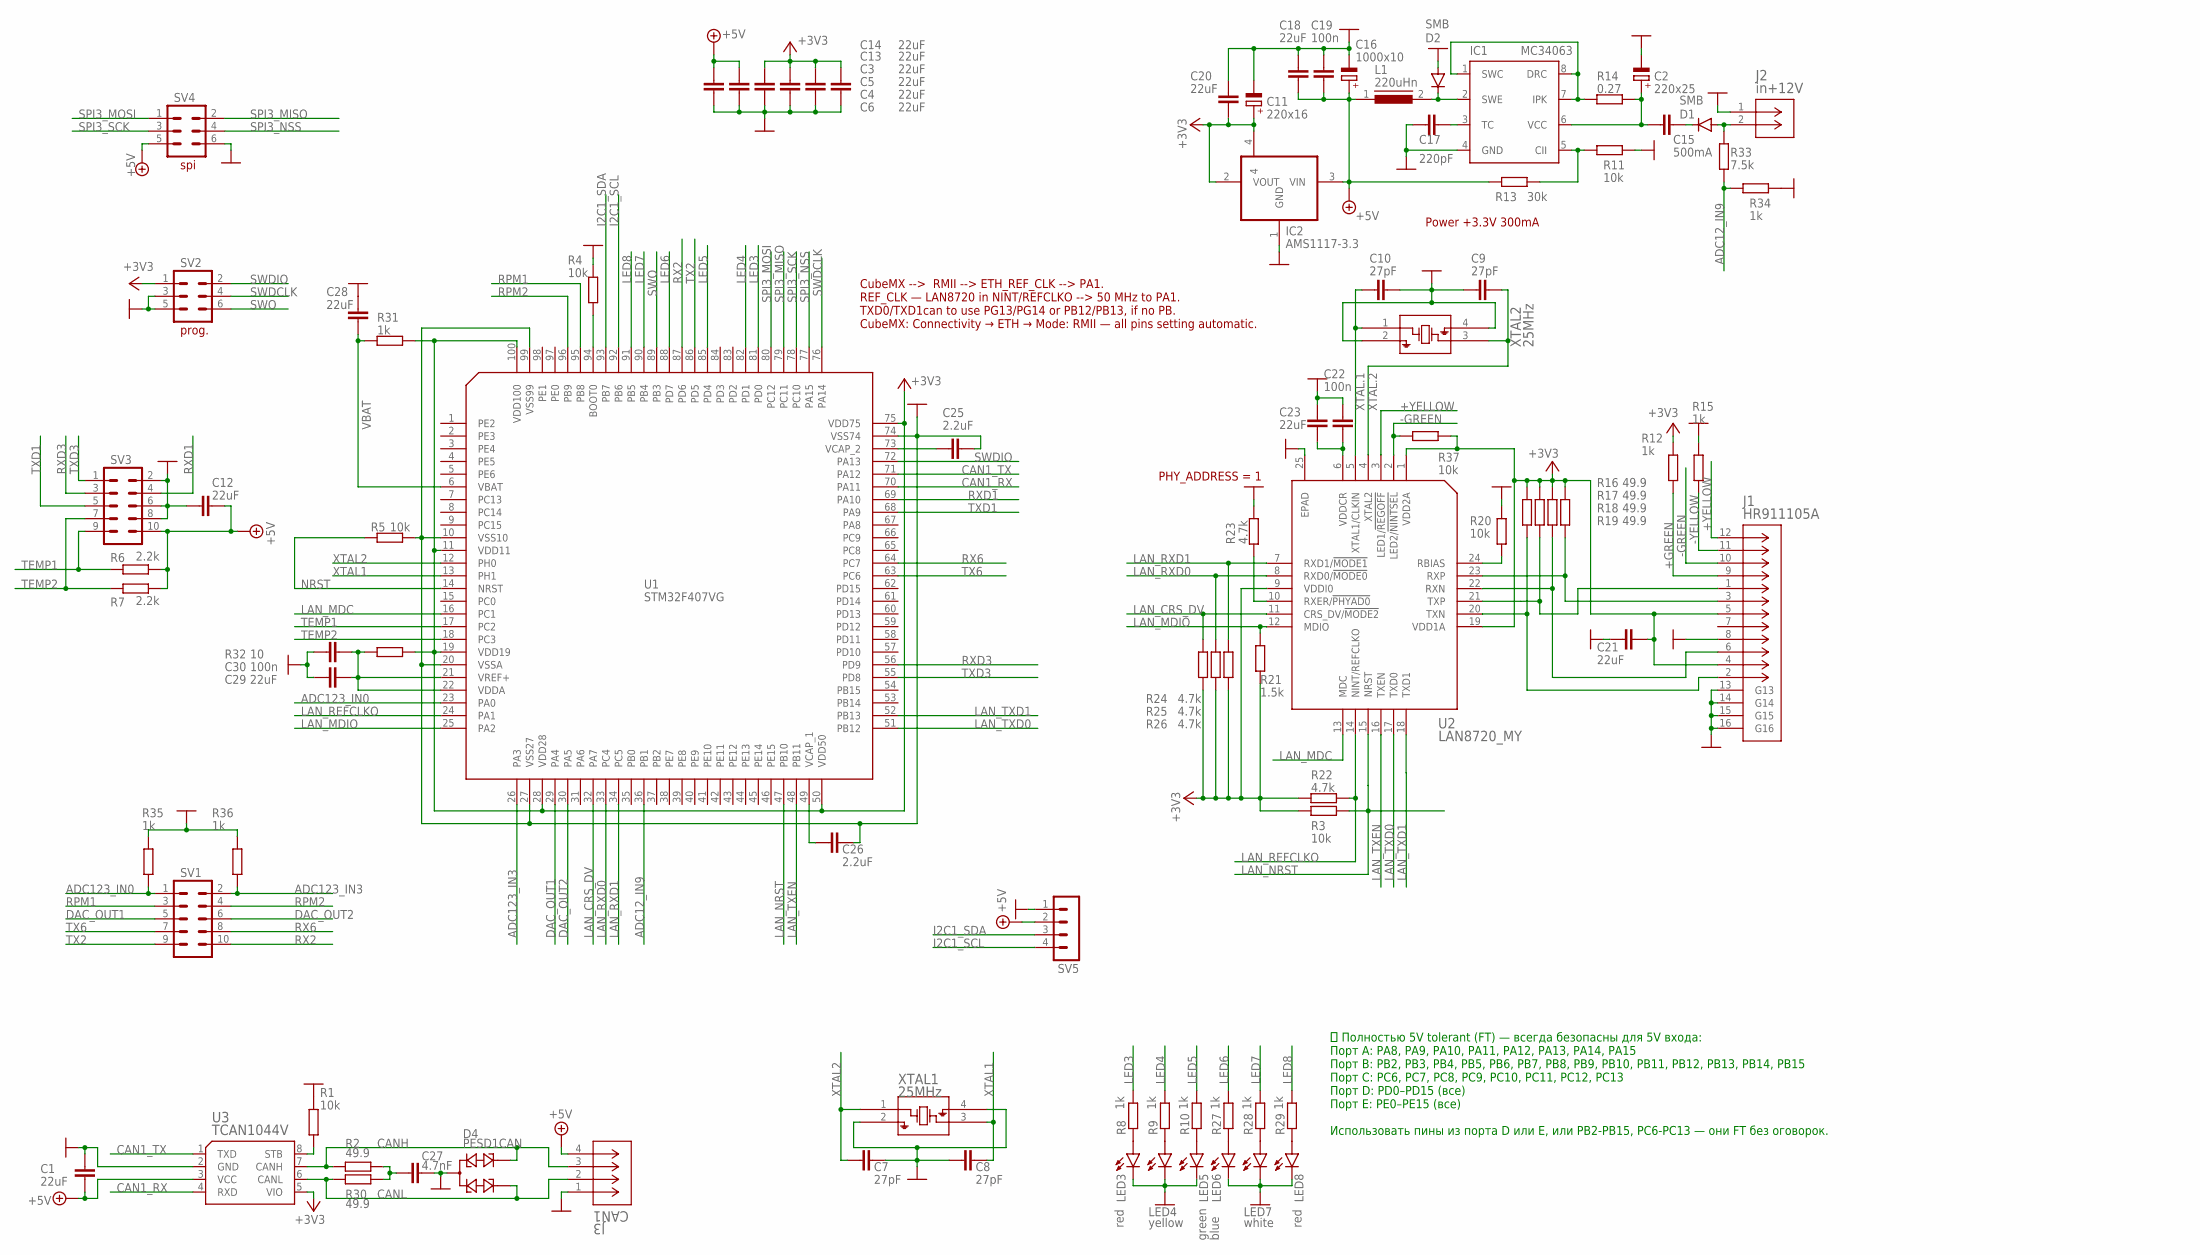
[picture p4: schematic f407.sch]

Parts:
C1, C3, C4, C5, C6, C12, C13, C14, C18, C20, C21, C23, C28, C29: 22uF; C0603
C2: 220x25; E3,5-8
C7, C8, C9, C10: 27pF; C0603
C11: 220x16; E2,5-7
C15: 500mA; C050-025X075
C16: 1000x10; E3,5-8
C17: 220pF; C0603
C19, C22, C30: 100n; C0603
C25, C26: 2.2uF; C0603
C27: 4.7nF; C0603
D1, D2: SMB
D4: PESD1CAN; SOT23
IC1: MC34063; 01_MY_LIB_SO08
IC2: AMS1117-3.3; GE70_DOCKING2_MYREG1117_SOT223
J1: HR911105A; CONN_1105A_HAN
J2: in+12V; CONN2_284513-2
J3: CAN1; CONN4_284513-4
L1: 220uHn; INDUCTORS_DR74
LED3, LED8: red; SML0603
LED4: yellow; SML0603
LED5: green; SML0603
LED6: blue; SML0603
LED7: white; SML0603
R1, R3, R4, R5, R11, R20, R37: 10k; R0402
R2, R16, R17, R18, R19, R30: 49.9; R0402
R6, R7: 2.2k; R0402
R8, R9, R10, R12, R15, R27, R28, R29, R31, R34, R35, R36: 1k; R0402
R13: 30k; R0402
R14: 0.27; R0805
R21: 1.5k; R0402
R22, R23, R24, R25, R26: 4.7k; R0402
R32: 10; R0402
R33: 7.5k; R0805
SV1, SV3: MA05-2
SV2, SV4: MA03-2
SV5: MA04-1
U1: STM32F407VG; MY_LQFP100
U2: LAN8720_MY; MY_QFN24
U3: TCAN1044V; MY_TCAN1044
XTAL1, XTAL2: 25MHz; ABM8_ABR

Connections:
+3V3: C3.2, C4.2, C5.2, C6.2, C11.+, C20.1, C21.1, IC2.2 (VOUT), IC2.4, J1.4, J1.5, R3.2, R12.1, R16.1, R17.1, R18.1, R19.1, R21.1, R22.2, R24.2, R25.2, R26.2, R31.2, R32.1, R37.2, SV2.1, U1.11 (VDD11), U1.19 (VDD19), U1.28 (VDD28), U1.50 (VDD50), U1.75 (VDD75), U1.100 (VDD100), U2.1 (VDD2A), U2.9 (VDDI0), U2.19 (VDD1A), U3.5 (VIO)
+5V: C1.1, C12.1, C13.2, C14.2, C16.+, C18.1, C19.1, IC2.3 (VIN), J3.4, L1.1, R6.2, R7.2, R13.1, SV3.10, SV4.5, SV5.2, U3.3 (VCC)
+GREEN: J1.9, R12.2
+YELLOW: J1.12, U2.3 (LED1/!REGOFF)
-GREEN: J1.10, R37.1, U2.2 (LED2/!NINTSEL)
-YELLOW: J1.11, R15.2
ADC12_IN9: R33.2, R34.1, U1.36 (PB1)
ADC123_IN0: R35.1, SV1.1, U1.23 (PA0)
ADC123_IN3: R36.1, SV1.2, U1.26 (PA3)
CAN1_RX: U1.70 (PA11), U3.4 (RXD)
CAN1_TX: U1.71 (PA12), U3.1 (TXD)
CANH: D4.2, J3.3, R2.1, U3.7 (CANH)
CANL: D4.1, J3.2, R30.1, U3.6 (CANL)
DAC_OUT1: SV1.5, U1.29 (PA4)
DAC_OUT2: SV1.6, U1.30 (PA5)
GND: C1.2, C2.-, C3.1, C4.1, C5.1, C6.1, C7.1, C8.2, C9.1, C10.2, C11.-, C12.2, C13.1, C14.1, C16.-, C17.2, C18.2, C19.2, C20.2, C21.2, C22.1, C23.1, C25.1, C26.1, C27.1, C28.1, C29.2, C30.2, D2.A, D4.3, IC1.4 (GND), IC2.1 (GND), J1.8, J1.13 (G13), J1.14 (G14), J1.15 (G15), J1.16 (G16), J2.1, J3.1, LED3.C, LED4.C, LED5.C, LED6.C, LED7.C, LED8.C, R1.1, R4.1, R5.2, R11.2, R15.1, R20.1, R23.2, R34.2, R35.2, R36.2, SV2.3, SV2.5, SV3.2, SV3.6, SV3.8, SV4.6, SV5.1, U1.10 (VSS10), U1.20 (VSSA), U1.27 (VSS27), U1.74 (VSS74), U1.99 (VSS99), U2.25 (EPAD), U3.2 (GND), XTAL1.2, XTAL1.4, XTAL2.2, XTAL2.4
I2C1_SCL: SV5.4, U1.92 (PB6)
I2C1_SDA: SV5.3, U1.93 (PB7)
LAN_CRS_DV: R24.1, U1.32 (PA7), U2.11 (CRS_DV/!MODE2)
LAN_MDC: U1.16 (PC1), U2.13 (MDC)
LAN_MDIO: R21.2, U1.25 (PA2), U2.12 (MDIO)
LAN_NRST: R3.1, U1.47 (PB10), U2.15 (NRST)
LAN_REFCLKO: R22.1, U1.24 (PA1), U2.14 (NINT/REFCLKO)
LAN_RXD0: R25.1, U1.33 (PC4), U2.8 (RXD0/!MODE0)
LAN_RXD1: R26.1, U1.34 (PC5), U2.7 (RXD1/!MODE1)
LAN_TXD0: U1.51 (PB12), U2.17 (TXD0)
LAN_TXD1: U1.52 (PB13), U2.18 (TXD1)
LAN_TXEN: U1.48 (PB11), U2.16 (TXEN)
LED3: R8.1, U1.81 (PD0)
LED4: R9.1, U1.82 (PD1)
LED5: R10.1, U1.85 (PD4)
LED6: R27.1, U1.88 (PD7)
LED7: R28.1, U1.90 (PB4)
LED8: R29.1, U1.91 (PB5)
unnamed: LED3.A, R8.2
unnamed: D1.A, J2.2, R33.1
unnamed: C15.2, D1.C
unnamed: LED4.A, R9.2
unnamed: C2.+, C15.1, IC1.6 (VCC), R14.2
unnamed: LED5.A, R10.2
unnamed: IC1.1 (SWC), IC1.7 (IPK), IC1.8 (DRC), R14.1
unnamed: C29.1, C30.1, R32.2, U1.21 (VREF+), U1.22 (VDDA)
unnamed: C17.1, IC1.3 (TC)
unnamed: D2.C, IC1.2 (SWE), L1.2
unnamed: IC1.5 (CII), R11.1, R13.2
unnamed: J1.3, R19.2, U2.23 (RXP)
unnamed: J1.6, R18.2, U2.22 (RXN)
unnamed: R20.2, U2.24 (RBIAS)
unnamed: J1.2, R16.2, U2.20 (TXN)
unnamed: C22.2, C23.2, U2.6 (VDDCR)
unnamed: R4.2, U1.94 (BOOT0)
unnamed: J1.1, R17.2, U2.21 (TXP)
unnamed: R23.1, U2.10 (RXER/!PHYAD0)
unnamed: C25.2, U1.73 (VCAP_2)
unnamed: C26.2, U1.49 (VCAP_1)
unnamed: C27.2, R2.2, R30.2
unnamed: LED6.A, R27.2
unnamed: LED7.A, R28.2
unnamed: LED8.A, R29.2
unnamed: R1.2, U3.8 (STB)
NRST: R5.1, U1.14 (NRST)
RPM1: SV1.3, U1.95 (PB8)
RPM2: SV1.4, U1.96 (PB9)
RX2: SV1.10, U1.87 (PD6)
RX6: SV1.8, U1.64 (PC7)
RXD1: SV3.4, U1.69 (PA10)
RXD3: SV3.3, U1.56 (PD9)
SPI3_MISO: SV4.2, U1.79 (PC11)
SPI3_MOSI: SV4.1, U1.80 (PC12)
SPI3_NSS: SV4.4, U1.77 (PA15)
SPI3_SCK: SV4.3, U1.78 (PC10)
SWDCLK: SV2.4, U1.76 (PA14)
SWDIO: SV2.2, U1.72 (PA13)
SWO: SV2.6, U1.89 (PB3)
TEMP1: R6.1, SV3.9, U1.17 (PC2)
TEMP2: R7.1, SV3.7, U1.18 (PC3)
TX2: SV1.9, U1.86 (PD5)
TX6: SV1.7, U1.63 (PC6)
TXD1: SV3.5, U1.68 (PA9)
TXD3: SV3.1, U1.55 (PD8)
VBAT: C28.2, R31.1, U1.6 (VBAT)
XTAL1: C8.1, U1.13 (PH1), XTAL1.3
XTAL2: C7.2, U1.12 (PH0), XTAL1.1
XTAL.1: C10.1, U2.5 (XTAL1/CLKIN), XTAL2.1
XTAL.2: C9.2, U2.4 (XTAL2), XTAL2.3

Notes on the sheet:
prog.
spi
Power +3.3V 300mA
PHY_ADDRESS = 1
CubeMX --> RMII --> ETH_REF_CLK --> PA1. REF_CLK — LAN8720 in NINT/REFCLKO --> 50 MHz to PA1. TXD0/TXD1can to use PG13/PG14 or PB12/PB13, if no PB. CubeMX: Connectivity → ETH → Mode: RMII — all pins setting automatic.
✅ Полностью 5V tolerant (FT) — всегда безопасны для 5V входа: Порт A: PA8, PA9, PA10, PA11, PA12, PA13, PA14, PA15 Порт B: PB2, PB3, PB4, PB5, PB6, PB7, PB8, PB9, PB10, PB11, PB12, PB13, PB14, PB15 Порт C: PC6, PC7, PC8, PC9, PC10, PC11, PC12, PC13 Порт D: PD0–PD15 (все) Порт E: PE0–PE15 (все) Испо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

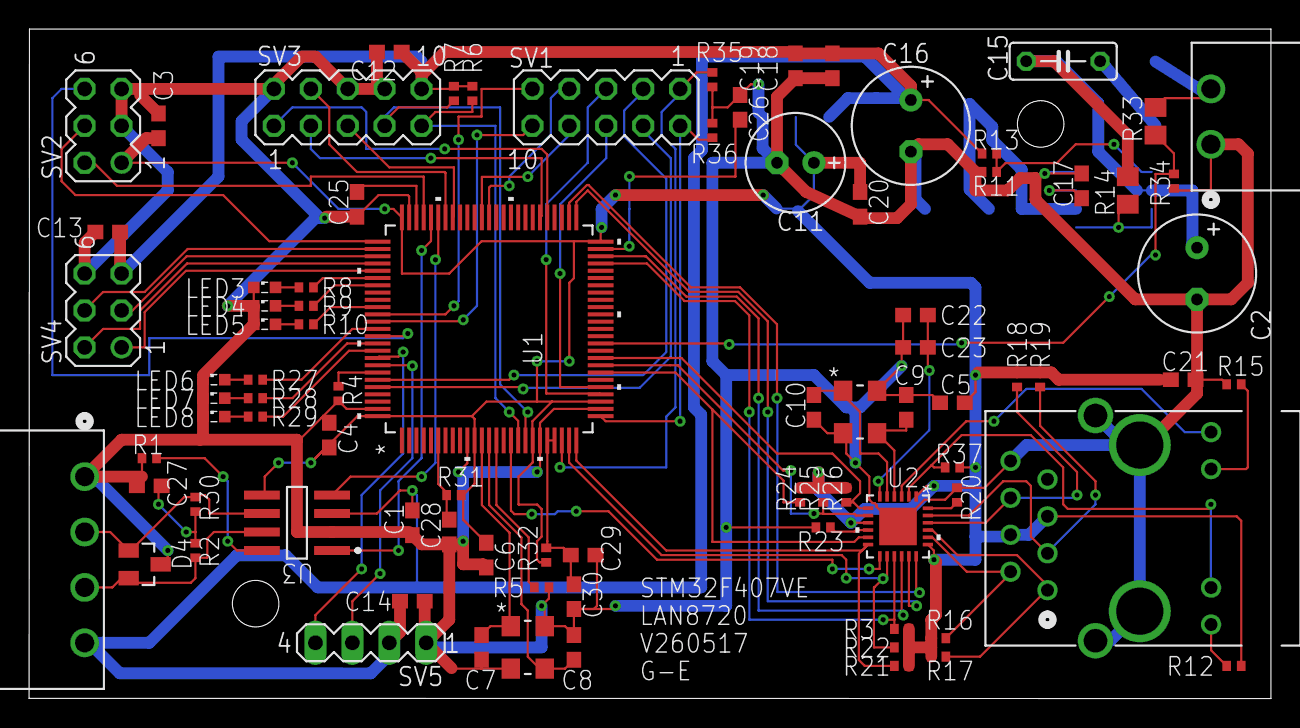
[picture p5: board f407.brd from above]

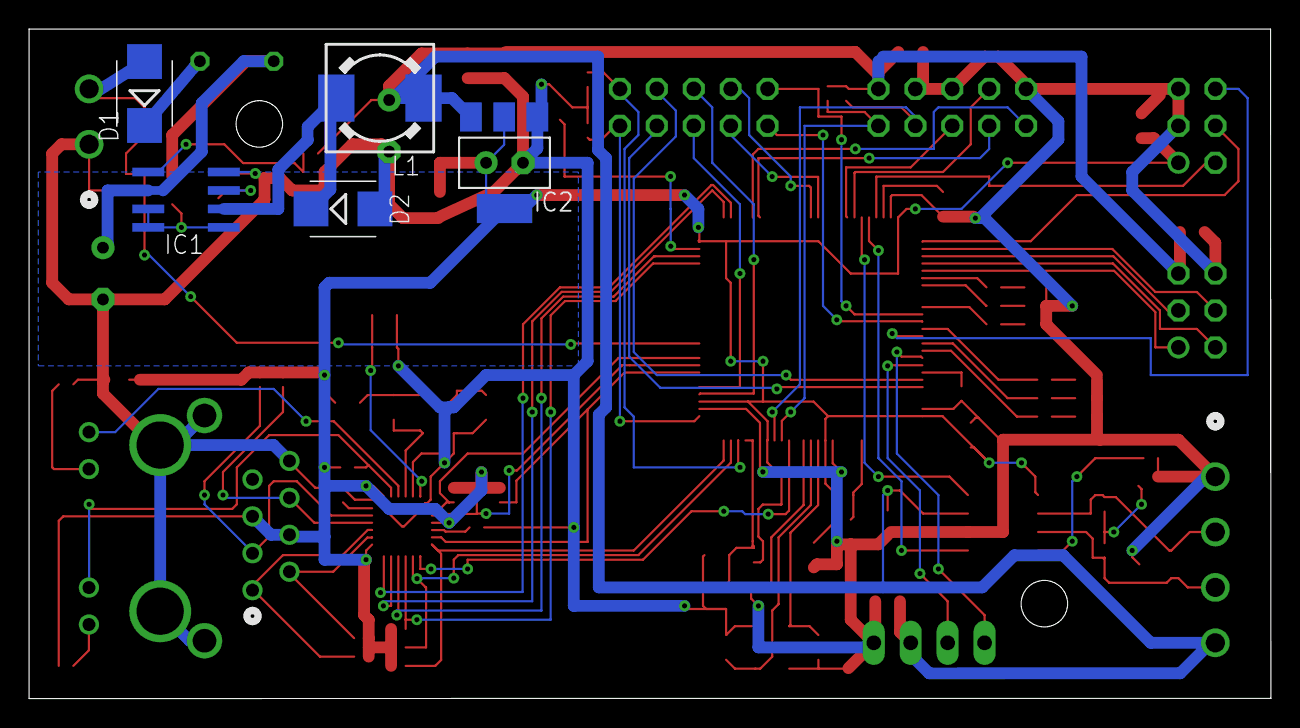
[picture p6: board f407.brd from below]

Board: 2 copper layers, 85.4 x 46.1 mm, 91 parts (5 on the bottom side), 85 nets.

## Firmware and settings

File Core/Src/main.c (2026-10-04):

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
/* Includes ------------------------------------------------------------------*/
#include "main.h"

/* USER CODE BEGIN Includes */
#include <string.h>
#include "lwip/init.h"
#include "lwip/netif.h"
#include "lwip/dhcp.h"
#include "lwip/timeouts.h"
#include "lwip/ip4_addr.h"
#include "netif/ethernet.h"
#include "ethernetif.h"
#include "tcp_echo_client.h"
#include "stm32f4xx_hal_eth.h"
#include "lwip/stats.h"
#include "tft_app.h"
#include "device_config.h"
#include "config_server.h"
#include "config_http.h"
#include "diag_cpu.h"
#include "clock.h"
#include "can_bus.h"
#include "diag_can.h"
#include "keypad.h"
#include "debug_uart.h"
/* USER CODE END Includes */

UART_HandleTypeDef huart1;
UART_HandleTypeDef huart3;

/* USER CODE BEGIN PV */
struct netif gnetif;
extern ETH_HandleTypeDef EthHandle; /* defined in ethernetif.c */
/* USER CODE END PV */

void SystemClock_Config(void);
static void MX_GPIO_Init(void);
static void MX_USART1_UART_Init(void);
static void MX_USART3_UART_Init(void);
static void Test_Blink_LEDs(void);
/* USER CODE BEGIN PFP */
static void MX_LWIP_Init(void);
static void netif_status_callback(struct netif *netif);
/* USER CODE END PFP */

/* USER CODE BEGIN 0 */

/* Keypad commands for the display. A group ended by '#':
     no characters     -> next page ("#")
     1..3 digits       -> that page, as in the "n/N" indicator ("3#", "12#");
                          a number with no such page is ignored
   Anything else is ordinary input: passwords are at least 4 digits or start
   with a letter, so they never look like a page command. Digits before '#',
   not after: the module sends a group only when '#' ends it. */
#define KBD_PAGE_CMD_MAX_DIGITS  3U

static void on_keypad(const KeypadPacket *p)
{
  uint16_t number = 0U;
  uint8_t  n;

  if ((p->type != KBD_PKT_GROUP) || (p->len == 0U) || (p->data[0] != KBD_END_ENTER))
  {
    return;
  }
  n = (uint8_t)(p->len - 1U);                 /* characters after the reason byte */
  if (n == 0U)
  {
    TFT_App_NextPage();
    return;
  }
  if (n > KBD_PAGE_CMD_MAX_DIGITS)
  {
    return;
  }
  for (uint8_t i = 1U; i <= n; i++)
  {
    if ((p->data[i] < (uint8_t)'0') || (p->data[i] > (uint8_t)'9'))
    {
      return;                                 /* a letter: not a page command */
    }
    number = (uint16_t)(number * 10U + (uint16_t)(p->data[i] - (uint8_t)'0'));
  }
  if (number <= 255U)
  {
    (void)TFT_App_ShowPage((uint8_t)number);  /* 0 or past the last page: ignored */
  }
}

/* USER CODE END 0 */

/**
  * @brief  The application entry point.
  * @retval int
  */
int main(void)
{

  /* MCU Configuration--------------------------------------------------------*/

  /* Reset of all peripherals, Initializes the Flash interface and the Systick. */
  HAL_Init();

  /* USER CODE BEGIN Init */
  /* Hold the LAN8720 in reset (PB10/nRST) as early as firmware can run, before
     R3's 10k pull-up can release it on its own while VDD/clocks are still
     ramping up. Previously nRST wasn't touched by firmware until deep inside
     HAL_ETH_MspInit() (called from MX_LWIP_Init() below), well after
     SystemClock_Config() and other peripheral inits - confirmed on real
     hardware (PROJECT_GUIDE.md) that manually grounding nRST starting from
     power-up (instead of relying on R3 + this late firmware assert) was
     needed to reliably get the LAN8720's REFCLKO block to start. Asserting
     nRST here, before anything else, removes most of that gap; the actual
     5 s hold + release still happens later in HAL_ETH_MspInit(). */
  {
    GPIO_InitTypeDef nrst_early = {0};
    __HAL_RCC_GPIOB_CLK_ENABLE();
    nrst_early.Pin = GPIO_PIN_10;
    nrst_early.Mode = GPIO_MODE_OUTPUT_PP;
    nrst_early.Pull = GPIO_NOPULL;
    nrst_early.Speed = GPIO_SPEED_FREQ_LOW;
    HAL_GPIO_Init(GPIOB, &nrst_early);
    HAL_GPIO_WritePin(GPIOB, GPIO_PIN_10, GPIO_PIN_RESET);
  }
  /* USER CODE END Init */

  /* Configure the system clock */
  SystemClock_Config();

  /* Initialize all configured peripherals */
  MX_GPIO_Init();
  TFT_App_GPIO_Init();
  MX_USART1_UART_Init();
  MX_USART3_UART_Init();
  /* USER CODE BEGIN 2 */
  /* USART1 debug output through a DMA ring from here on - Debug_Print()
     no longer blocks the main loop (see Core/Inc/debug_uart.h). */
  debug_uart_init();
  /* Print the firmware build date/time on every boot (cold-boot or
     NVIC_SystemReset() escalation alike) so a pasted log can always be
     matched to the exact binary that produced it - __DATE__/__TIME__ are
     baked in by the compiler at build time, so this can't go stale the way
     a manually-maintained version number could. */
  {
    char boot_msg[64];
    snprintf(boot_msg, sizeof(boot_msg), "\r\n[boot] firmware built %s %s\r\n", __DATE__, __TIME__);
    Debug_Print(boot_msg);
  }
  /* Load persisted settings (server address, device name, static-IP-vs-DHCP
     choice - see Config/Inc/device_config.h) before anything that needs
     them: the SETUP page's SERVER:/NAME: rows below, and MX_LWIP_Init()'s
     static/DHCP branch further down. Falls back to compiled-in defaults on
     first boot (blank Flash) or a version mismatch. */
  device_config_load();

  /* TFT bring-up runs before lwIP so its blocking HAL_Delay()s can't stall
     Ethernet RX/DHCP; the panel just shows a static test pattern afterwards. */
  TFT_App_SPI3_Init();
  {
    const DeviceConfig *cfg = device_config_get();
    char server_str[24];
    snprintf(server_str, sizeof(server_str), "%u.%u.%u.%u:%u",
             cfg->server_ip[0], cfg->server_ip[1], cfg->server_ip[2], cfg->server_ip[3], cfg->server_port);
    TFT_App_SmokeTest(server_str, cfg->name);
  }
  MX_LWIP_Init();
  tcp_echo_client_init();
  config_server_init();
  config_http_init();
  clock_init();     /* Clock/: NTP time for the CLOCK page, see clock_config.h */
  diag_can_init();      /* Diag/: CAN loopback self-test if DIAG_CAN_LOOPBACK */
  (void)can_bus_init(); /* CAN/: CAN1 on J3, receive + log, see can_config.h */
  keypad_init();        /* Keypad/: I2C1 slave on SV5, 4x4 keypad module, see keypad_config.h */
  keypad_set_handler(on_keypad);  /* '#' / 'N#' switch display pages */
  diag_cpu_init();  /* Diag/: main-loop load stats, see diag_config.h */
  /* USER CODE END 2 */

  /* Infinite loop */
  /* USER CODE BEGIN WHILE */
  while (1)
  {
    diag_cpu_loop();
    Test_Blink_LEDs();
    diag_cpu_begin(DIAG_SECT_HTTP);
    config_http_poll();
    diag_cpu_end(DIAG_SECT_HTTP);

    /* A config save (from the web page or the port-7000 text protocol) bumps
       device_config_revision(). React here, so neither config module needs
       to know about the display or the TCP client: refresh SERVER:/NAME: on
       the SETUP page, and if the server address itself changed, drop the
       current connection and reconnect to the new one right away. IP-mode
       changes are not handled here - they need a reboot (MX_LWIP_Init()). */
    {
      static uint32_t seen_rev = 0U;
      static uint8_t  seen_ip[4];
      static uint16_t seen_port;
      static uint8_t  seen_init = 0U;
      const DeviceConfig *cfg = device_config_get();

      if (seen_init == 0U)
      {
        memcpy(seen_ip, cfg->server_ip, sizeof(seen_ip));
        seen_port = cfg->server_port;
        seen_init = 1U;
      }
      if (device_config_revision() != seen_rev)
      {
        char server_str[24];

        seen_rev = device_config_revision();
        snprintf(server_str, sizeof(server_str), "%u.%u.%u.%u:%u",
                 cfg->server_ip[0], cfg->server_ip[1], cfg->server_ip[2], cfg->server_ip[3], cfg->server_port);
        TFT_App_UpdateInfo(server_str, cfg->name);

        if ((memcmp(seen_ip, cfg->server_ip, sizeof(seen_ip)) != 0) || (seen_port != cfg->server_port))
        {
          memcpy(seen_ip, cfg->server_ip, sizeof(seen_ip));
          seen_port = cfg->server_port;
          tcp_echo_client_restart();
        }
      }
    }

    /* Drain all pending ETH RX frames. Called unconditionally: the internal
       do-while exits immediately when nothing is pending, so the cost is one
       cheap HAL_ETH_ReadData call that returns NULL.  Avoids a race where
       EthRxPending was already cleared when the last ISR fired but a frame
       is still waiting in the DMA descriptor ring. */
    diag_cpu_begin(DIAG_SECT_ETH);
    ethernetif_input(&gnetif);

    /* Poll PHY link state and lwIP's own timers (ARP, DHCP, TCP, ...) -
       NO_SYS=1 means nothing else is going to do this for us. */
    ethernetif_poll_link(&gnetif);
    diag_cpu_end(DIAG_SECT_ETH);
    diag_cpu_begin(DIAG_SECT_LWIP);
    sys_check_timeouts();
    diag_cpu_end(DIAG_SECT_LWIP);

    can_bus_poll();  /* CAN1 RX queue -> log/handler, bus state */
    diag_can_poll();  /* loopback self-test step (empty stub when off) */
    keypad_poll();    /* keypad packets from the I2C1 interrupt -> log/handler */

    /* DHCP fallback: in DHCP mode, if the link is up but no DHCP server has
       answered within DHCP_FALLBACK_MS, take the configured static IP ("IP
       по умолчанию", see device_config_fallback_addr()) so a PC can still
       reach the web page - e.g. module cabled straight to a PC, no router.
       While on the fallback address DHCP keeps trying: dhcp_start() is
       re-armed every DHCP_RETRY_MS (the client's own backoff alone was seen
       to never bind again), and a lease simply replaces the fallback
       address (dhcp_bind() -> netif_set_addr()).
       Reboot escalation: on this board DHCP sometimes can't succeed after a
       cold power-on until the MCU is rebooted (see the "no IP" watchdog
       below and docs/PROJECT_GUIDE.md) - seen again here: stuck on the
       default IP for 10+ minutes behind a working router, one soft reset
       and the lease came at once. So if there is still no lease after
       DHCP_FALLBACK_REBOOT_MS on the default IP and nobody is using that
       address (no web page / port 7000 request since the fallback, or none
       for CONFIG_IDLE_MS), reboot. With a PC cabled straight to the module
       the page is reachable in each window and opening it stops the reboots. */
    #define DHCP_FALLBACK_MS        10000U
    #define DHCP_RETRY_MS           30000U
    #define DHCP_FALLBACK_REBOOT_MS 60000U
    #define CONFIG_IDLE_MS          300000U
    {
      static uint8_t  dhcp_waiting = 0U;
      static uint32_t dhcp_wait_since = 0U;
      static uint32_t dhcp_last_retry = 0U;
      static uint8_t  on_fallback = 0U;
      static uint32_t fallback_since = 0U;

      if (device_config_get()->use_static_ip != 0U)
      {
        dhcp_waiting = 0U;
        on_fallback = 0U;
      }
      else if (!netif_is_link_up(&gnetif))
      {
        /* on_fallback deliberately kept: an ETH reset drops the link for a
           moment, and restarting the reboot timer on every one of those
           kept the module on the default IP for 5 minutes. */
        dhcp_waiting = 0U;
      }
      else if (ip4_addr_isany_val(*netif_ip4_addr(&gnetif)))
      {
        if (dhcp_waiting == 0U)
        {
          dhcp_waiting = 1U;
          dhcp_wait_since = HAL_GetTick();
        }
        else if ((HAL_GetTick() - dhcp_wait_since) >= DHCP_FALLBACK_MS)
        {
          uint8_t a[4], m[4], g[4];
          ip4_addr_t ipaddr, netmask, gw;

          device_config_fallback_addr(a, m, g);
          IP4_ADDR(&ipaddr,  a[0], a[1], a[2], a[3]);
          IP4_ADDR(&netmask, m[0], m[1], m[2], m[3]);
          IP4_ADDR(&gw,      g[0], g[1], g[2], g[3]);
          netif_set_addr(&gnetif, &ipaddr, &netmask, &gw);
          Debug_Print("[lwip] no DHCP answer, using default IP\r\n");
          dhcp_waiting = 0U;
          dhcp_last_retry = HAL_GetTick();
          on_fallback = 1U;
          fallback_since = HAL_GetTick();
        }
      }
      else
      {
        dhcp_waiting = 0U;
        if (dhcp_supplied_address(&gnetif))
        {
          on_fallback = 0U;
        }
        else if (netif_is_up(&gnetif) && ((HAL_GetTick() - dhcp_last_retry) >= DHCP_RETRY_MS))
        {
          dhcp_last_retry = HAL_GetTick();
          dhcp_start(&gnetif);
          Debug_Print("[lwip] on default IP, retrying DHCP\r\n");
        }

        if ((on_fallback != 0U) && ((HAL_GetTick() - fallback_since) >= DHCP_FALLBACK_REBOOT_MS))
        {
          const uint32_t acc = device_config_last_access();
          const uint8_t  in_use = (uint8_t)((acc != 0U) && ((int32_t)(acc - fallback_since) >= 0) &&
                                  ((HAL_GetTick() - acc) < CONFIG_IDLE_MS));
          if (in_use == 0U)
          {
            Debug_Print("[lwip] still no DHCP lease on default IP, rebooting MCU\r\n");
            HAL_Delay(50); /* let the UART finish transmitting before reset */
            NVIC_SystemReset();
          }
        }
      }
    }

    /* Only talk to the server once we actually have an IP (DHCP-assigned). */
    {
      uint8_t has_ip = (netif_is_up(&gnetif) && !ip4_addr_isany_val(*netif_ip4_addr(&gnetif))) ? 1U : 0U;
      /* Where the IP came from, for the DHCP: row: 'S' static mode,
         'D' DHCP lease, 'F' default IP after DHCP timeout, '-' none yet. */
      char ip_src = (device_config_get()->use_static_ip != 0U) ? 'S' :
                    dhcp_supplied_address(&gnetif) ? 'D' : has_ip ? 'F' : '-';

      /* Feed the TFT status screen the same state this block already needs
         anyway - see tft_app.h for the ip_addr/link_up/tcp_state contract.
         TFT_App_AlivePoll() rate-limits itself to 1 Hz internally, so
         calling it every loop iteration here is cheap. */
      diag_cpu_begin(DIAG_SECT_TFT);
      TFT_App_AlivePoll(has_ip ? ip4_addr_get_u32(netif_ip4_addr(&gnetif)) : 0U,
                        netif_is_link_up(&gnetif) ? 1U : 0U,
                        ip_src,
                        tcp_echo_client_state_char());
      diag_cpu_end(DIAG_SECT_TFT);

      /* NTP time (Clock/): paces itself - one request an hour once set */
      clock_poll(has_ip);

      /* On the default IP there is no route to the TCP server anyway, and the
         client's failed connects would only trigger ETH resets. */
      if (has_ip && (ip_src != 'F'))
      {
        diag_cpu_begin(DIAG_SECT_TCP);
        tcp_echo_client_poll();
        diag_cpu_end(DIAG_SECT_TCP);

        /* Show whatever the server just sent back on the LAST MSG: row for
           2 s (TFT_App_ShowReceived() handles the timing/blanking itself,
           non-blocking) - only when tcp_echo_client_poll() above actually
           drained something new, so an unrelated call here can't restart
           the 2 s timer on stale text. */
        {
          char rx_snapshot[220];  /* match tcp_echo_client.c's LAST_RX_SNAPSHOT_SIZE */
          if (tcp_echo_client_take_last_rx(rx_snapshot, sizeof(rx_snapshot)) > 0U)
          {
            diag_cpu_begin(DIAG_SECT_TFT);
            TFT_App_ShowReceived(rx_snapshot);
            diag_cpu_end(DIAG_SECT_TFT);
          }
        }
      }

      /* Watchdog: DHCP lease loss/renewal clears the netif's IP
         (dhcp_release_and_stop() -> netif_set_addr(ANY)) until a fresh
         lease completes - confirmed in lwIP source (dhcp.c). While the IP
         is missing, tcp_echo_client_poll() above is skipped entirely, so
         the existing "3 failed TCP connects -> ethernetif_reset()" recovery
         path never gets a chance to run either - there is otherwise no
         self-healing at all for a stuck DHCP renewal. Observed on real
         hardware: IP missing for an entire hour with no recovery (see
         PROJECT_GUIDE.md). DHCP on a healthy LAN completes in well under a
         second, so anything stuck this long needs the same hardware-level
         kick used for wedged TCP. Lowered from 90s: that long a wait only
         delayed the inevitable - logs show ethernetif_reset() alone often
         doesn't get DHCP working again even though link/hardware recover
         fine, while a full MCU reboot reliably does within ~5s (see
         PROJECT_GUIDE.md) - so waiting it out in place wastes minutes for
         nothing. Shorter timeout = fewer wasted seconds before falling
         through to the escalation reboot below. */
      #define DHCP_STUCK_TIMEOUT_MS 15000U
      /* When ETH hardware itself is known broken (g_eth_hw_failed, set by
         low_level_init() on a HAL_ETH_Init() failure and cleared on success
         - see ethernetif.c/.h), there is nothing to "wait out":
         eth_check_refclk_pa1() already gave a definitive answer in seconds.
         Retry almost immediately instead of waiting the full
         DHCP_STUCK_TIMEOUT_MS (that long timeout exists for a genuinely
         different case - ETH hardware fine, DHCP server just
         slow/unresponsive).
         NOTE: g_eth_debug_marker==100 was used here originally, but that is
         WRONG - MX_LWIP_Init() unconditionally overwrites
         g_eth_debug_marker right after the very first low_level_init()
         call (via netif_add()), clobbering the 100 a cold-boot failure had
         just set, so that condition never actually fired on real hardware
         (confirmed: heartbeat kept showing LINK_DOWN instead of INIT_FAIL,
         and the fast retry never kicked in - the 90s DHCP_STUCK_TIMEOUT_MS
         ran every time instead). g_eth_hw_failed is written nowhere else,
         so it can't be clobbered the same way. See PROJECT_GUIDE.md. */
      #define ETH_INIT_FAIL_RETRY_MS 2000U
      /* Escalation: ethernetif_reset() alone (nRST pulse + MDIO, board
         power left on) sometimes cannot get DHCP working again even once
         the hardware/link itself recover fine - confirmed on real hardware
         that only a full MCU reboot (through main(), where nRST is now
         asserted as the very first thing - see above) reliably recovers it
         in that case. If the watchdog has had to force a reset this many
         times in a row with no successful IP in between, stop retrying in
         place and reboot the whole MCU instead, so the next boot gets the
         benefit of that early nRST assert - same effect as the manual
         "ground nRST during a restart" fix, with no human needed. Lowered
         from 3 to 2: logs show soft resets don't reliably fix this specific
         failure mode anyway, so a 3rd in-place retry is just wasted time
         that a reboot already proven to work could have used instead. See
         PROJECT_GUIDE.md. */
      #define ETH_RESET_ESCALATE_AFTER 2U
      {
        static uint32_t ip_missing_since = 0;
        static uint32_t reset_escalation_count = 0;

        if (has_ip)
        {
          ip_missing_since = 0;
          reset_escalation_count = 0;
        }
        else if (!g_eth_hw_failed && !netif_is_link_up(&gnetif))
        {
          /* Cable out: no IP is expected, not a stuck DHCP - resetting ETH
             or rebooting can't help. Restart the clock once the link is
             back. (Only reachable since ethernetif_poll_link() really sees
             link-down; before that fix the netif never left LINK_UP.) */
          ip_missing_since = 0;
        }
        else if (ip_missing_since == 0)
        {
          ip_missing_since = HAL_GetTick();
        }
        else if ((HAL_GetTick() - ip_missing_since) >=
                 (g_eth_hw_failed ? ETH_INIT_FAIL_RETRY_MS : DHCP_STUCK_TIMEOUT_MS))
        {
          reset_escalation_count++;
          if (reset_escalation_count >= ETH_RESET_ESCALATE_AFTER)
          {
            Debug_Print("[lwip] ETH reset escalation exhausted, rebooting MCU\r\n");
            HAL_Delay(50); /* let the UART finish transmitting before reset */
            NVIC_SystemReset();
          }
          Debug_Print("[lwip] no IP for too long, forcing ETH reset\r\n");
          ethernetif_reset(&gnetif);
          ip_missing_since = 0;
        }
      }
    }

    /* Periodic heartbeat so UART output is visible even if the terminal was
       connected after boot.  Prints every 5 s regardless of ETH state. */
    {
      static uint32_t last_hb = 0;
      if ((HAL_GetTick() - last_hb) >= 5000U)
      {
        char hb[160];
        last_hb = HAL_GetTick();
        snprintf(hb, sizeof(hb), "[alive] t=%ums eth=%s phy=%d txbuf=%lu rxalloc=%u tcp=%c heap=%u/%u sndq=%u\r\n",
                 (unsigned)HAL_GetTick(),
                 g_eth_hw_failed            ? "INIT_FAIL" :
                 netif_is_link_up(&gnetif)    ? "LINK_UP"   : "LINK_DOWN",
                 (int)g_eth_last_phy_link_state,
                 (unsigned long)EthHandle.TxDescList.BuffersInUse,
                 (unsigned)g_eth_rx_alloc_status,
                 tcp_echo_client_state_char(),
                 (unsigned)lwip_stats.mem.used, (unsigned)lwip_stats.mem.avail,
                 (unsigned)tcp_echo_client_sndqueuelen());
        Debug_Print(hb);
      }
    }
    /* USER CODE END WHILE */

    /* USER CODE BEGIN 3 */
  }
  /* USER CODE END 3 */
}

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
/* USER CODE BEGIN 4 */
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

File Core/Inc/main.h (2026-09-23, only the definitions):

#define LED3_Pin GPIO_PIN_0
#define LED3_GPIO_Port GPIOD
#define LED4_Pin GPIO_PIN_1
#define LED4_GPIO_Port GPIOD
#define LED5_Pin GPIO_PIN_4
#define LED5_GPIO_Port GPIOD
#define LED6_Pin GPIO_PIN_7
#define LED6_GPIO_Port GPIOD
#define LED7_Pin GPIO_PIN_4
#define LED7_GPIO_Port GPIOB
#define LED8_Pin GPIO_PIN_5
#define LED8_GPIO_Port GPIOB
#define TFT_CS_Pin GPIO_PIN_15
#define TFT_CS_GPIO_Port GPIOA
#define TFT_DC_Pin GPIO_PIN_6
#define TFT_DC_GPIO_Port GPIOD
#define TFT_RST_Pin GPIO_PIN_5
#define TFT_RST_GPIO_Port GPIOD
#define TFT_BL_Pin GPIO_PIN_7
#define TFT_BL_GPIO_Port GPIOC
#define TFT_PAGEBTN_Pin GPIO_PIN_6
#define TFT_PAGEBTN_GPIO_Port GPIOC

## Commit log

2026-06-18 2026.06.18 good test
    [f407.brd, f407.sch]
2026-06-18 2026.06.18 fix dhcp long time ago
    [main.c]
2026-06-19 Shorten nRST/retry/DHCP timeouts now that strap mis-latch is the confirmed root cause
    The long nRST hold (5s), 3x init retry, and 5s MDIO power-down hold were
    defensive measures for a disproven "unfixable PHY lockup" theory. With the
    real cause fixed in hardware (nINTSEL strap pulldown 6.8k->1k, confirmed
    against Microchip's own EVB8720 reference schematic), trim them back so
    recovery cycles take seconds instead of minutes. Also shortens the
    DHCP-stuck watchdog and reset-escalation threshold, since soft
    ethernetif_reset() doesn't reliably recover a stuck DHCP lease while a
    full NVIC_SystemReset() does within ~5s.
    [ethernetif.c, main.c]
2026-09-19 Reorganize as stm32f407vg_lan_tft and add ST7796S TFT smoke test
    Cleanup of the fork from stm32f407vg_lan_v1:
    - untrack clangd index (.cache/), build-output.txt and .vscode/*.log
    - drop unused IAR EWARM/ artifacts and three overlapping build notes
    (folded into README.md)
    - move docs to docs/ (+ datasheets), schematic/board/photos to hardware/
    - rename project/ELF/.ioc from _v1 to _tft, fix launch.json (no SVD file)
    - add VS Code workspace file, hardware/BOARD.md board summary
    TFT: minimal ST7796S 4-wire SPI driver (SPI3 on SV4, DC/RST/BL on
    PB6/PB7/PB8), HAL SPI module from CubeF4 V1.28.3, boot-time smoke test
    (RDID4 readback to USART1, R/G/B fill, test pattern).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
    [f407.brd, f407.sch]
2026-09-19 TFT bring-up test: ID verdict, frame timing, rotation sweep, live counters
    - ReadID result is classified (confirmed / shifted / SDA-O not wired /
    unexpected) instead of just dumped
    - full-screen fill is timed and reported in ms and kB/s
    - test pattern shown in all 4 MADCTL rotations
    - 7-segment digits drawn from rectangles (no font yet): uptime seconds and
    measured frame time on screen, plus a 1 Hz red/green square, so a stalled
    link is visible without a UART
    - hardware/TFT_WIRING.md: pin-to-pin wiring for SV4+SV5(+SV1)
    [main.c, st7796s.c]
2026-09-23 Move display code/docs into a standalone Display/ module
    Isolates everything display-related from the Ethernet/lwIP side so it
    can be modernised (fonts, network-status screen, ...) by touching only
    this folder:
    - Display/Inc, Display/Src: st7796s.c/.h (low-level controller driver,
    unchanged) + new tft_app.c/.h (application layer, extracted from
    main.c: SPI3 init, TFT control-GPIO init, boot smoke test, live
    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
2026-09-23 VS Code: add Build+Flash task and wire F5 to build before debug
    - tasks.json: new "Build + Flash" compound task (CMake: Build, then
    Flash STM32F407VG in sequence) for a single build+program step.
    - launch.json: preLaunchTask "CMake: Build" on the Cortex Debug config,
    so F5 / the Run and Debug play button always debugs the freshly
    built ELF instead of a possibly stale one.
    - settings.json: clangd --query-driver for both installed
    arm-none-eabi-gcc toolchains, so clangd resolves the ARM target
    instead of falling back to the host (MSVC) one.
    Note: the keyboard shortcut itself (Ctrl+Alt+F -> "Build + Flash")
    lives in the user's global keybindings.json, not here - VS Code has no
    suppor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
2026-09-23 Fix stale tracked copies of st7796s.h/.c left at their old Core/ path
    The Display/ move (5271c3e) never actually staged their removal from
    Core/Inc and Core/Src: that commit's git add listed hardware/ and
    Display/ as whole directories (which does pick up deletions) but only
    two specific files under Core/ (main.h, main.c), so the deletion of
    Core/Inc/st7796s.h and Core/Src/st7796s.c fell through and stayed
    committed - even though both were already physically moved on disk
    via git mv beforehand. Harmless in practice (nothing includes them
    from that path), but the tree was lying about what files exist.
    [st7796s.c]
2026-09-23 TFT: move DC/RST from SV5 to SV1, drop SV5 from the wiring entirely
    DC/RST/BL are plain push-pull GPIOs with no fixed peripheral function
    requirement (unlike SPI3's SCK/MOSI/MISO), so they can sit on any free
    pin. Moved them next to BL (PB8, already on SV1.3):
    DC: PB6 (SV5.4) -> PA4 (SV1.5)
    RST: PB7 (SV5.3) -> PB9 (SV1.4)
    Result: the whole panel now wires up on 2 headers (SV4 + SV1) instead
    of 3, with BL/RST/DC landing on three physically adjacent SV1 pins
    (3/4/5) - one compact 3-wire cluster instead of two separate runs to
    SV4 and SV5. Wire count is unchanged (still 9), just consolidated.
    PA4/PB9 are silkscreened DAC_OUT1/RPM2 on this board (hardware/BOARD.md)
    but neither DAC nor TI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
    [main.h, tft_app.c]
2026-09-23 Build: show FLASH/RAM usage as a progress bar
    Replace the plain arm-none-eabi-size dump with a small CMake script
    (cmake/print_size.cmake) that parses its output and renders each
    region as a bar + percentage + KB, e.g.:
    FLASH [#####.........................] 16.5% 169.2 / 1024.0 KB
    RAM [#############.................] 42.3% 54.1 / 128.0 KB
    Plain ASCII (#/.) rather than block-drawing characters, since those
    can render as mangled bytes on a default-codepage Windows console.
    FLASH_SIZE_BYTES/RAM_SIZE_BYTES are set once in CMakeLists.txt and
    must be kept in sync with linker_script.ld's MEMORY block (noted in
    both places).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
2026-09-23 TFT: move DC/RST/BL from SV1 pins 3/4/5 to pins 8/9/10
    Same rationale as the previous SV5->SV1 move: DC/RST/BL are plain
    GPIOs, free to sit anywhere. Shifted the whole 3-pin cluster to the
    other end of SV1's free pins:
    BL: PB8 (SV1.3) -> PC7 (SV1.8)
    RST: PB9 (SV1.4) -> PD5 (SV1.9)
    DC: PA4 (SV1.5) -> PD6 (SV1.10)
    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
2026-09-23 Confirm display LDO chip: 6206A (Torex XC6206P332MR), SOT-23-3
    Read directly off the physical part on U8. Fixed 3.3V output, 200mA -
    confirms VCC can be fed 5V (module regulates it down itself), matching
    what the wiring docs already assumed. Also fixes the package guess:
    SOT-23-3, not SOT-223 as TFT_3.5_board.md previously guessed.
2026-09-23 Display: confirm ST7796S on real hardware, close out the ID question
    Boot log on the real board: RDID4 returned garbage (00 3B CB 00 -
    neither the clean 0/FF pattern the smoke test flags nor a valid ID),
    consistent with a noisy/floating SDA-O rather than a wrong controller.
    Visual confirmation instead: R/G/B/white fills, test pattern correct
    in all 4 rotations, and the final screen (colour bars + checkerboard +
    grey block with live counters) all rendered exactly as intended - no
    inversion, no swapped colours. A real ILI9488 would very likely have
    shown garbled output under this ST7796S-specific 16bpp/gamma init, so
    this is good practical confirmation the panel is ST7796S-compatible.
    Co-Aut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
2026-09-23 Display: add a 5x7 bitmap font and a live network-status screen
    st7796s.c/.h (driver layer):
    - New ST7796S_DrawChar()/ST7796S_DrawString(): a hand-authored 5x7
    bitmap font covering space, '.', ':', '-', '/', digits 0-9 and
    uppercase A-Z - exactly what a status/diagnostic screen needs.
    Unsupported characters draw as a blank cell instead of garbage.
    Each font row is run-length-encoded into FillRect() calls (not one
    fill per pixel), and ST7796S_CharPitch() exposes the per-character
    advance so callers can lay out fixed-width fields without
    hardcoding the glyph width.
    tft_app.c/.h (app layer):
    - TFT_App_SmokeTest() now finishes into an operational status screen
    (title + LINK/DHCP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
    [main.c, st7796s.c, tft_app.c]
2026-09-23 Display: show the last TCP message received for 2 seconds
    tcp_echo_client.c/.h:
    - New s_last_rx snapshot (independent of the existing s_rx_buf UART
    drain path) taken at the same point data is pushed to the debug
    UART, so neither path can affect the other.
    - tcp_echo_client_take_last_rx(buf, buf_size): hands out each received
    chunk exactly once, NUL-terminated. main.c-only, not ISR-safe (same
    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
2026-09-23 Display: fix color inversion, extend font, fix rotation-reset regression
    Three separate bugs found from a single hardware photo of the status
    screen (title showed blue instead of yellow, labels black instead of
    white, values red instead of cyan - and LAST MSG:'s value looked like
    scattered single letters):
    1. st7796s.c: ST7796S_Init() called CMD_INVON; this panel needs
    CMD_INVOFF - every colour was coming out as its exact bitwise
    inverse. Latent since the very first smoke test; a solid-fill test
    doesn't make an inverted colour as obvious as text does, so nobody
    had actually confirmed a fill was the *right* hue, just that fills
    changed.
    2. st7796s.c: font5x7 only had uppercas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
    [st7796s.c, tft_app.c]
2026-09-23 Display: show the full multi-line received message, not just line 1
    TFT_App_ShowReceived() previously truncated at the first CR/LF and to
    one STATUS_RX_CHARS-wide row - a 3-line server reply ("Hello Module
    #49 ! I am module #59...", "1234567890", "Hello PC R91 !") only ever
    showed its first line.
    Now: split on the server's own line breaks (CR, LF, or CRLF/LFCR as
    one), then wrap each of those source lines to STATUS_RX_CHARS-wide
    screen rows by character count, across up to STATUS_RX_MAX_ROWS (7)
    rows below the LAST MSG: label. Anything past that is dropped rather
    than overflowing into the heartbeat square. A shorter new message
    blanks whatever trailing rows the previous one used (s_rx_rows_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
    [main.c, tcp_echo_client.c, tft_app.c]
2026-09-23 Display: multi-page screen (SETUP/RECEIVED/RESERVED), page button on PC6
    Splits the single combined status screen into 3 pages, cycled by a
    physical button:
    1/3 SETUP - LINK/DHCP/IP/SERVER/TCP/UPTIME/FRAME (unchanged content,
    what used to be the only screen)
    2/3 RECEIVED - the last TCP message, full multi-line text
    3/3 RESERVED - placeholder ("RESERVED FOR FUTURE USE"), demonstrates
    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
2026-09-23 Display: show the chip's unique 96-bit ID on the SETUP page
    STM32F4 has a factory-programmed 96-bit unique device ID in OTP at a
    fixed address (0x1FFF7A10, three consecutive 32-bit words - RM0090
    section 39.1). stm32_uid_word() reads it directly (memory-mapped,
    read-only, no peripheral clock or init needed).
    New CHIP ID: row on the SETUP page, hex, drawn once (like SERVER:/
    FRAME: - it's read-only OTP, never changes at runtime). 24 hex digits
    don't fit one 16-char-wide value field, so split across two rows
    (16 + 8 digits). Also logged to USART1 at boot ("[tft] chip UID = ...")
    alongside the other one-shot smoke-test diagnostics.
    Verified with a clean cmake --build (FLASH 16.85%, no new war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
    [tft_app.c]
2026-09-23 Display: show CRC32 of the chip ID instead of the raw 24-hex value
    The full 96-bit UID doesn't fit one 16-char value field (needed two
    screen rows) and part of it (LOT_NUM) often looks like plain decimal
    text rather than "random" hex, which is inconvenient as a short board
    identifier. A CRC32 over the UID's 12 raw bytes fixes both: fits one
    line (8 hex digits), and evenly distributes whatever structure was in
    the source bytes.
    Standard reflected CRC-32 (poly 0xEDB88320, init/final XOR
    0xFFFFFFFF) - same algorithm as zlib's crc32()/Python's
    binascii.crc32()/`cksum`, so it can be independently verified against
    the full ID, which is still logged in full over UART alongside the
    CRC32: "[tft] ch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
    [tft_app.c]
2026-09-23 New Config/ module: persisted settings + TCP configurator (port 7000)
    Replaces tcp_echo_client.h's compile-time-only TCP_ECHO_SERVER_IP0..3/
    PORT constants - changing the server address used to need a full
    rebuild+reflash. Now settable at runtime over the LAN, no serial cable
    needed (matches how the module is normally deployed: on the same
    router/switch as the configuring computer).
    Config/Inc+Src/device_config.h+.c:
    - DeviceConfig struct (server ip:port, device name, static-IP-vs-DHCP
    choice + its ip/netmask/gateway) persisted in the last Flash sector
    (11, 0x080E0000, 128 KB) - deliberately as far from the firmware
    image (~176 KB/17%) as possible, not just the next free sector,
    so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
    [device_config.c, main.c, tcp_echo_client.c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]
2026-09-23 Config: add interactive PowerShell client (no PuTTY/netcat needed)
    Neither is installed on this machine, and typing raw commands into a
    one-shot TcpClient script each time (as used to test config_server.c
    live) isn't practical for actual day-to-day use. scripts/config-client.ps1
    is a small interactive REPL: connect, print the READY banner, then
    loop reading a line, sending it with CRLF, printing the reply, until
    "exit" or the module closes the connection (REBOOT does this on
    purpose - message is intentional, not an error).
    Verified live: connected to the real module, ran GET, got the expected
    config dump back.
2026-09-23 clangd: also allow the 8.3 short path of the Arm toolchain in --query-driver
    CMake's Ninja generator on Windows writes compiler paths that contain
    spaces in their 8.3 short form (C:\PROGRA~2\Arm\GNUTOO~1\bin\AR19DD~1.EXE
    for "C:\Program Files (x86)\Arm\GNU Toolchain ...\arm-none-eabi-gcc.exe"),
    regardless of which shell runs the configure. The existing
    "arm-none-eabi-*" glob never matched that, so clangd refused to query
    the driver and fell back to the host x86_64-pc-windows-msvc target -
    the "Unsupported option '-mcpu='" / "'string.h' not found" noise on new
    files like Config/Src/device_config.c. The real build was unaffected.
2026-09-23 Config: web settings page on port 80; fix lwIP PCB-list ring after ETH reset
    Web page (Config/Src/config_http.c): http://<module IP>/ shows a pre-filled
    form (name, TCP server IP/port, DHCP/static IP). Save validates every field
    before applying and persisting; name and server apply immediately (display
    SERVER:/NAME: refresh via TFT_App_UpdateInfo(), echo client reconnects via
    tcp_echo_client_restart(), both driven by device_config_revision()); IP mode
    changes need the page's Reboot button. MEMP_NUM_TCP_PCB 4->8 for browser
    parallel connections.
    Bug found while testing: the module stopped answering with the CPU spinning
    in tcp_input() over tcp_tw_pcbs - two port-80 TIME_WAIT pcbs linked into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
    [device_config.c, ethernetif.c, main.c]
2026-09-23 Build: zero-warning clean build; stop regeneration from wiping the CMake cache
    - Vendor-code warning suppression now covers the whole HAL driver directory
    (glob) instead of a hand-picked list - stm32f4xx_hal_flash_ex.c (Config/)
    and stm32f4xx_hal_spi.c (Display/) were added later and missed it.
    - lwIP: -Wno-stringop-overflow for GCC 12+'s false positive in dhcp.c
    dhcp_option_byte() (write is bounds-checked by the LWIP_ASSERT above it).
    - toolchain-arm-none-eabi.cmake: compilers set with plain set() instead of
    CACHE ... FORCE. With FORCE, every automatic regeneration after a
    CMakeLists.txt edit reset the cached full compiler path to the bare name,
    CMake treated that as a compiler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
2026-09-24 Config: web settings table with Save/Cancel/Restart; default IP when no DHCP
    Web page (http://<module IP>/) is now a table: parameter | example | current
    value | new value. Empty input = keep. Save validates and writes to Flash
    only (device_config_store()), active after the next restart - the current
    column shows "после рестарта: ..." for pending values. Cancel leaves without
    changes, Restart writes and reboots (redirects to the new static IP).
    DHCP mode: if no DHCP server answers within 10 s the module takes the static
    IP field as its default IP (192.168.1.100/24 out of the box, shown as
    "DHCP: NO-DEFAULT IP"), keeps retrying DHCP every 30 s, and reboots after
    60 s on it unles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
    [device_config.c, main.c, tcp_echo_client.c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]
2026-09-24 Docs: large display options for this board (theory, not implemented)
    Display/docs/LARGE_DISPLAY_OPTIONS.md: F407 has no LTDC/video out, ~60 KB
    free RAM and only SPI3 on SV4, so the practical maximum is a 10.1"
    1024x600/1280x800 panel with its own graphics controller (RA8876/RA8889,
    EVE BT817/818, DWIN/Nextion UART HMI). 1920x1080 only via a Raspberry Pi
    showing the module's web page in a kiosk browser; notes on developing for
    Pi 3/4/5 from this environment.
2026-09-24 Panel: instrument pages REMOTE and LOCAL with demo data
    New Panel/ module: two TFT pages of widgets - analog gauges (240-degree
    scale, normal/warn/alarm zones), digital readouts, sliders, vertical bars,
    lamps and buttons - laid out from static tables in panel_pages.c. Each
    widget shows a channel (fixed-point tenths) set via Panel_SetChannel();
    until real data arrives a built-in demo (PANEL_DEMO) animates it. UPTIME on
    LOCAL is real.
    - Panel/Src/gfx.c: lines with thickness, circles, arc bands, rounded
    rects, centred text on top of ST7796S_FillRect(); integer maths only.
    - Panel/Src/panel.c: static part drawn once, then only changed widgets
    redrawn, at most one per Panel_Poll() call so Et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
    [st7796s.c, tft_app.c]
2026-09-24 TFT: SPI3 at 20 MHz; drop boot-time RDID4 readback
    Prescaler /4 -> /2 (SPI3 ceiling on F407). Full-screen fill measured
    at 131 ms on hardware (was ~250 ms). The display is now write-only at
    boot; ST7796S_ReadID() stays in the driver for manual debugging.
2026-09-24 TFT: DMA for large fills (DMA1 Stream5, SPI3 TX)
    Fills of 256+ px go out by DMA: SPI switched to 16-bit frames, DMA
    re-sends one colour word with memory increment off, no pixel buffer.
    FillRect() returns once started; the next driver call waits for it,
    ST7796S_WaitIdle() for explicit sync. Small fills stay blocking.
    SPI3_IRQn stays off: in 2-line mode the unread RX raises OVR every
    other frame, which with HAL's ERR interrupt would fire every ~1.6 us.
    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
2026-09-24 Diag: main-loop load stats (UART + TFT CPU page); faster text drawing
    New Diag/ folder for diagnostic features, switched in diag_config.h
    (DIAG_ENABLE master + one define per feature; off = empty inline stubs,
    CPU page drops out of the page cycle). First feature, diag_cpu: DWT
    cycle counts per main-loop section (ETH, LWIP, TCP, HTTP, TFT, OTHER),
    loops/s and longest pass, every 5 s to USART1 and on a 1 s CPU page.
    It showed the TFT holding the loop for 54 ms once a second. Fixed by:
    - ST7796S_DrawString/DrawChar: whole string as one RAM window streamed
    line by line, instead of a CASET/RASET/RAMWR per pixel run (~20 per
    glyph at scale 2).
    - TFT_App_AlivePoll: live rows redrawn one per ca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
    [diag_cpu.c, main.c, st7796s.c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]
2026-09-24 ETH: detect link-down again; no ETH reset/reboot while the cable is out
    ethernetif_poll_link() only polled the PHY in HAL_ETH_STATE_READY, but
    HAL_ETH_Start_IT() moves the handle to STARTED - so once the link had
    come up it was never polled again. A pulled cable (RJ45 LEDs off) left
    the netif LINK_UP with phy=2 frozen in the heartbeat and on the TFT.
    Now polls in READY or STARTED.
    With link-down actually seen, the netif loses its IP, and the main.c
    "no IP" watchdog would reset ETH after 15 s and reboot the MCU after
    30 s. It now holds off while the link is down (unless ETH init itself
    failed); the timer restarts when the link returns.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
    [ethernetif.c, main.c]
2026-09-24 CAN: CAN1 driver on J3 (receive, log, send API)
    New CAN/ folder: register-level bxCAN driver (no HAL CAN module in the
    project) for CAN1 on PA11/PA12 -> TCAN1044V (U3) -> J3.
    - 500 kbit/s by default, prescaler derived from the real APB1 clock,
    sample point ~87.5 %; optional listen-only mode (CAN_SILENT).
    - Accept-all filter (std + ext) into FIFO0, RX interrupt -> queue ->
    can_bus_poll(): rate-limited UART log, app handler hook, bus state
    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
2026-09-24 TFT: PWM backlight brightness + idle dimming, set from the web page
    - Backlight BL (PC7) now PWM on TIM3_CH2, 10 kHz, register level.
    Level is perceived brightness: duty = level^2 / 100 %.
    - device_config v2 adds bl_level (100 %), bl_dim_level (20 %) and
    bl_dim_min (5 min). A v1 config in Flash is migrated at boot (all v1
    settings kept) and written back as v2.
    - Web settings page: three new rows, applied at once on Save (copied
    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
2026-09-24 Diag: CAN1 silent-loopback self-test
    DIAG_CAN_LOOPBACK (on for now): the CAN driver runs in bxCAN silent
    loopback (new can_bus_set_loopback()); a numbered frame every second,
    alternately 11- and 29-bit id, must come back intact within 100 ms.
    Result to USART1 every 5 s. Checks driver, timing, filter, IRQ and
    queue - not the transceiver or wiring. While on, the real bus on J3 is
    not used. Verified on hardware: PASS, 0 lost / 0 bad.
2026-09-24 DMA for debug UART and TFT text: longest loop pass 3.6 ms -> ~0.4 ms
    - Debug output: 4 KB ring drained by DMA2 Stream7 (USART1_TX).
    Debug_Print() and the former direct HAL_UART_Transmit() callers
    (ethernetif, tcp_echo_client, MSP) copy and return; HardFault stops
    the DMA and prints synchronously.
    - TFT text: the string's pixel lines are streamed by DMA from two line
    buffers; the SPI-complete interrupt starts the next line and renders
    the one after it meanwhile. DrawString() returns in ~20 us.
    - ST7796S_Busy(): the SETUP/CPU row sweep, CLOCK page and Panel_Poll()
    skip a pass while the bus is busy instead of waiting.
    Measured on hardware: max pass 3.6 ms -> ~400 us, TFT max 205 us.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
    [debug_uart.c, ethernetif.c, main.c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]
2026-10-04 Keypad: I2C1 slave receiver for the 4x4 keypad module, TFT pages, page keys
    - Keypad/: I2C1 slave 0x30 on SV5 (PB6/PB7), register level, CRC + tail-byte
    ACK, packet queue, seq checks, log to USART1; protocol copy kbd_protocol.h
    - TFT page "I2C KBD 0x30": packets line by line, RX/OK/ERR counters
    (new addr/bus_err stats); "KBD HELP" legend page; '*' glyph in the font
    - Keypad input wakes the backlight (any valid packet except START)
    - Page keys: '#' next page, 1-3 digits + '#' that page
    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

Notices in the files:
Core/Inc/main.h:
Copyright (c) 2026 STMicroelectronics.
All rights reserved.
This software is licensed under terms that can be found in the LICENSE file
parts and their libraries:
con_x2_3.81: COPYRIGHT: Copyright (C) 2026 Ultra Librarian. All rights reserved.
